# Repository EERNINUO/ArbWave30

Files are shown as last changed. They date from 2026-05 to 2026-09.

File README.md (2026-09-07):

<div align="center">

<!-- Assisted-by: DeepSeek - 文档框架 -->

# ArbWave30
30MHz 任意波形发生器 | FPGA + 高速DAC | SCPI 可控 

<p align="center">
  <a href="https://github.com/EERNINUO/ArbWave30" style="margin: 2px;">
    
  </a>
  <a href="https://github.com/EERNINUO/ArbWave30" style="margin: 2px;">
    
  </a>
  <a href="https://github.com/EERNINUO/ArbWave30" style="margin: 2px;">
    
  </a>
  <br/>
  <a href="https://raw.githubusercontent.com/EERNINUO/ArbWave30/main/LICENSE" style="margin: 2px;">
    
  </a>
  <a href="https://raw.githubusercontent.com/EERNINUO/ArbWave30/main/LICENSE" style="margin: 2px;">
    
  </a>
    <a href="https://raw.githubusercontent.com/EERNINUO/ArbWave30/main/LICENSE" style="margin: 2px;">
    
  </a>
  <!-- <a href="https://github.com/EERNINUO/ArbWave30/releases" style="margin: 2px;">
    <img src="https://img.shields.io/github/v/release/EERNINUO/ArbWave30?color=blueviolet&include_prereleases" alt="发布版本">
  </a> -->
</p>
</div>

---

> **⚠️ 注意**：你当前查看的是 **develop** 开发分支，内容可能不稳定。
> 推荐使用稳定发布版本：[查看 Releases](https://github.com/EERNINUO/ArbWave30/tree/releases)

## ✨ 特性

### 硬件指标（V1.0）
- 波形：正弦、方波、三角波、噪声波、直流
- 正弦波最高 **30MHz**，方波最高 **5MHz**
- 电压范围（高阻）：20Vpp（DC\~10MHz），14Vpp（10\~20MHz），10Vpp（20\~30MHz）
- 幅值分辨率：2mV（典型），偏移范围 ±10V
- 总谐波失真（THD）：< -50dBc @10MHz 满幅（目标值）
- 相位噪声：-100dBc/Hz @10kHz offset（30MHz 载波）（目标值，受限于测试条件，目前无法标定）
- 输出阻抗：50Ω
- 参考时钟：内部 TCXO（±1ppm）或外部 10MHz 输入

### 控制与接口
- USB 2.0（USB CDC 类），支持 SCPI-1999 命令集
- SMA 输出，SMA 触发 I/O，SMA 外部时钟输入
- 电源输入：24V DC，功耗 <24W

### 软件与扩展路线
- V1.0：单通道 + 基础波形 + 核心 SCPI
- V2.0：双通道 + 调制 + 扫频
- V3.0：Linux GUI + 任意波（16kpts）

---

## 🚦 项目状态

> **当前阶段：MVP 硬件、MCU/FPGA 核心程序验证完成，已能通过 SCPI 控制输出，正在进行模拟前端进一步调优**

### ✅ 已完成
- [x] PCB 设计与打样（4层板，信号完整性设计）
- [x] 模拟前端调试通过 
- [x] DAC 上电参数配置正常（SPI 接口通信稳定）
- [x] 正弦 DDS 核（IP 核实现，48位相位累加器）
- [x] 方波/直流/三角波/噪声波生成
- [x] 幅度控制模块
- [x] 相位控制模块
- [x] SPI Slave 通信接口与寄存器组
- [x] 模拟板驱动库（MCU 端）
- [x] SCPI 协议栈移植
- [x] 7阶椭圆滤波器焊接调试
- [x] 输出性能粗略标定（THD、SFDR）

### 🏗️ 开发中
- [ ] 软件幅度校准
- [ ] 谐波性能优化

### 📋 待办（MVP 之后）
- [ ] 滤波器性能优化（重构滤波器，调整群延时，减少快速边沿的过冲/振铃）
- [ ] 模拟板完整版设计（加入 硬件幅度控制、直流偏置、外部触发、外部时钟输入）
- [ ] 输出性能精确标定（需要专业频谱仪，目前无法进行）
- [ ] 上位机控制软件

### 📸 当前进展

**正弦波输出（SDS824X HD 示波器实测）：**

**正弦波满幅输出波形：**
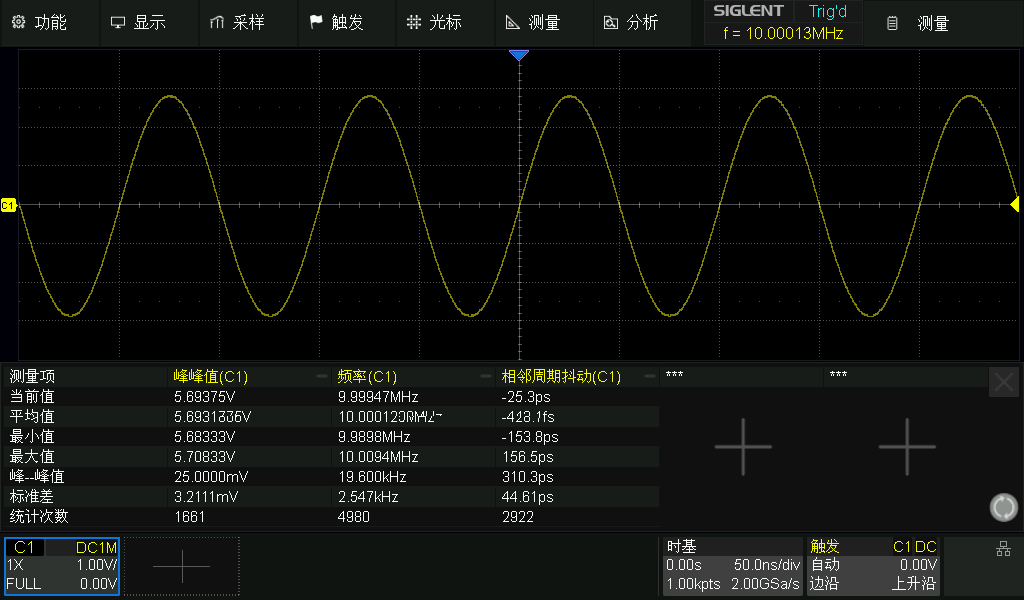
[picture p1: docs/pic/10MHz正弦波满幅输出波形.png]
10MHz正弦波满幅输出波形

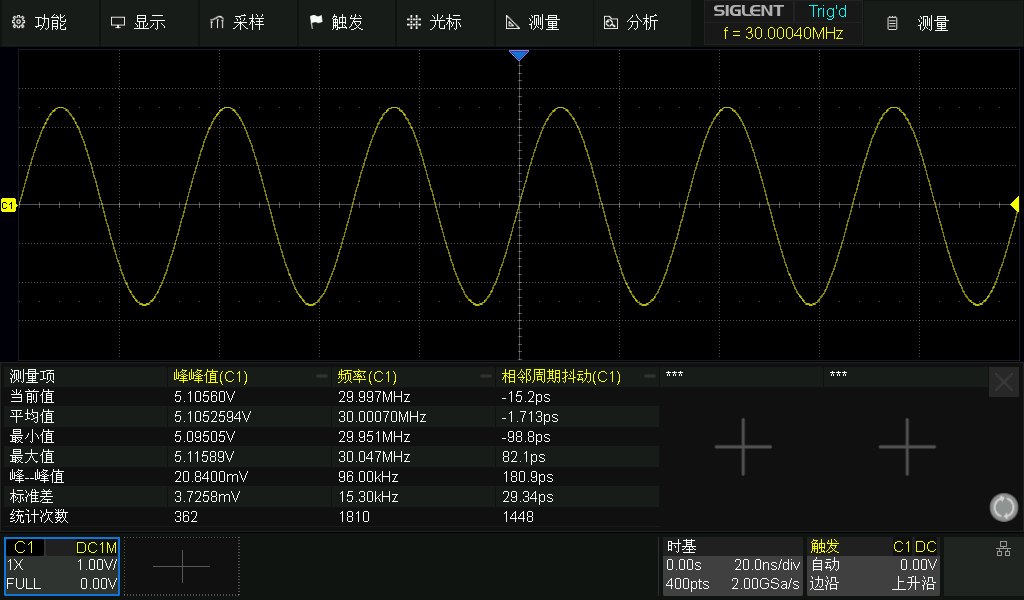
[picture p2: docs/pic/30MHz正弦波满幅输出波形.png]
30MHz正弦波满幅输出波形


**方波满幅输出波形：**
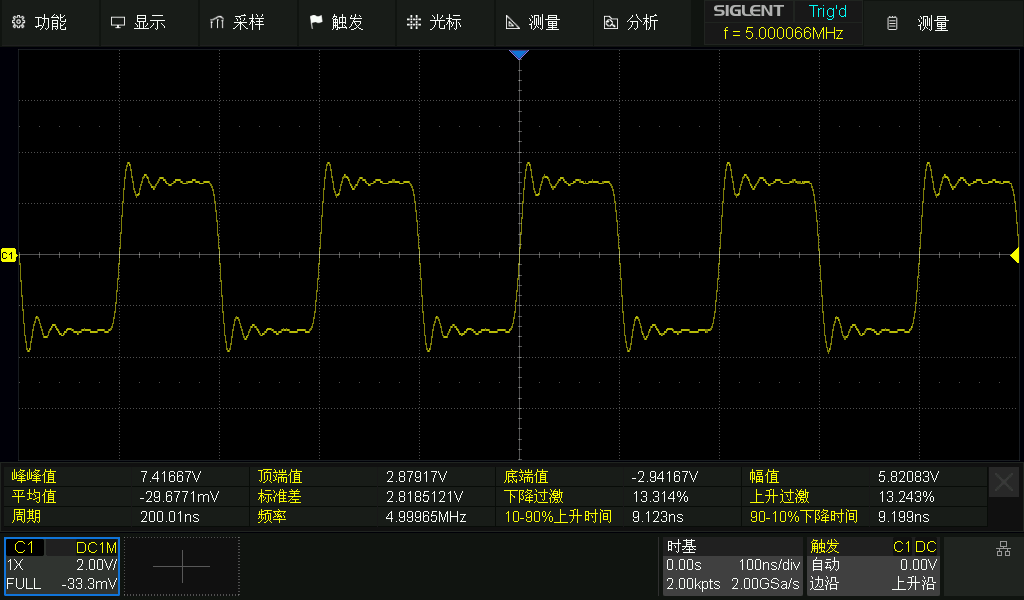
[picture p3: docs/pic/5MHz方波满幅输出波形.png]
5MHz方波满幅输出波形

> 当前版本方波有约 13.5% 的过冲，为滤波器群延时特性所致，后续将通过优化通道设计解决，详见[重构滤波器调试笔记](docs/设计笔记/重构滤波器调试笔记.md)。

**10MHz正弦波FFT结果：**

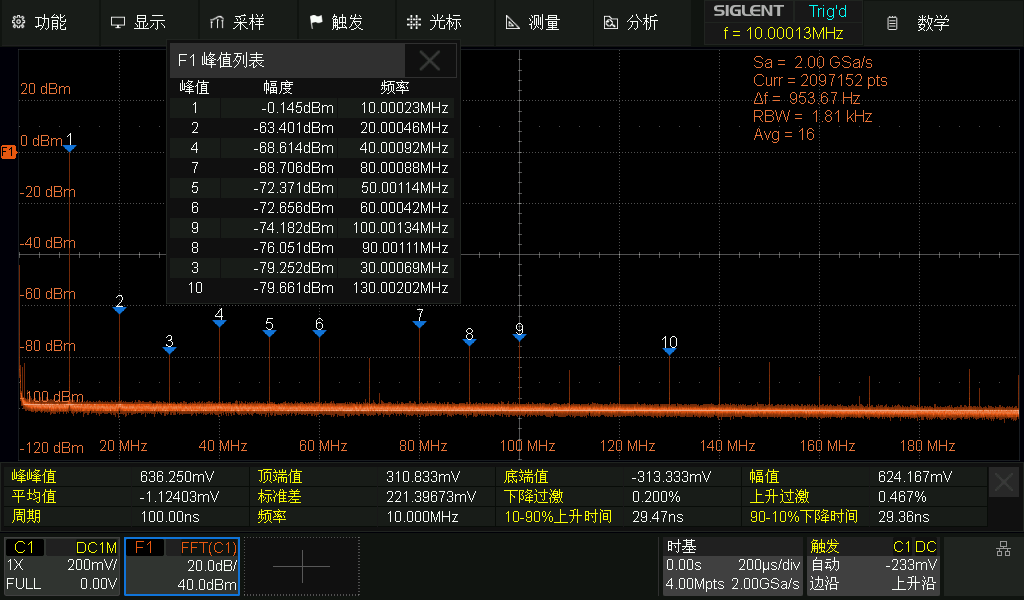
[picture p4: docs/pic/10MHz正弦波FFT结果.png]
10MHz正弦波FFT结果


经上图数据可计算出[^1]：
  THD ≈ -60.2 dBc @10MHz，
  SFDR[^2] ≈ 63.26 dBc @10MHz

[^1]: 由于示波器自身产生的谐波不可忽略，该值仅供参考，实际值需频谱分析仪复测。

[^2]:SFDR 分为两种定义：1、含谐波；2、不含谐波。由于表中没有非谐波分量，故采用第一种定义。

---

## 🧱 仓库结构
```text
ArbWave30/  
├── docs/ # 设计文档  
│    ├── pic/ # 文档图片  
│    ├── adr/ # 决策记录  
│    ├── 硬件设计文档/ # 硬件设计文档  
│    ├── 设计笔记/ # 设计笔记
│    ├── 用户手册/ # 用户手册  
│    └──  LICENSE # CC BY-SA 4.0  
├── hardware/ # 原理图、PCB源文件 （🚧 开发中）   
│    ├── analog_board/ # 模拟板 PCB设计  
│    ├── control_board/ # 控制板 PCB设计  
│    └── LICENSE # CERN-OHL-S-2.0   
├── firmware/ （🚧 开发中）   
│    ├── fpga/ # FPGA 设计源代码（Verilog）  
│    │    ├── Application/ # 项目代码   
│    │    └── FPGA_Test_Hardware/ # FPGA 硬件测试代码   
│    │         ├── FPGA_Clock_Test/ # 时钟测试代码   
│    │         └── FPGA_Hardware_Test/ # FPGA 硬件测试代码   
│    ├── mcu/ # MCU 固件源代码（C/C++）   
│    │    ├── Application/ # 项目代码   
│    │    ├── MCU_Test_Hardware/ # MCU 硬件测试代码   
│    │    │    └── min_system_test/ # MCU 最小系统测试代码   
│    │    └── SCPI_Test/ # SCPI-parser 移植测试工程   
│    └── Clock_Generator_Config/ # 时钟发生器配置     
├── simulink/ # LTspice 仿真文件  
├── datasheets/ # 组件数据手册，参考设计  
├── scripts/ # 自动化测试脚本（PyVISA）（🚧 开发中）  
│    ├── test_filter/ # 滤波器测试脚本  
│    └── test_diff_to_single # 差分转单端输出测试脚本   
├── LICENSE # GPL-3.0  
└── README.md  
```
---

## 🚀 快速开始

> 项目处于 **最小可行产品（MVP）验证阶段**，正在进行软硬件联调，待 MVP 验证完成后，将提供：
> - 打样 PCB 的 Gerber 文件及 BOM
> - FPGA 比特流烧录方法（通过 JTAG 加载）
> - 固件编译与升级步骤

当前你可以浏览 `docs/` 中的设计文档，了解详细的技术规格和设计思路；
或查看 `hardware/` 中的原理图和 PCB 设计文件与 `firmware/` 中的代码框架，了解硬件与软件的构成，并提出您的宝贵意见。

---

## 📡 SCPI 命令示例 

```python
import pyvisa

# 1. 指定纯 Python 后端（无需安装 NI-VISA 驱动）
rm = pyvisa.ResourceManager('@py')

# 2. 列出所有资源，找到你的 COM 口（通常是 'ASRL3::INSTR' 类似格式）
# print(rm.list_resources())

# 3. 打开串口资源，并配置终止符
inst = rm.open_resource('ASRL3::INSTR')  # 请替换为实际的 ASRL 端口号
inst.baud_rate = 115200        # 串口波特率，对于 USB CDC 类设备并不重要
inst.read_termination = '\n'   # 非常重要：库默认是 '\n'，但最好显式声明
inst.write_termination = '\n'  # 发送时自动追加换行符

# 4. 现在你可以像用 USBTMC 仪器一样使用 query
print(inst.query('*IDN?'))
inst.write('SOUR:FREQ 1000')
inst.write('SOUR:STAT ON')

# 5. 查询
freq = inst.query('SOUR:FREQ?')
print(f"Freq: {freq}")

inst.close()
```

完整命令集参见 [docs/SCPI_reference.md](</docs/用户手册/SCPI 参考手册.md>)。

## 🧪 自动化测试
测试脚本位于 `scripts/`（持续更新中），使用 PyVISA 与设备通信。你可以运行对应的脚本进行自动化测试，或者根据你的需求，参考这些脚本自行编写测试用例。

## 📄 文档
设计文档、测试报告和用户手册位于 `docs/`，持续更新中。

## 📅 版本路线图 
| 阶段 | 功能 | 描述 |
|---|---|---|
| V1.0 | 单通道，基础波形（正弦、方波、三角、噪声、DC）| 支持频率、幅值、偏置、相位连续可调；支持SCPI命令（少量核心指令）|
| V2.0 | 双通道 | 增加第二路输出，支持频率/相位同步，相位差可调 |
| | AM调制 |内/外部调制源，调制深度0\~100% |
| V3.0 | 嵌入式GUI | 基于Linux + LVGL，通过LCD触摸屏直接控制
| | 任意波 | 支持用户自定义波形表，存储深度≥16kpts |

## 📜 许可证
Copyright © 2026 EERNINUO

本项目采用**多许可证策略**，不同部分适用不同许可证：

| 组成部分 | 许可证 |
|---|---|
| 固件 （MCU/FPGA 代码） | [GNU General Public License v3.0](LICENSE) |
| 硬件设计文件 （原理图、PCB、BOM） | [CERN Open Hardware Licence Version 2 - Strongly Reciprocal](hardware/LICENSE) |
| 文档、图片、README | [Creative Commons Attribution-ShareAlike 4.0 International](docs/LICENSE) |

这意味着：
- 你可以自由使用、修改、分享固件代码，但任何衍生代码也必须以 GPL-3.0 开源。
- 你可以基于硬件设计文件制作、分发物理设备，但必须同时开源你对设计文件的修改，并保留署名。
- 你可以复制和修改文档，但必须同样以 CC BY-SA 4.0 分享，并注明原作者。

**商标声明**：`ArbWave30` 名称及标志未经授权不得用于商业产品。

## 🤖 AI 辅助声明

本项目文档框架由 GitHub Copilot / DeepSeek 辅助生成。
作者已逐一审查并测试，但如有任何问题欢迎提交 Issue。

## ⚠️ 免责声明
注意：本项目为个人学习与开源作品，不保证商业级可靠性。使用前请仔细阅读免责声明。

## 📫 联系方式
项目主页: https://github.com/EERNINUO/ArbWave30

## ⭐ Star History
如果您觉得这个项目有帮助，请给一个 Star ⭐，谢谢！

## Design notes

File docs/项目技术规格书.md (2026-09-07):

<!------------------------------------------------------------------------
SPDX-License-Identifier: CC-BY-SA-4.0
Copyright (C) 2026 [EERNINUO]

This work is licensed under the Creative Commons Attribution-ShareAlike 4.0 International License. 
To view a copy of this license, visit http://creativecommons.org/licenses/by-sa/4.0/.
------------------------------------------------------------------------->

<!-- Assisted-by: DeepSeek - 文档框架 -->

# ArbWave30 - 技术规格书

| 文档编号 | ArbWave30-SRS-001 | 版本 | V1.2 |
|---|---|---|---|
| 项目名称 | ArbWave30 | 日期 | 2026-04-06 |
| 起草人 | EERNINUO | 状态 | 草案 |

## 1. 概述
本设备是一款基于高云FPGA和高速DAC的数字合成信号源，为解决作者在学习实践中缺少高速信号源的问题而启动，旨在提供高精度、宽带宽的可编程波形输出。支持USB远程控制，并可扩展外部参考时钟输入，适用于实验室测试、教学演示及嵌入式系统调试等场景。

## 2. 引用文档与标准

|文档/标准 | 编号 |	说明 |
|---|---|-----|
| SCPI标准	| SCPI-1999 |	可编程仪器标准命令集 |
| USB设备类 | USB TMC 1.0 | USB-TMC协议 |
| IEEE 488.2 | IEEE Std 488.2-1992	| 仪器响应格式 |

## 3. 电气参数（电气规格表）

### 3.1  输出特性（主通道）

| 参数 | 符号 | 最小值 | 典型值 | 最大值 | 单位 | 条件/备注 |
|---|---|---|---|---|---|---|
| **波形类型** | – | 正弦、方波、三角波、噪声波、直流 | – | – | – | 后续固件升级支持任意波 |
| **正弦波最大频率** | f_sine_max | – | – | 30 | MHz | – |
| **方波最大频率** | f_sqr_max | – | – | 5 | MHz | 上升/下降时间 < 50ns |
| **其他波形最大频率** | f_other_max | – | – | 5 | MHz | 三角波、噪声波 |
| **频率分辨率[^1]** | Δf | – | 1 | – | μHz |  |
| **频率精度** | – | – | ±1 | – | ppm | 24小时内，基准为温补晶振（TCXO） |
| **相位噪声** | L(f) | – | -100 | – | dBc/Hz | @10kHz偏移，30MHz载波，目标值 |
| **总谐波失真** | THD | – | -55 | -50 | dBc | f_sine ≤ 10MHz，满幅输出 |
| **无杂散动态范围** | SFDR | – | 65 | – | dBc | f_sine ≤ 30MHz，> 1MHz时 < 60dBc |
| **输出噪声RMS** | V_noise | – | < 3 | – | mV RMS | 0V输出，DC~30MHz 50Ω负载 |

[^1]: 频率分辨率指DDS模式下的最小频率步进，实际频率精度受时钟稳定性影响。

### 3.2 幅值与分辨率（高阻输出模式）

| 频率范围 | 幅值范围[^2]（Vpp） | 最大偏移量[^3] | 分辨率 | 绝对精度 |
|---|---|---|---|---|
| DC ~ 10 MHz | 0 ~20 | ±10 V | 2 mV（典型，最差 5 mV） | ±（1% + 2mV） @1kHz |
| 10 MHz ~ 20 MHz | 0 ~ 14 | ±7 V | 2 mV（典型，最差 5 mV） | ±（2% + 2mV） |
| 20 MHz ~ 30 MHz | 0 ~ 10 | ±5 V | 2 mV（典型，最差 5 mV） | ±（2% + 2mV） |

[^2]: 50Ω下幅值范围为高阻状态下的1/2
[^3]: 注意，偏置电压加上幅值需小于对应频率下0偏置时的最大幅值

### 3.3 方波特性（高阻，5MHz）

| 参数 | 目标值 | 单位 |
|---|---|---|
| 上升/下降时间 （10% ~ 90%） | < 50 | ns |
| 过冲（目标） | < 5 | % |
| 抖动 （RMS）（目标） | < 500 | ps |

### 3.4 扫描与调制（后续实现）

| 功能 | 参数 | 目标 |
|---|---|---|
| 线性/对数扫频 | 起始/终止频率 | 1μHz ~ 30MHz |
| AM调制 | 调制频率 | 1Hz ~ 100kHz，调制度0~100% |

### 3.5 时钟特性

| 参数 | 典型值 | 幅度 | 备注 |
|---|---|---|---|
| 内部参考频率 | 10 MHz | \ | TCXO，初始精度 ±1ppm，老化 ±1ppm/年 |
| 外部参考输入 | 10 MHz | 3.3V | ±10ppm，0~10dBm，SMA接口 |
| 参考输出 | 10 MHz | 3.3V | LVCMOS33，SMA |

### 3.6 触发输入/输出

| 参数 | 幅度 | 备注 |
|---|---|---|
| 多功能输入 | 3.3V/5V兼容 | SMA |
| 多功能输出 | 3.3V | SMA |

### 3.7 电源与环境

| 参数 | 规格 |
|---|---|
| 直流输入电压 | 24 V DC |
| 功耗 | < 20 W（预估） |
| 工作温度 | 0 ~ 40 ℃ |
| 存储温度 | -20 ~ 70 ℃ |
| ESD防护 | 接触放电 ±4 kV（输出BNC加TVS） |

## 4. 功能要求

### 4.1 基础功能
- 产生正弦、方波、三角波、噪声波、直流
- 可设置频率、幅值、偏移、相位
- 支持输出开关（ON/OFF），断电后恢复最后设置（存储于EEPROM）

### 4.2 调制与扫频（V2版本实现）
- AM：内/外调制，调制频率/深度可设
- 线性/对数频率扫描

### 4.3 任意波功能（V2版本实现）
- 用户自定义波形点数：最大 16kpts（14bit分辨率）
- 通过上位机软件或SCPI命令下载波形数据

### 4.4 外部接口
- USB 2.0（USBTMC或CDC类）用于远程控制和波形数据传输
- 波形输出：SMA接口，50Ω/高阻切换
- 外部参考时钟输入（10 MHz，SMA接口）
- 触发输入/输出（SMA）
- 电源输入（DC2.1mm 24~36 V）
- 可选：LAN接口（后续实现）

### 4.5 远程控制（#远程控制）
- 接口：USB 2.0 （USB-CDC类）
- 命令集：符合SCPI-1999标准，至少包含以下子系统：
  - `*IDN?`, `*RST`, `*CLS`
  - `SOURce`：FREQuency, VOLTage, VOLTage:OFFSet, FUNCtion, PHASe
  - `OUTPut`：STATe, IMPedance, LOAD
  - `TRIGger`：SOURce, SLOPe
  - `SYSTem`：ERRor?
  - `SOURce`:TRACe:DATA?
- 响应格式：`<header><value><terminator>`，支持查询与设置

### 4.6 用户界面（长期扩展）
- 可选：通过USB连接PC运行简易GUI（Python+PyQt）
- 可选：后续移植至Linux板卡（运行本地GUI）

## 5. 硬件架构要求

### 5.1 主要IC选型（初步）
| 模块 | 型号 | 关键参数 | 功能说明 |
|---|---|---|---|
| FPGA | 高云GW2AR-LV18 | 逻辑资源 > 20k LUTs，支持PLL | DDS核心，时钟管理，数据处理 |
| MCU | STM32F411 | 32位ARM Cortex-M4处理器, 96MHz主频 | 系统控制，USB通信，用户接口 |
|时钟发生器| CDCI6214 | 4输出，支持外部参考 | 提供DAC时钟和系统时钟 |
| DAC | AD9747 | 16bit, 最大250MSPS, 双通道 | 波形生成核心，支持高精度输出 |
| 重构滤波器 | 7阶椭圆LPF | 截止频率60MHz，通带纹波<0.5dB | 滤除DAC采样频率成分，改善波形质量 |
| 差分放大器 | LMH6609 | 电流反馈运算放大器、带宽>410MHz | 差分转单端 |
| 衰减网络 | 精密电阻、信号继电器 | 电阻精度<0.1% | 根据频率自动调整增益，实现幅度分段控制 |
| 输出功率级 | THS3095 |  | 驱动±10V@1MΩ负载 |

### 5.2 PCB要求
- 层数：≥4层（信号-地-电源-信号）
- 模拟板（FPGA+DAC）与控制板（STM32）分离，通过SPI接口连接
- DAC时钟线差分对（或单端包地），严格控制阻抗（50Ω）
- 模拟电源由LDO单独供电

## 6. 开发计划

| 阶段 | 功能 | 描述 |
|---|---|---|
| V1.0 | 单通道，基础波形（正弦、方波、三角波、噪声波、DC）| 支持频率、幅值、偏置、相位连续可调；支持SCPI命令（少量核心指令）|
| V2.0 | 双通道 | 增加第二路输出，支持频率/相位同步，相位差可调 |
| | AM调制 |内/外部调制源，调制深度0~100% |
| V3.0 | 嵌入式GUI | 基于Linux + LVGL，通过LCD触摸屏直接控制
| | 任意波 | 支持用户自定义波形表，存储深度≥1Mpts |

## 7. 验收测试方法

| 参数 | 测试仪器 | 测试方法简述[^4] | 允差 |
|---|---|---|---|
| 最大频率 | Siglent SDS824X | 正弦波30MHz，测量周期 | ±0.1% |
| 幅值精度 | Siglent SDS824X | 1kHz正弦，比较设定值与实测值 | 见3.2节 |
| THD | SDS824X （FFT模式） | 10MHz正弦，计算谐波功率 | ≤ -50dBc |
| 上升时间 | Siglent SDS824X | 方波5MHz，测量10%-90% | < 50ns |
| 频率精度 | Siglent SDS824X | 10MHz输出，24小时内漂移 | ±1ppm |
| 输出平坦度 | Siglent SDS824X | 10MHz正弦，测量0.1MHz~10MHz范围内的幅值变化 | < ±0.5dB|
| 抖动 （RMS） | SDS824X + 长时采集（>1000边沿） | 5MHz方波，测量边沿时间偏差标准差 | < 200 ps RMS |
| SCPI兼容 | PC + PyVISA | 发送`*IDN?`，校验返回格式 | 必须通过 |
| 相位噪声 | 需要低相噪频谱仪 | - | 受限于测试条件，目前无法标定 |

[^4]: 测试时使用SMA->BNC短电缆，通过50Ω阻抗匹配器连接示波器，示波器开启全带宽。

## 8. 参考文献

1. SDG1000X 数据手册（鼎阳科技）
2. AD9747 数据手册（ADI）
3. THS3091 数据手册（TI）
4. 高云半导体 GW2A 系列数据手册
5. 《信号完整性与电源完整性》（Joe Hogue）
6. 《数字信号处理》（John G. Proakis）
7. 《Op Amps for Everyone》（TI）

## 9. 版本记录

| 版本 | 日期 | 修改内容 | 修改人 |
|---|---|---|---|
| V1.0 | 2026-03-01 | 初始版本 | EERNINUO |
| V1.1 | 2026-04-05 | 更新技术规格参数，调整测试方法 | EERNINUO |
| v1.2 | 2026-04-06 | 更改电源规格 | EERNINUO |
| v1.3 | 2026-04-23 | 添加多功能I/O特性 | EERNINUO |
| v1.4 | 2026-04-30 | 更换 DAC | EERNINUO |

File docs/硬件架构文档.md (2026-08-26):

<!------------------------------------------------------------------------
SPDX-License-Identifier: CC-BY-SA-4.0
Copyright (C) 2026 [EERNINUO]

This work is licensed under the Creative Commons Attribution-ShareAlike 4.0 International License. 
To view a copy of this license, visit http://creativecommons.org/licenses/by-sa/4.0/.
------------------------------------------------------------------------->

<!-- Assisted-by: DeepSeek - 文档框架 -->

# ArbWave30 硬件架构文档

| 文档编号 | ArbWave30-HAD-001 | 版本 | V1.6 |
|---|---|---|---|
| 项目名称 | ArbWave30 | 日期 | 2026-05-26 |
| 起草人 | EERNINUO | 状态 | 草案 |

## 1. 概述
ArbWave30采用**FPGA + MCU异构架构**：FPGA负责高速DDS波形生成与实时数据处理，MCU负责USB通信、SCPI解析、人机交互与系统状态管理。模拟前端分为差分转单端、重构滤波、可变增益放大、功率输出四级。数字与模拟部分采用分板设计（通过板对板连接器连接），以优化信号完整性与电源噪声。

## 2. 系统框图
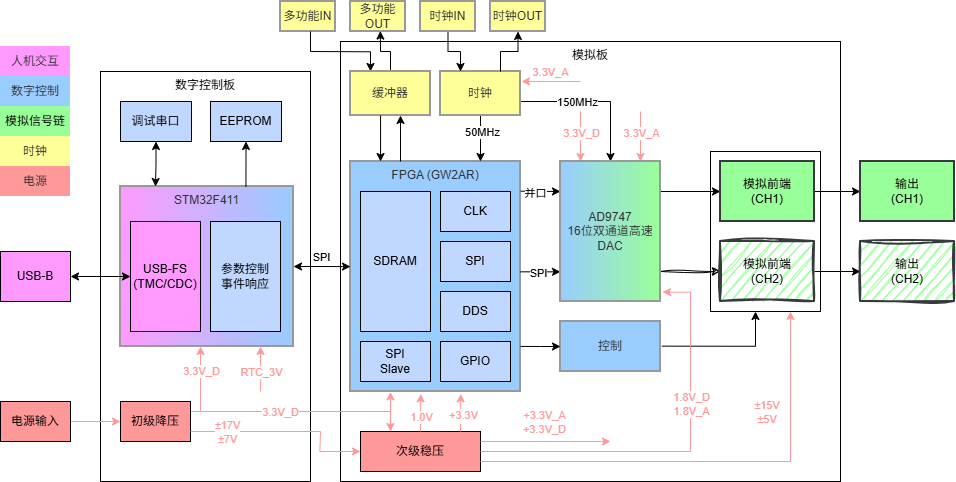
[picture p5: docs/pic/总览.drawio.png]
总览


## 3. 模块划分与功能定义

### 3.1 控制模块（MCU）（数字板）
- **型号**：STM32F411（暂定）
- **职责**：
  - USB TMC/CDC 协议栈
  - SCPI 命令解析与响应
  - 非实时参数存储（EEPROM模拟）
  - 控制FPGA（频率、波形、幅度系数、相位等）
  - 读取用户按键/编码器（未来GUI）
- **接口**：

| 接口名 | 方向 | 协议 | 连接到 | 备注 |
|---|---|---|---|---|
| USB_DP/DM | 双向 | USB 2.0 FS | PC | CDC或TMC |
| SPI1_CS/SCK/MOSI | 输出 | SPI | FPGA | 配置DDS参数 |
| INT | 输入 | GPIO | FPGA | FPGA状态/中断输出 |
| GPIO | 输出 | GPIO | 蜂鸣器、LED | 调试用 |
| UART_TX/RX | 输出 | 115200 | 调试串口 | - |
| IIC_SDA/SCL | 双向 | I2C | EEPROM | 存储配置数据 |

### 3.2 波形合成模块（FPGA + DAC）（模拟板）{#3.2_波形合成模块}
- **FPGA**：高云 GW2AR-LV18 （LQFP-144）
- **职责**：
  - DDS 相位累加器（48bit，满足1μHz分辨率）
  - 波形存储器（ROM/RAM）：预置正弦、方波、三角波、噪声波、DC
  - 数字幅度控制（控制衰减网络与DAC输出的幅度）
  - 与DAC的并行接口时序产生
  - 频率/相位/幅度字实时更新（无毛刺）
- **DAC**：AD9747（16bit, 最大250MSPS（考虑到FPGA性能，降低到150MSPS使用）, 双通道，当前仅用通道A）
- **接口**：
  - DAC数据线：16×2条（双通道），从FPGA输出，等长布线
  - DCO时钟：从DAC输入，FPGA接收，越短越好
  - DAC时钟：由时钟发生器提供150MHz LVDS 通过AC耦合转换电路转换后输入DAC
  - DAC控制接口：SPI接口，由FPGA控制，控制DAC运行，控制辅助DAC
  - FPGA配置：SPI接口由MCU控制，支持在线更新DDS参数
  - FPGA程序配置：SPI Flash（外部），通过JTAG烧录

### 3.3 偏置发生模块（模拟板）
- **职责**：
  - 产生±2V 偏置电压用于粗调
  
- **关键要求**：
  - 偏置电压精度：±10mV
  - 偏置电压范围：±2V （经过末级放大后可至±10V）
  - **DAC**：AD9747 辅助DAC（10bit，双通道）
  - **运放**：OPA2197（轨到轨输出，低噪声，低功耗）

### 3.4 模拟前端（AFE）
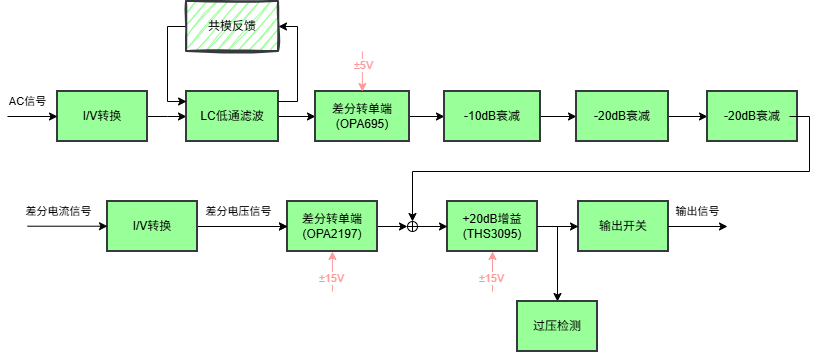
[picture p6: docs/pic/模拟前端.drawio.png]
模拟前端

| 级 | 功能 | 关键要求 | 信号最大摆幅 | 增益（V/V） | 初步选型 |
|----|---|---|---|--|---|
| 0 | DAC输出 | / | （差分电流输出） | / | AD9747 |
| 1 | 重构滤波器（低通） | 7阶椭圆LPF，截止60MHz，带内波动<0.5dB，115MHz抑制>60dB |  |  | 无源LC（设计值） | 
| 2 | 差分转单端 | 带宽 > 150MHz，低噪声 | 2Vpp |  | LMH6609 |
| 3 | 衰减网络 | 带宽 > 35MHz | 1Vpp |  | 0.1%精密电阻衰减网络（信号继电器控制） |
| 4 | 输出放大级 | SR > 2000V/us, 输出电流 > 200mA, 输出电压 > ±10V | 20Vpp | 10 | THS3095（电流反馈） |
| 5 | 共电位反馈 | 高精度、低噪声 | / | / | NE5532 |
| 6 | 偏置产生 | ±2V输出 | / | / | OPA2197 |

### 3.5 时钟电路
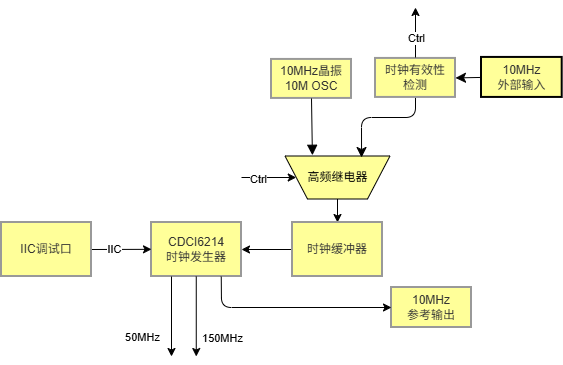
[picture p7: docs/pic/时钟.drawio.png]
时钟

- 本地振荡器：10 MHz TCXO，频率稳定度 ±1 ppm
- 时钟发生器：CDCI6214，RMS抖动 < 500 fs，支持外部参考输入
  - 输出 1：150 MHz LVDS 给 DAC 作为采样时钟
  - 输出 2：150 MHz LVDS 给 FPGA 内部时钟
  - 输出 3：10 MHz LVCMOS 参考输出
- 外部参考输入：SMA 端子，通过继电器切换内部 TCXO 或外部 10 MHz

### 3.6 电源系统 （初步设计）
- 输入：24V DC（TVS保护、防反接）[^1]。
- 电源架构：
```mermaid
graph TD
  subgraph 数字板
  Vin[DC_IN 24V] --> TVS[TVS/防反接]

  TVS -->|TPS54360| +17V_M[+17V_M]
  TVS -->|TPS54360_反向buck| -17V_M[-17V_M]
  TVS -->|TPS54360| +7V_M[+7V_M]  
  TVS -->|TPS54360_反向buck| -7V_M[-7V_M]  
  +17V_M -->|TPS62933| +3.3V_D[+3.3V_D]
  +3.3V_D[+3.3V_D]

  +3.0V_RTC[CR2032] --> STM32_RTC
  end

  subgraph 模拟板
    +17V_M -->|L7815| +15V_A[+15V_A]  
    -17V_M -->|L7915| -15V_A[-15V_A]  
    +7V_M -->|L7805| +5V_A[+5V_A]  
    -7V_M -->|L7905| -5V_A[-5V_A]  
    +5V_A -->|TPS7A4701| +3.3V_A[+3.3V超洁净电源，用于DAC、时钟、基准]
    +3.3V_A -->|TPS7A9101| +1.8V_A[+1.8V_A]

    +3.3V_D --> +3.3V_D_on_A_board[+3.3V_D]
    +3.3V_D_on_A_board -->|AMS1117| +1.8V_D[+1.8V_D]
    +17V_M -->|TPS62933| +1.0V_D[+1.0V_D]
  end
```

- 电源滤波与去耦：每个电压轨配备 LC 滤波器和多级旁路电容，单板内模拟与数字电源不分割[^2]，DAC和运放供电采用低噪声LDO。

[^1]: THS3095在±15V供电时输出电压摆幅为±12.1V，考虑到电压降和余量，建议输入电压不低于20V。后续可根据实际测试调整输入电压范围。

[^2]: 比起纠结是否分割不同的地平面，保证信号的回流路径才是关键。本设计中波形合成模块（模拟板）上数字信号频率较高，因此信号回流基本沿着信号线下方，通过地平面回流到电源输入端，模拟电源和数字电源共用一个地平面，能确保回流路径短且连续，如果分割地平面破坏了回流路径，使得信号回流绕行，反而可能增加噪声和干扰。

### 3.7 接口与连接器
- USB：Micro-B，连接 STM32
- 波形输出：SMA，并联 50Ω/高阻继电器
- 外部 10M 输入：SMA，3.3V 电平
- 10M 参考输出：SMA，3.3V LVCMOS
- 多功能输出：SMA，3.3V 电平，通过74HCT125缓冲与电平转换
- 多功能输入：SMA，3.3V/5V 兼容，通过74HCT125缓冲
- 电源输入：2.5mm 插孔，反接保护

### 3.8 分板设计与板间接口
为实现最优信号完整性和电源噪声隔离，ArbWave30 采用双板分离架构：模拟板承载高速混合信号链路（FPGA、DAC、模拟前端），控制板负责低速数字逻辑与外部通信（MCU、USB、电源输入、触发 I/O）以及电源的初步调理，两板电源轨相互独立，连接到同一个电源输入。两板之间通过连接器相连。

#### 3.8.1 分板理由
| 考量因素 | 分板优势 |
|---|---|
| 电源噪声 | 模拟板上的 DAC 和运放对电源纹波极其敏感（要求 < 50µV），控制板上的 DC-DC 和数字逻辑会产生高频开关噪声，物理分离可显著降低耦合。|
| 信号完整性 | FPGA 与 DAC 之间的 16 位并行数据（150MHz）对 PCB 布局等长要求高，独占一板可保证最短、最可控的走线。|
| 调试与测试	| 两块板可独立上电调试，先验证数字通信与 DDS，再联调模拟前端，降低故障定位难度。|
| 复用性 | 未来升级任意波或双通道时，只需修改模拟板（如增加第二路 DAC），控制板可保持不变。|

#### 3.8.2 功能划分
| 板卡 | 包含模块 | 职责 |
|---|---|---|
| 控制板 | STM32F411、USB 接口、电源输入（20~36V）及初级 DC-DC、触发 I/O、EEPROM、前面板按键预留 | SCPI 解析、USB 通信、系统状态管理、模拟板配置、电源转换 |
| 模拟板	| FPGA（GW2AR）、DAC（AD9747）、时钟发生器（CDCI6214）、模拟前端、衰减网络、固定增益放大、输出继电器 | DDS 波形合成、DAC 时序、模拟信号调理、波形输出 |

#### 3.8.3 连接器与机械布局
- 连接器类型：2×8 针牛角座，镀金防氧化。

#### 3.8.4 接地策略

- 控制板与模拟板共地。
- 所有板内信号线不跨接地平面缝隙，确保回流路径连续。

## 4. 关键接口信号定义

| 接口 | 信号 | 方向 | 电平 | 说明 |
|---|---|---|---|---|
| SPI （MCU <-> FPGA） | CLK, CS, MOSI, MISO | 双向 | 3.3V | 配置波形参数、DDS频率字 |
| INT （FPGA -> MCU） | FPGA_INT | FPGA输出 | 3.3V | FPGA状态/中断输出 |
| 主 DAC 接口 （FPGA -> DAC） | D[15:0], DCO | FPGA输出 | 3.3V | 并行数据 |
| DAC 控制接口 （FPGA -> DAC） | SCLK, MOSI, CS | FPGA输出 | 3.3V |  |
| 控制信号 （FPGA -> 继电器） |  | FPGA输出 | 3.3V | 通过三极管驱动 |

## 5. 电源预算与噪声要求（初步）

#### 模拟板
| 电压轨 | 预估最大电流 | 允许纹波 （峰峰值） | 主要负载 |
|---|---|---|---|
| +15V | 500mA | 2mV | 输出功率级正电源 |
| -15V | 500mA | 2mV | 输出功率级负电源 |
| +5V_A | 360mA | 500uV | 运放正电源、后级+3.3V_A |
| -5V_A | 160mA | 500uV | 运放负电源 |
| +3.3V_A | 200mA | 100uV | TCXO、时钟发生器、精密基准源、DAC模拟电源、1.8V_A |
| +3.3V_D | 450mA | 50mV | DAC数字电源、FPGA IO、模拟前端继电器、1.8V_D |
| +1.8V_A | 30mA | 100uV | DAC时钟电源 |
| +1.8V_D | 40mA | 30mV | DAC数字电源 |
| +1.0V | 1A | 30mV | FPGA 内核 |

#### 控制板
| 电压轨 | 预估最大电流 | 允许纹波 （峰峰值） | 主要负载 |
|---|---|---|---|
| +17V | 800mA | 70mV | 模拟板正电源 |
| -17V | 600mA | 70mV | 模拟板负电源 |
| +7V | 800mA | 70mV | 模拟板正电源 |
| -7V | 500mA | 70mV | 模拟板负电源 |
| +3.3V_D | 500mA | 50mV | STM32 |
| +3.0V_RTC | 2uA | 50uV | STM32 RTC | 

## 6. 物理与机械约束
- PCB 尺寸：最大 100mm × 100mm
- 连接器布局：SMA 间距 20mm，USB 位于板边
- 散热：
  1. THS3095 底部加过孔阵列并连接至底层铜皮
  2. FPGA 加散热片
  3. LDO（CJ78/ CJ79）酌情加散热片
  4. DCDC部分酌情加散热片
  5. v1.0 采用开放式机箱，暂时不用考虑散热问题

## 7. 下一步工作
- 编写硬件设计文档（原理图设计说明、PCB 布局指南）
- 开始 LTSpice 仿真

## 8. 版本记录

| 版本 | 日期 | 修改内容 | 修改人 |
|---|---|---|---|
| V1.0 | 2026-04-06 | 初始架构 | EERNINUO |
| V1.1 | 2026-04-20 | 添加电源系统初步设计，添加系统框图，完善模拟前端 | EERNINUO |
| V1.2 | 2026-04-21 | 添加时钟模块设计 | EERNINUO |
| V1.3 | 2026-04-23 | 添加多功能I/O特性，完善板间接口定义 | EERNINUO |
| V1.4 | 2026-04-30 | 更换 DAC | EERNINUO |
| V1.5 | 2026-05-05 | 完善电源设计 | EERNINUO |
| v1.6 | 2026-05-26 | 修改电源引脚分配，将 ±7V 生成移至控制板| EERNINUO |
| v1.7 | 2026-08-07 | 补充对板间接口的修改 | EERNINUO |

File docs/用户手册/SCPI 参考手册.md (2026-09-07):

<!------------------------------------------------------------------------
SPDX-License-Identifier: CC-BY-SA-4.0
Copyright (C) 2026 [EERNINUO]

This work is licensed under the Creative Commons Attribution-ShareAlike 4.0 International License. 
To view a copy of this license, visit http://creativecommons.org/licenses/by-sa/4.0/.
------------------------------------------------------------------------->

<!-- Assisted-by: DeepSeek - 文档框架 -->

# ArbWave30 可编程仪器标准命令（SCPI）参考手册

| 文档编号 | ArbWave30-UM-002 | 版本 | V1.0 |
| --- | --- | --- | --- |
| 项目名称 | ArbWave30 | 日期 | 2026-08-17 |
| 编写人 | EERNINUO | 状态 | 初稿 |

## 1. 概述
本文档提供了 ArbWave30 任意波形发生器的远程控制命令集。该仪器遵循 **SCPI（Standard Commands for Programmable Instruments）1999.0 标准** 和 **IEEE 488.2-1992** 规范。

**通信接口**：
- **物理层**：USB 2.0（CDC 类虚拟串口）
- **波特率**：115200 bps （该参数对虚拟串口无实质影响）
- **数据位**：8，**停止位**：1，**校验位**：无
- **结束符**：`\n` （换行，十六进制 0x0A）

---

## 2. 语法约定

在阅读本手册时，请注意以下符号约定：

| 符号 | 含义 | 示例 |
| :--- | :--- | :--- |
| `[ ]` | 可选关键字或参数，可省略。 | `OUTPut[:STATe]` 表示 `OUTPut:STATe` 可缩写为 `OUTPut` |
| `{ }` | 必选参数组，从其中选择一个。 | `VOLTage {<amplitude>|MIN|MAX}` |
| `|` | 逻辑“或”分隔符。 | `ON|OFF` |
| `#` | 通道占位符。 | `SOURce#` 代表 `SOURce1` 或 `SOURce2` |
| `< >` | 用户必须替换的实际数值。 | `<frequency>` |
| `() )` | 命令的短格式（助记符），SCPI 引擎同时接受长格式和短格式。 | `FREQuency` (短格式: `FREQ`) |

**查询命令**：在命令末尾添加问号 `?` 可查询当前设定值，如 `FREQuency?`。

---

## 3. IEEE 488.2 通用命令

### 3.1 `*IDN?` —— 查询设备标识
**功能**：返回设备制造商、型号、固件版本和序列号。
**格式**：`*IDN?`
**响应**：`<厂商>,<型号>,<固件版本>,<序列号>`
**示例**：
> `*IDN?` -> `EERNINUO,ArbWave30,V1.0.0,SN123456`
> \# 注意：实际返回值可能因设备和固件版本而异。

### 3.2 `*RST` —— 设备复位
**功能**：将设备参数重置为出厂默认值。
**格式**：`*RST`
**默认参数**：
- 频率：0 Hz
- 波形：正弦波
- 幅值：0 Vpp
- 偏置：0 V
- 输出状态：关闭 （OFF）

### 3.3 `*CLS` —— 清除错误队列
**功能**：清空系统错误/事件队列。
**格式**：`*CLS`

## 4. `SOURce` 子系统（波形生成参数）

该子系统用于配置信号发生器核心的 DDS 参数。

### 4.1 频率设置 `[SOURce#:]FREQuency`

**描述**：设置或查询指定通道的输出频率。

**命令格式**：
`[SOURce#:]FREQuency {<frequency>|MIN|MAX}`
`[SOURce#:]FREQuency? [MIN|MAX]`

**参数说明**：
- `<frequency>`：浮点数，单位 Hz。
- `MIN`：最小值，0 Hz （0 Hz）。
- `MAX`：最大值，30,000,000 Hz （30 MHz）。
- 默认值：0 Hz。

**示例**：
- `SOURce1:FREQuency 1000000` -> 设置通道 1 频率为 1 MHz。
- `SOUR:FREQ MAX` -> 设置当前选中通道频率为 30 MHz（短格式）。
- `FREQuency?` -> 返回 `1000000.000000`。

### 4.2 波形类型与专属参数 `[SOURce#:]FUNCtion`

本组命令用于选择输出波形，并配置该波形的特有参数（如方波占空比）。

#### 4.2.1 `[SOURce#:]FUNCtion` —— 波形形状选择

**描述**：设置或查询当前通道的波形形状。

**命令格式**：
`[SOURce#:]FUNCtion {SINusoid|SQUare|TRIangle|NOIse|DC}`
`[SOURce#:]FUNCtion?`

**参数说明**：

| 参数 | 短格式 | 说明 |
| --- | --- | --- |
| `SINusoid` | `SIN` | 正弦波（默认） |
| `SQUare` | `SQU` | 方波（占空比可调，见 4.2.2） |
| `TRIangle` | `TRI` | 三角波 |
| `NOIse` | `NOI` | 噪声波 |
| `DC` | `DC` | 直流电平 |

**示例**：
- `SOUR:FUNC SIN` -> 选择正弦波。
- `SOUR:FUNC?` -> 返回当前波形类型（如 `"SIN"`）。

#### 4.2.2 `[SOURce#:]FUNCtion:SQUare:DCYCle` —— 方波占空比

**描述**：设置或查询方波的高电平时间占整个周期的百分比。**仅在波形为 `SQUare` 时有效**。

**命令格式**： 
`[SOURce#:]FUNCtion:SQUare:DCYCle {<percent>|MINimum|MAXimum}`
`[SOURce#:]FUNCtion:SQUare:DCYCle? [MINimum|MAXimum]`

**参数**：
- `<percent>`：浮点数，单位 %。
- 范围：0.01 % ~ 99.99 %（受限于硬件上升时间，极值可能无法达到理想的100%）。
- 默认值：50.00 %。

**示例**：
- `SOUR:FUNC:SQU:DCYC 30` -> 设置占空比为 30%。
- `SOUR:FUNC:SQU:DCYC?` -> 返回 `"30.00"`。

**错误处理**：
- 若当前波形不是方波（例如正弦波），执行此命令将返回错误 `-221,"Settings conflict"`。

#### 4.2.3 `[SOURce#:]FUNCtion:TRIangle:SYMMetry` —— 三角波对称度

**描述**：设置或查询三角波的对称度。**仅在波形为 `TRIangle` 时有效**。

**命令格式**：
`[SOURce#:]FUNCtion:TRIangle:SYMMetry {<percent>|MINimum|MAXimum}`
`[SOURce#:]FUNCtion:TRIangle:SYMMetry?`

**参数**：
- `<percent>`：浮点数，单位 %。
- 范围：0.01 % ~ 99.99 %（受限于硬件上升时间，极值可能无法达到理想的100%）。
- 默认值：50.00 %。

**示例**：
- `SOUR:FUNC:TRI:SYMM 75` -> 设置对称度为 75%。
- `SOUR:FUNC:TRI:SYMM?` -> 返回 `"75.00"`。

**错误处理**：
- 若当前波形不是三角波，执行此命令将返回错误 `-221,"Settings conflict"`。

### 4.2.4 `[SOURce[#]]:FUNCtion:NOISe:MEAN` —— 设置/查询噪声平均值

**描述**：设置或查询噪声信号的平均值（直流分量）。**仅在波形为 `NOISe` 时有效**。

**命令格式**： 
`[SOURce#:]FUNCtion:NOISe:MEAN {<mean>|MINimum|MAXimum}`
`[SOURce#:]FUNCtion:NOISe:MEAN? [MINimum|MAXimum]`

**参数**：
- `<mean>`：浮点数，表示噪声信号的平均值（直流分量），单位 V。
- 范围：
  - `MIN`：最小值，-10 V。
  - `MAX`：最大值，+10 V。
- 默认值：0 V。

**示例**：
- `SOUR:FUNC:NOIS:MEAN 0.5` -> 设置噪声平均值为 +0.5V。
- `SOUR:FUNC:NOIS:MEAN?` -> 返回 `"0.50"`。

**错误处理**：
- 若当前波形不是噪声波，执行此命令将返回错误 `-221,"Settings conflict"`。

### 4.2.5 `[SOURce[#]]:FUNCtion:NOISe:SDEViation` —— 设置/查询噪声标准差

**描述**：设置或查询噪声信号的标准差（衡量噪声的幅度）。**仅在波形为 `NOISe` 时有效**。

**命令格式**：
`[SOURce[#]]:FUNCtion:NOISe:SDEViation {<sdev>|MINimum|MAXimum}`
`[SOURce[#]]:FUNCtion:NOISe:SDEViation?`

**参数**：
- `<sdev>`：浮点数，表示噪声信号的标准差（衡量噪声的幅度），单位 V。
- 范围：
  - `MIN`：最小值，0 V 。
  - `MAX`：最大值，5.770 V 。
- 默认值：0 V。

**示例**：
- `SOUR:FUNC:NOIS:SDEV 2.5` -> 设置噪声标准差为 2.5V。
- `SOUR:FUNC:NOIS:SDEV?` -> 返回 `"2.50"`。

**错误处理**：
- 若当前波形不是噪声波，执行此命令将返回错误 `-221,"Settings conflict"`。

### 4.3 幅度设置 `[SOURce#:]VOLTage`

**描述**：设置或查询输出幅度（峰峰值 Vpp）。

**命令格式**：
`[SOURce#:]VOLTage[:AMPLitude] {<amplitude>|MIN|MAX}`
`[SOURce#:]VOLTage[:AMPLitude]? [MIN|MAX]`

**参数说明**：
- `<amplitude>`：浮点数，单位 V（高阻负载下）。
- `MIN`：~-10 V。
- `MAX`：~10 V。

**示例**：
- `SOURce1:VOLTage 2.5` -> 设置通道 1 输出 2.5 V。

### 4.4 偏置设置 `[SOURce#:]VOLTage:OFFSet`

**描述**：设置或查询输出偏置。

**命令格式**：
`[SOURce#:]VOLTage:OFFSet {<offset>|MIN|MAX}`
`[SOURce#:]VOLTage:OFFSet? [MIN|MAX]`

**参数说明**：
- `<offset>`：浮点数，单位 V（高阻负载下）。
- `MIN`：~-10 V。
- `MAX`：~10 V。

**示例**：
- `SOURce1:VOLTage:OFFSet 2.5` -> 设置通道 1 输出偏置 2.5 V。

## 5. `OUTPut` 子系统（物理输出控制）

该子系统控制信号发生器前端的物理继电器和阻抗匹配电路。**双通道独立控制**，使用 `OUTPut#` 区分。

### 5.1 输出开关 `OUTPut#:STATe`

**描述**：打开或关闭指定通道的信号输出继电器。

**命令格式**：
`OUTPut#:STATe {ON|OFF|1|0}`
`OUTPut#:STATe?`

**参数说明**：
- `ON` 或 `1`：闭合继电器，输出信号。
- `OFF` 或 `0`：断开继电器，输出端对地短路（静音）。

**示例**：
- `OUTPut1:STATe ON` -> 打开通道 1。
- `OUTPut2:STATe OFF` -> 关闭通道 2。
- `OUTPut:STATe?` -> 注意：不带通道号时，查询返回当前选中通道（上一次操作的通道，上电默认为通道一）状态，建议始终指定通道号。

### 5.2 输出阻抗 `OUTPut#:IMPedance`

**描述**：设置屏幕显示的负载阻抗值与幅度/偏置值，不影响物理输出阻抗，仅影响计算系数。

**命令格式**：
`OUTPut#:IMPedance {50|HIGH}`

**参数说明**：
- `50`：匹配 50Ω 系统，显示的幅度为实际负载上的电压（即设定值的一半）。
- `HIGH`：高阻模式，显示的幅度为开路电压（设定值等于实际输出）。

---

## 6. 系统与状态 `SYSTem`

### 6.1 错误队列查询 `SYSTem:ERRor?`

**描述**：读取并清除错误队列中最旧的一条错误信息。

**命令格式**：
`SYSTem:ERRor?`

**返回格式**：
`<错误码>,"<错误描述>"`

- 无错误时返回：`0,"No error"`

---

## 7. 错误代码列表（常见）

| 错误码 | 说明 | 解决方案 |
| :--- | :--- | :--- |
| 0 | 无错误 | - |
| -102 | 语法错误 | 检查命令拼写，如 `FREQ` 误写为 `FRQ` |
| -113 | 未定义的命令头 | 该命令不支持，检查手册 |
| -222 | 参数数据超出范围 | 频率值超过 30MHz 或小于 1mHz |
| -224 | 非法参数值 | 波形类型或布尔值错误，如 `SQURE` |
| -240 | 硬件错误 | 模拟板 ACK 错误 |

---
## 8. 编程示例（Python + PyVISA）
由于设备使用 USB CDC 接口，因此可以通过 PyVISA 和 PySerial 两种方式进行通信。以下示例展示了如何使用 PyVISA 控制 ArbWave30。

### 方式一：PySerial （最简单、最可靠）

```python
import serial
import time

# 1. 配置串口参数（波特率在 CDC 下通常被忽略，但为了兼容性保留）
# Windows 示例: 'COM3'，Linux 示例: '/dev/ttyUSB0' 或 '/dev/ttyACM0'
ser = serial.Serial(
    port='COM3',       # 替换为你的实际端口
    baudrate=115200,   # CDC 下这个值不影响通信速度，只要两端一致即可
    timeout=2,         # 读超时（秒），防止 readline 卡死
    write_timeout=2
)

# 2. 发送 SCPI 命令（注意：务必添加换行符 `\n`）
ser.write(b'*IDN?\n')

# 3. 读取响应（SCPI 标准以换行符 `\n` 结束）
response = ser.readline().decode('utf-8').strip()
print(f"Device Info: {response}")

# 4. 执行一连串操作示例
ser.write(b'*RST\n')             # 复位
time.sleep(0.1)                  # 给 MCU 一点处理时间（可选）
ser.write(b'SOUR1:FREQ 1000\n')  # 设置 1kHz
ser.write(b'SOUR1:FUNC SIN\n')   # 正弦波
ser.write(b'OUTP1:STAT ON\n')    # 打开输出

# 5. 查询频率
ser.write(b'OUTP1:FREQ?\n')
freq = ser.readline().decode('utf-8').strip()
print(f"Current Frequency: {freq} Hz")

# 关闭串口
ser.close()
```

### 方式二：PyVISA （功能更强大）

```python
import pyvisa

# 1. 指定纯 Python 后端（无需安装 NI-VISA 驱动）
rm = pyvisa.ResourceManager('@py')

# 2. 列出所有资源，找到你的 COM 口（通常是 'ASRL3::INSTR' 类似格式）
# print(rm.list_resources())

# 3. 打开串口资源，并配置终止符
inst = rm.open_resource('ASRL3::INSTR')  # 请替换为实际的 ASRL 端口号
inst.baud_rate = 115200
inst.read_termination = '\n'   # 非常重要：库默认是 '\n'，但最好显式声明
inst.write_termination = '\n'  # 发送时自动追加换行符

# 4. 现在你可以像用 USBTMC 仪器一样使用 query
print(inst.query('*IDN?'))
inst.write('SOUR:FREQ 1000')
inst.write('SOUR:STAT ON')

# 5. 查询
freq = inst.query('SOUR:FREQ?')
print(f"Freq: {freq}")

inst.close()
```

## 9. 版本记录

| 版本 | 日期 | 修改内容 | 修改人 |
|---|---|---|---|
| V1.0 | 2026-08-17 | 初始架构 | EERNINUO |
| V1.1 | 2026-08-18 | 添加命令 | EERNINUO |

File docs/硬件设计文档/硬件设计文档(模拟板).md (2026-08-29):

<!------------------------------------------------------------------------
SPDX-License-Identifier: CC-BY-SA-4.0
Copyright (C) 2026 [EERNINUO]

This work is licensed under the Creative Commons Attribution-ShareAlike 4.0 International License. 
To view a copy of this license, visit http://creativecommons.org/licenses/by-sa/4.0/.
------------------------------------------------------------------------->

<!-- Assisted-by: DeepSeek - 文档框架 -->

# ArbWave30 – 模拟板硬件设计文档

| 文档编号 | ArbWave30-HDD-001 | 版本 | V1.2  |
| ---| --- | ---- | ----- |
| 项目名称 | ArbWave30 | 日期 | 2026-05-26 |
| 起草人 | EERNINUO | 状态 | 草案 |

## 1. 板卡概述
- 功能定位：FPGA读取控制板发送的命令，控制DAC和模拟前端实现波形输出
- 关键性能指标：功耗、尺寸、环境要求
  - 功耗: < 10W
  - 尺寸：< 100mm x 100mm
  - 环境要求：0 \ 40 ℃
- 主要接口：对外连接器（电源、信号、控制）
  - 对外连接器：
    - 波形输出（CH1、CH2）：SMA 输出
    - 时钟输入/输出：SMA 接口
    - 多功能输入/输出：SMA 接口
  - 板间接口：见[板间接口文档](./板间接口设计文档.md)

## 2. 模块详细设计
### 2.1 FPGA 与 DAC接口
- **原理图截图**：
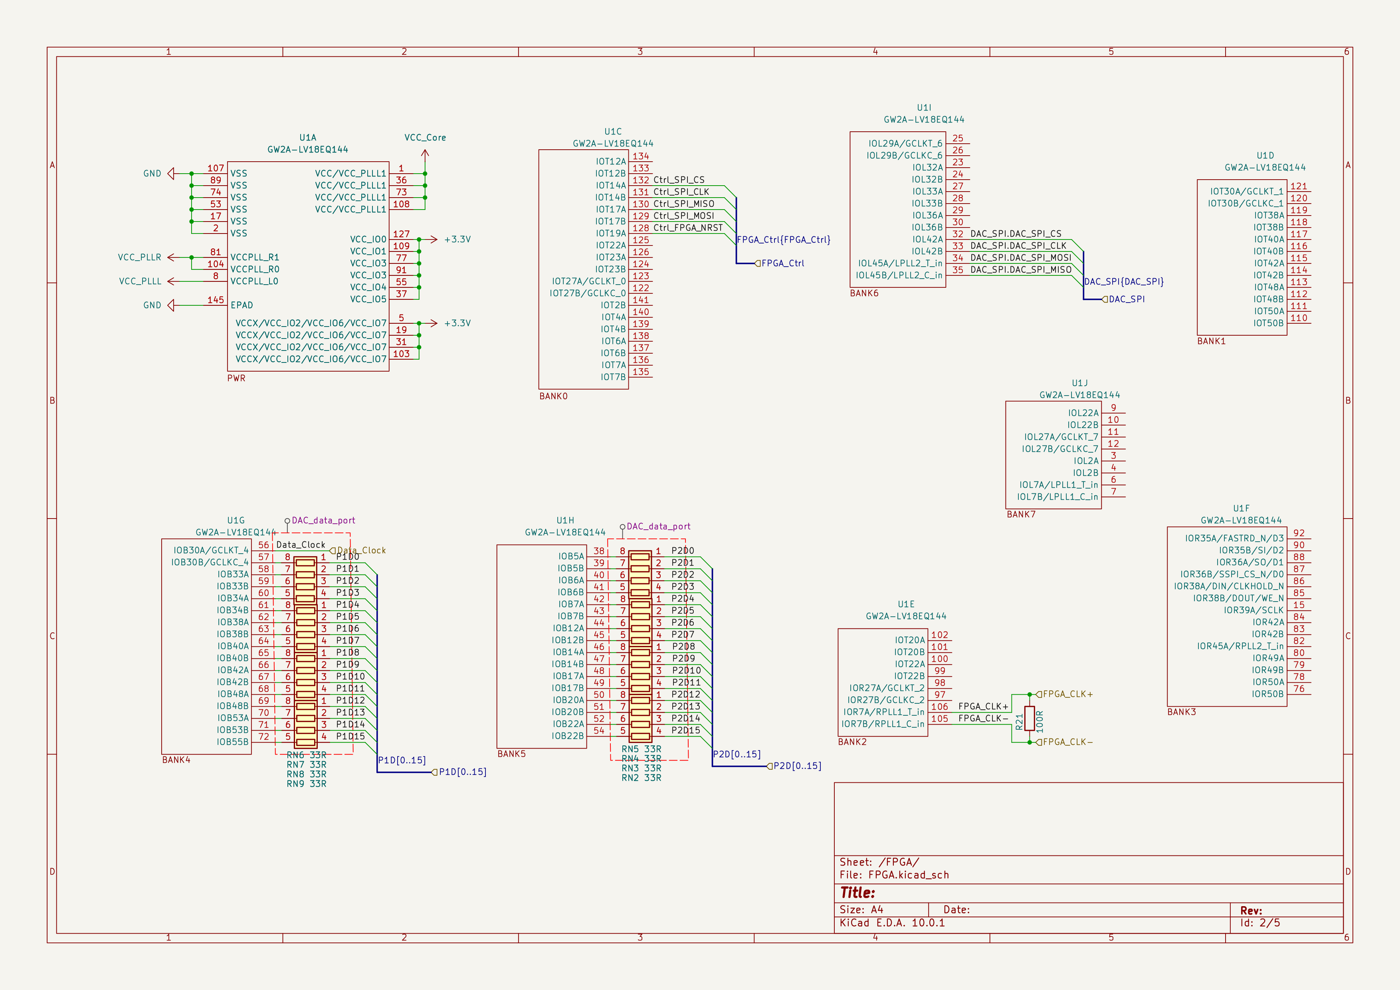
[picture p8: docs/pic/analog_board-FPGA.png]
FPGA与DAC接口
  

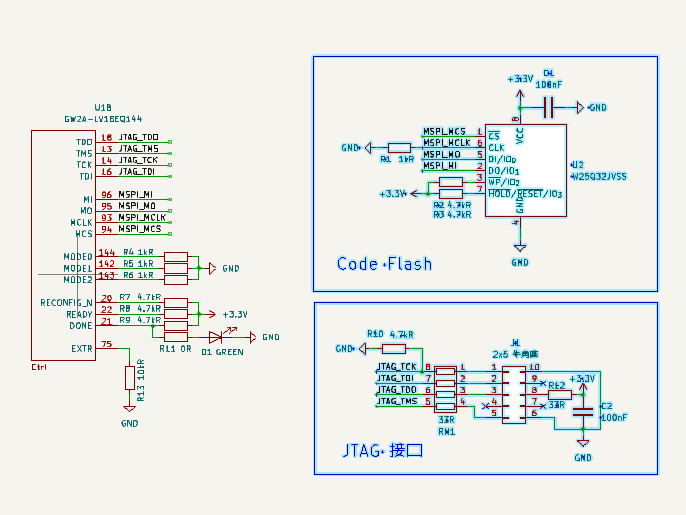
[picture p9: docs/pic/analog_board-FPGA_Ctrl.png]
FPGA控制
  
- **功能描述**：
  - 读取 MCU 发送的命令
  - 运行 DDS 算法
  - 控制 DAC 输出
  - 控制模拟前端
  
- **关键器件**：
  | 器件 | 型号 | 特性 | 选型理由 |
  |------|-----|------|----------|
  | FPGA | GW2AR-LV18EQ144C8/I7 | 20k LUTs，集成64M SDRAM | 见[FPGA选型ADR](./adr/001-fpga-select.md) |
  | Code Flash | GD25Q32ESIG | 64M | 国产Flash，价格相对较低，供应链稳定(注意后缀，S 和 T 封装大小不一样) |
  | 下载接口 | 2×5 2.54mm 牛角座 | \ | 标准接口 |
  | 下载接口保护 | USBLC6-4SC6Y | \ | 保护 FPGA JTAG 接口 |

- **设计计算**：
- 公式推导（如增益、截止频率、输出摆幅、功耗）
- 代入数值计算，并与规格书对照
1. 数据线阻抗：
  当走线长度 $L \geq \lambda / 1$时需匹配，其中 $\lambda$为信号中的最高有效频率对应的波长。对于数字信号，最高有效频率近似为 $f_{max} = 0.35 / t_r$，查GW2AR数据手册可知，**上升沿时间** $t_r $**约为0.8ns**，信号在FR4材质的PCB中**传播速度**$v$**约为15cm/ns**，则理论最长安全走线长度为：
  $\frac{\lambda}{10} = \frac{v}{10 f_{max}} = \frac{v \cdot t_r}{10 \times  0.35} = \frac{v \cdot t_r}{3.5} \approx 3.43 cm$

1. 时序要求：</br>
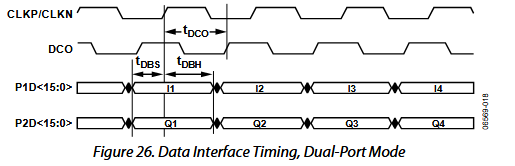
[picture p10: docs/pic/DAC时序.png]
DAC时序
    </br>
  [硬件架构文档 3.2](#3.2_波形合成模块)中给出：DAC工作在 150MSPS 下，则 CLKP/CLKN 周期约为 6.7 ns。由数据手册可知，$$t_{DCO} \approx 2.2ns$$（典型值），则 DCO 上升沿约 4.2ns 后数据采样，$$t_{DBS} > 400 ps$$，则数据至少需在3.8ns内稳定，实际最好预留一定时间。

- **接口信号**：列出输入/输出信号名称、电平、阻抗、时序要求
  | 信号名称 | 电平 | 协议 | 阻抗 | 连接到 | 备注 |
  |----------|------|------|----------|----------|----------|
  | 50MHz 时钟输入 | LVDS25 | 差分 100Ω | \ | CDCI6214 | 系统时钟 |
  | MSPI 接口 | 3.3V | SPI | \ | code flash | 程序加载 |
  | 指令输入 | 3.3V | SPI | \ | MCU | 命令输入，MISO线靠近FPGA处串电阻，绘制原理图时标注为 Ctrl_SPI_* 以和 DAC 控制 SPI 区分 |
  | 模拟前端控制 | 3.3V | GPIO | \ | 信号继电器 | 通过三极管扩流 |
  | 时钟控制 | 3.3V | GPIO | \ | 信号继电器 | 通过三极管扩流 |
  | 多功能输入/输出 | 3.3V | GPIO | \ | 多功能输入/输出 | 通过74AHC125缓冲 |
  | DAC 数据接口 | 3.3V | 并口 | 50Ω(建议) | DAC | 数据线长度差 < 5mil，绘制原理图时标注为 DAC_SPI_* 以和指令输入 SPI 区分 |
  | DCO | 3.3V | \ | \ | DAC | 数据时钟，尽可能短 |
  | DAC 控制 | 3.3V | SPI | \ | DAC |  |
  | JTAG 下载接口 | 3.3V | JTAG | \ | JTAG | 添加 ESD 保护 |

- **具体设计**：
  - LVDS时钟输入：
    1. LVDS 输入连接到 FPGA 的 PLL_IN 引脚
    2. 长度差 < 5mil，总长 < 4000mil
    3. 差分走线，控100Ω阻抗；
    4. 终端 100Ω 电阻精度 > 1%
  - DAC 数据接口：
    1. 数据线长度差 < 5mil
    2. 数据线控 50Ω 阻抗
    3. 数据线始端预留串联电阻焊盘（先焊接0欧姆）
  - DCO数据时钟：
    1. 控 50Ω 阻抗
    2. 尽可能短
    3. 连接到 FPGA 的 GCLK 引脚

- **测试点**：
  - 多功能输入/输出

### 2.2 DAC电路
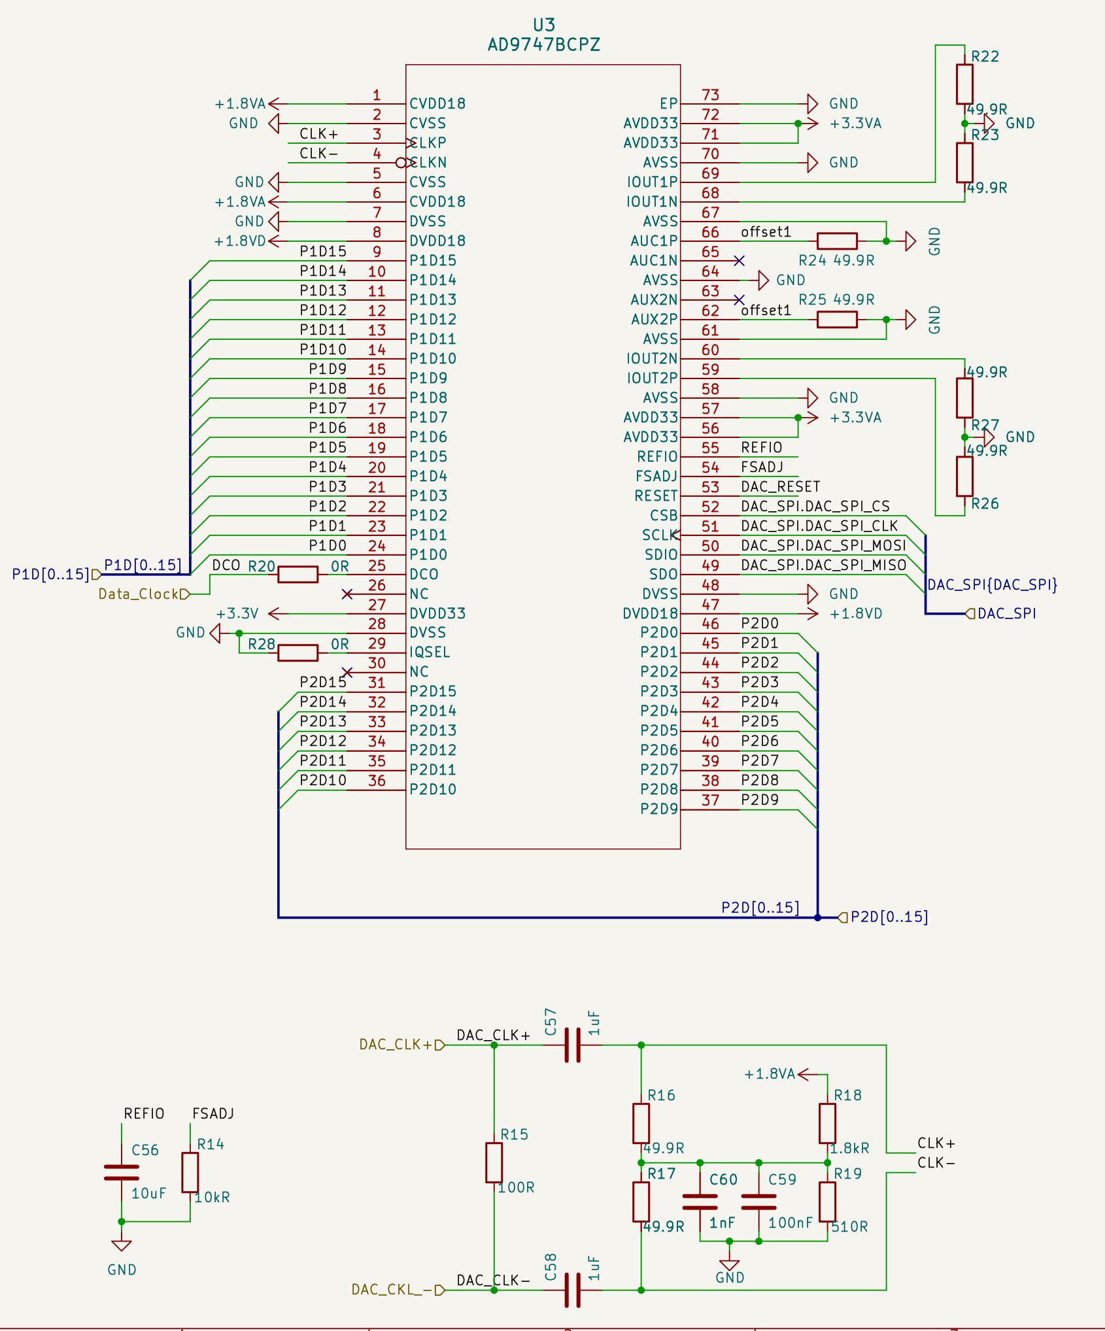
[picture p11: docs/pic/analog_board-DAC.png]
DAC电路
- **原理图截图**：
- **功能描述**：数模转换
- **关键器件**：
  | 器件 | 型号 | 特性 | 选型理由 |
  |------|-----|------|----------|
  | DAC | AD9747 | 16bit, 最大250MSPS（考虑到FPGA性能，降低到150MSPS使用）, 双通道，当前仅用通道1 | 见[DAC选型ADR](./adr/002-dac-select.md) |

- **接口信号**：列出输入/输出信号名称、电平、阻抗、时序要求
  | 信号名称 | 电平 | 协议 | 阻抗 | 连接到 | 备注 |
  |----------|------|------|----------|----------|----------|
  | DAC 数据接口 | 3.3V | 并口 | 50Ω(建议) | FPGA | 数据线长度差 < 5mil |
  | DCO | 3.3V | \ | \ | FPGA | 数据时钟，尽可能短 |
  | DAC 控制 | 3.3V | SPI | \ | FPGA |  |
  | 时钟输入 | LVDS25 | 差分 100Ω | \ | CDCI6214 | 150MHz 时钟输入 |
  | 主 DAC 输出 | \ | \ | 50Ω | 重构滤波器 | 通过两个 49.9Ω 0.1% 电阻进行I/V转换 |
  | 辅助 DAC 输出 | \ | \ | 50Ω | 偏置发生模块 | 通过两个 49.9Ω 0.1% 电阻进行I/V转换 |

- **设计计算**：
由 AD9747 数据手册可知：
- 主 DAC 最大输出电流为 20mA，输出电压不得大于 1.0V
- 辅助 DAC 最大输出电流为 2mA，输出电压不得大于 1.25V

  则，I/V转换可设计如下：
  1. 主 DAC 输出端两个差分电流输出引脚各通过一个 49.9Ω 电阻接到地，则最大输出电压为：
    $I_{max} \times R = 20mA \times 49.9\Omega = 998mV $
    满足规格要求。

- **具体设计**：
1. 主 DAC 输出端两个差分电流输出引脚各通过一个 49.9Ω 电阻接到地，辅助 DAC 输出端两个差分电流输出引脚各通过一个 499Ω 电阻接到地，满足规格要求。

2. DAC 时钟不支持 LVDS 直接输入，需通过AC耦合转换电路转换为共模电压约 400mV 的差分输入，电路参考数据手册中的示例电路设计：</br>
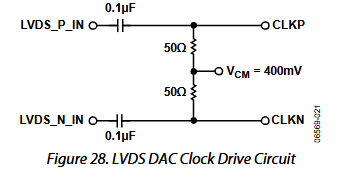
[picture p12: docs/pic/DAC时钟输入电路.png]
DAC时钟输入电路


- **测试点**：
  - 偏置电压输出
  
### 2.3 模拟前端
#### 2.3.1 重构滤波器 
- **原理图截图**：</br>
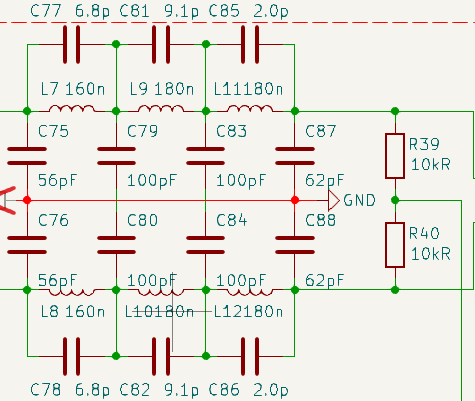
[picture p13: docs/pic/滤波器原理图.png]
滤波器原理图
  
- **功能描述**：
  去除 DAC 输出的镜像频率和高频杂散成分，满足技术规格书中对带内波动和带外抑制的要求。
  > 本设计优先考虑正弦波指标，因此滤波器的设计重点在于带内波动和带外抑制性能，因此滤波器的群延时波动较大。对于非正弦波形（尤其是方波），可能需要在软件上进行预失真处理以补偿滤波器引入的幅度和相位失真
- **关键器件**：

  | 器件 | 型号 | 特性 | 选型理由 |
  |------|-----|------|----------|
  | 电感 | AHW2012C | 陶瓷绕线电感 | 高频性能好，适合滤波 |
  | 电容 | CC0603 | C0G/NP0 陶瓷电容，精度 > 2% | 低损耗，稳定性好 |

- **设计计算**：
通过Filter Solutions设计滤波器如下：
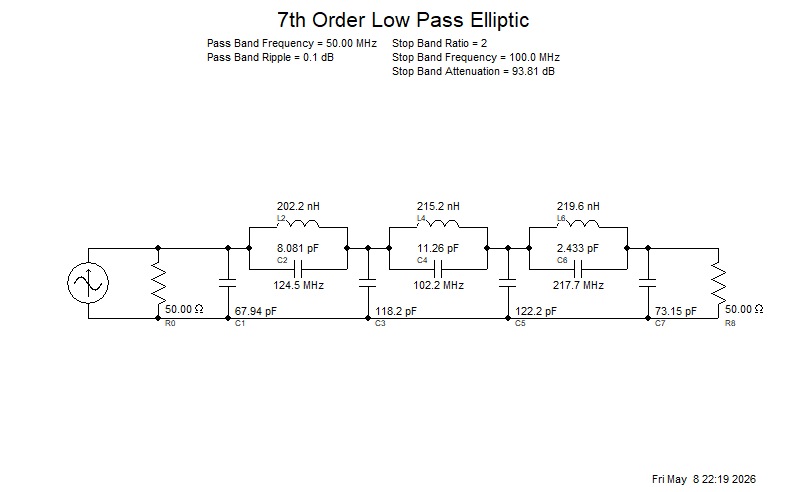
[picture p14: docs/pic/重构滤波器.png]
电路图

具体设计过程见：[重构滤波器调试笔记](/docs/设计笔记/重构滤波器调试笔记.md)

- **仿真结果**：
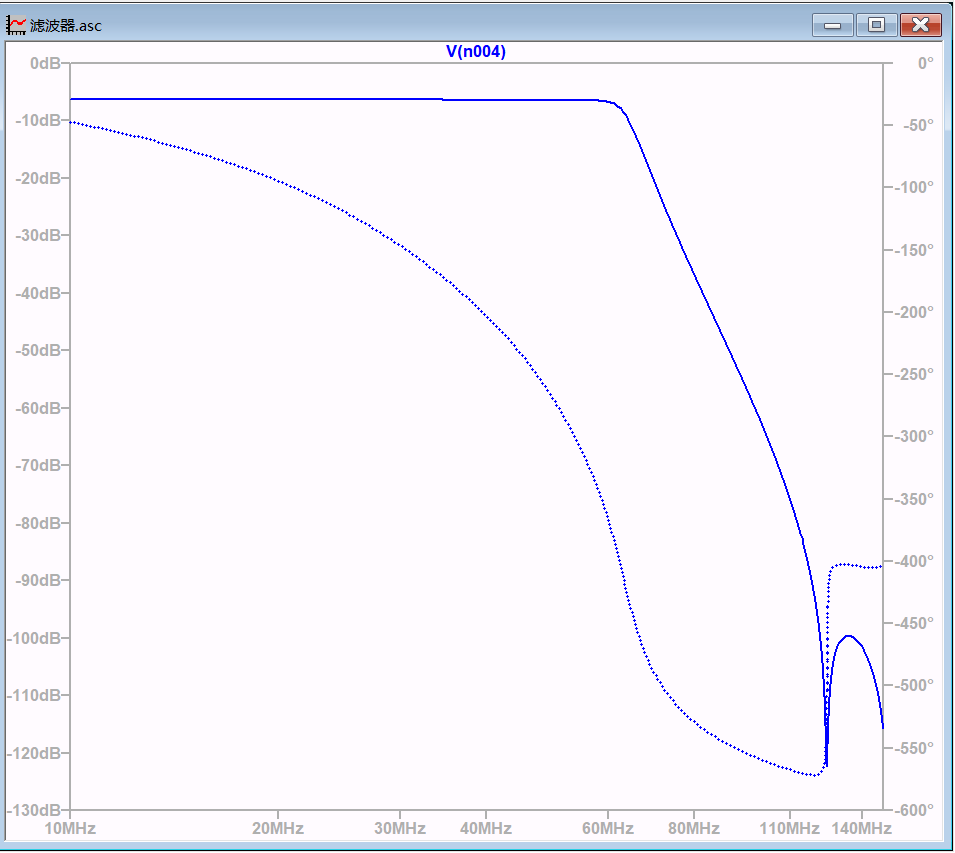
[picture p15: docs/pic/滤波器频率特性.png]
滤波器频率特性

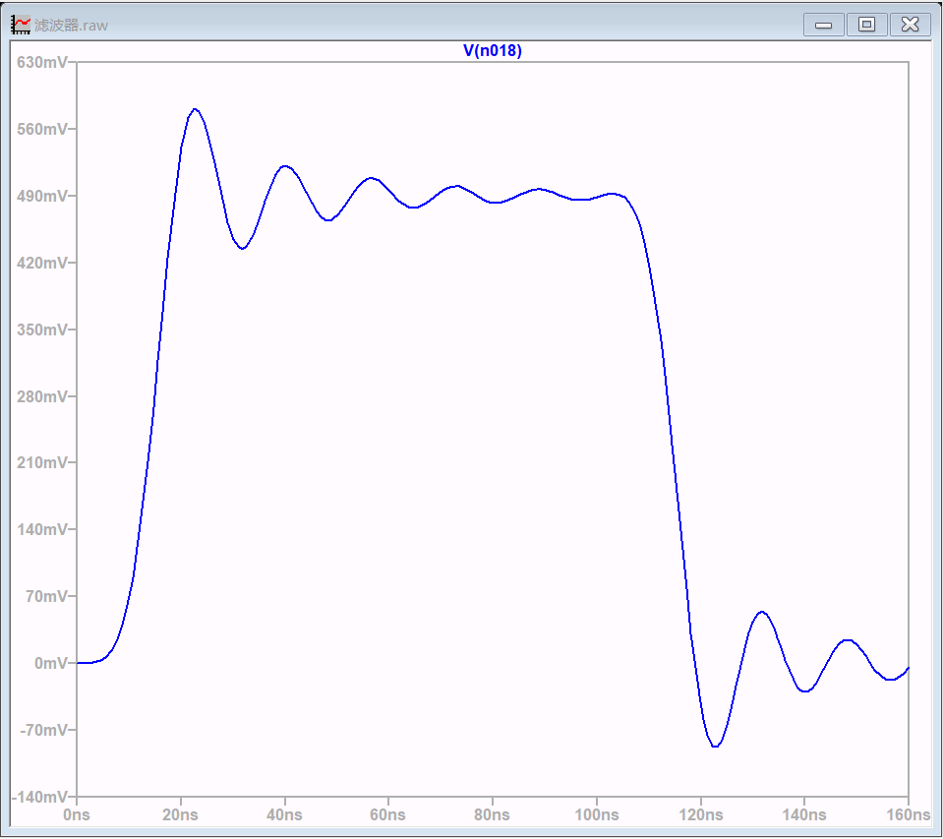
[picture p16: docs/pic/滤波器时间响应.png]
滤波器时间响应


- **接口信号**：
  
| 信号名称 | 阻抗 | 连接到 | 备注 |
|---|---|---|---|
| 差分电压输入 | 50Ω | DAC 输出 | 通过两个 49.9Ω 电阻进行I/V转换 |
| 差分电压输出 | 50Ω | 差分转单端模块 | 通过 LMH6609 转换为单端输出 |

- **具体设计**：
  1. 7 阶椭圆滤波器，截止频率 60MHz，带内波动 < 0.5dB，115MHz 抑制 > 60dB。
  2. 输入阻抗 50Ω，输出阻抗 50Ω。
  3. 采用无源 LC 结构，电感选用 AWH2012C （或者其他的高 Q 值电感），电容选用 CL10C（或者其他的 C0G/NP0 陶瓷电容，精度 > 5%）。

- **测试点**：
  - 输出端预留测试点，便于测量频率响应和时间响应
  
#### 2.3.2 共模反馈电路
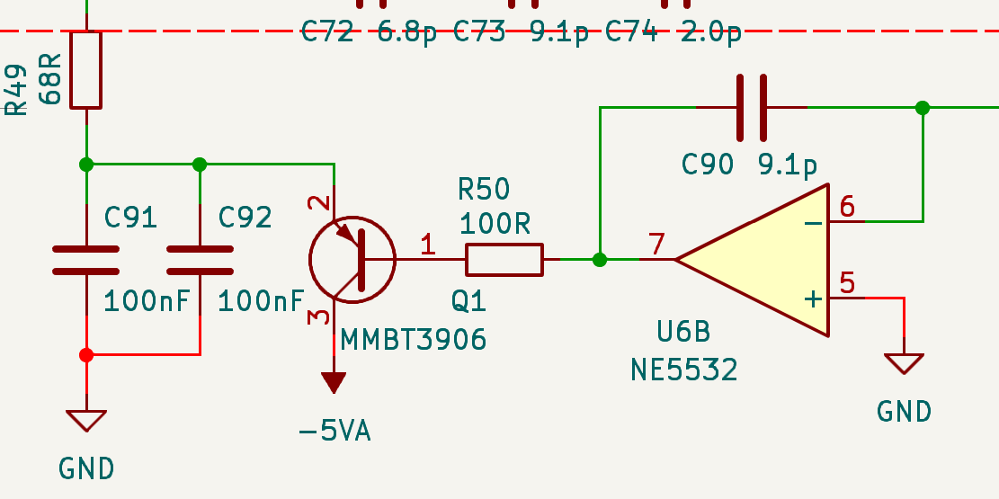
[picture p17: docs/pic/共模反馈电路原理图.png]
共模反馈电路原理图
- **原理图截图**：
- **功能描述**：
  稳定差分放大器输入的共模电压，防止输出摆幅受限，确保滤波器性能稳定。
- **关键器件**：
  
  | 器件 | 型号 | 特性 | 选型理由 |
  |-----|-----|------|----------|
  | 运放 | NE5532 | 双运放，低噪声，适合共模反馈 | 成本低，性能满足共模反馈需求 |

#### 2.3.2 差分转单端
- **原理图截图**：<font color="red">待补充</font>
- **功能描述**：
  将滤波器输出的差分信号转换为单端信号，满足后续衰减网络和输出放大级的输入要求。
- **关键器件**：
<font color="red">运放型号待补充</font>
- **设计计算**：
  通过仿真可知，滤波器插入损耗约为 6.30dB（约 0.485V/V），后级合路器增益约 0.44V/V （约 -7.13dB），但后续环节可能有额外损耗，故本模块放大倍数设计为 6V/V （约 15.56dB），以预留软件调节的空间。
1. 阻抗匹配计算：
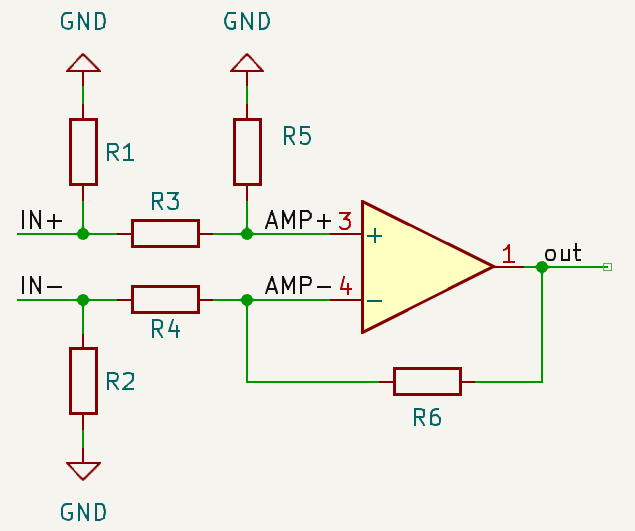
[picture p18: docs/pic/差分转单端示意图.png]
差分转单端示意图

  滤波器负载阻抗设计为 50Ω，则差分转单端电路输入阻抗应为 50Ω，增益 $G = 6 V/V$，则：
  $$\frac{R3}{R5} = \frac{R4}{R6} = \frac{1}{G} = \frac{1}{6}$$
  即：
  $$ R5 = R6 = 6 \times R3 = 6 \times R4 $$
  
    1. 反相输入端： 
    因为 $R5 = 6 \times R3$，则：
    $$V_{AMP+} = V_{IN+} \times \frac{R5}{R3 + R5} = \frac{6}{7}V_{IN+}$$
    又：在纯差模下，$$V_{IN+} = -V_{IN-}$$，则 R4 两端的电压为：
    $$V_{R4} = V_{IN-} - V_{AMP+} = -\frac{13}{7}V_{IN+}$$
    则：通过R4的电流为：
    $$I_{R4} = \frac{V_{R4}}{R4} = -\frac{13V_{IN+}}{7R4}$$
    即可算出反相输入端的输入阻抗为：
    $$Z_{IN-} = \frac{V_{IN-}}{I_{R4}} = \frac{7}{13} \times R4$$
    令 $Z_{IN-} = 50\Omega$，则：
    $$R4 = R3 = \frac{13}{7} \times 50\Omega = 92.857 \Omega \approx 93.1 \Omega$$
    则：
    $$R5 = R6 = 6 \times R4 = 556.428 \Omega \approx 560 \Omega$$

    > 由于反相输入端刚好匹配 50Ω 阻抗，所以 R2 可省去，当然也可以不用 50Ω 计算以换取更加常见的电阻值，能获得更好的匹配效果，但要考虑多一个电阻带来的噪声和成本是否划算。

    2. 同相输入端：
    由 
    $$\frac{1}{50} = \frac{1}{R_1} + \frac{1}{R_3 + R_5}$$
    可知：
    $$R_1 = \frac{1}{\frac{1}{50} - \frac{1}{653.1}} \approx 53.6 \Omega$$

- **具体设计**：
  - 增益设计为 6V/V，反馈电阻选用 560Ω，输入电阻选用 93.1Ω，其他电阻根据阻抗匹配计算结果选用。
  - 使用双电源供电，电源输入端添加磁珠和去耦电容，确保电源稳定。
  - 为了方便走线，通道 1 中运算放大器的输入引脚和 DAC 的的输出引脚<b><font color="red">反向连接</font></b>，即 LMH6609 的同相输入端连接到 DAC 的负输出引脚，反相输入端连接到 DAC 的正输出引脚，输出端连接到衰减网络输入，因此<b><font color="red">在软件中需要对通道 1 的数据进行反相处理</font></b>。
- **仿真结果**：
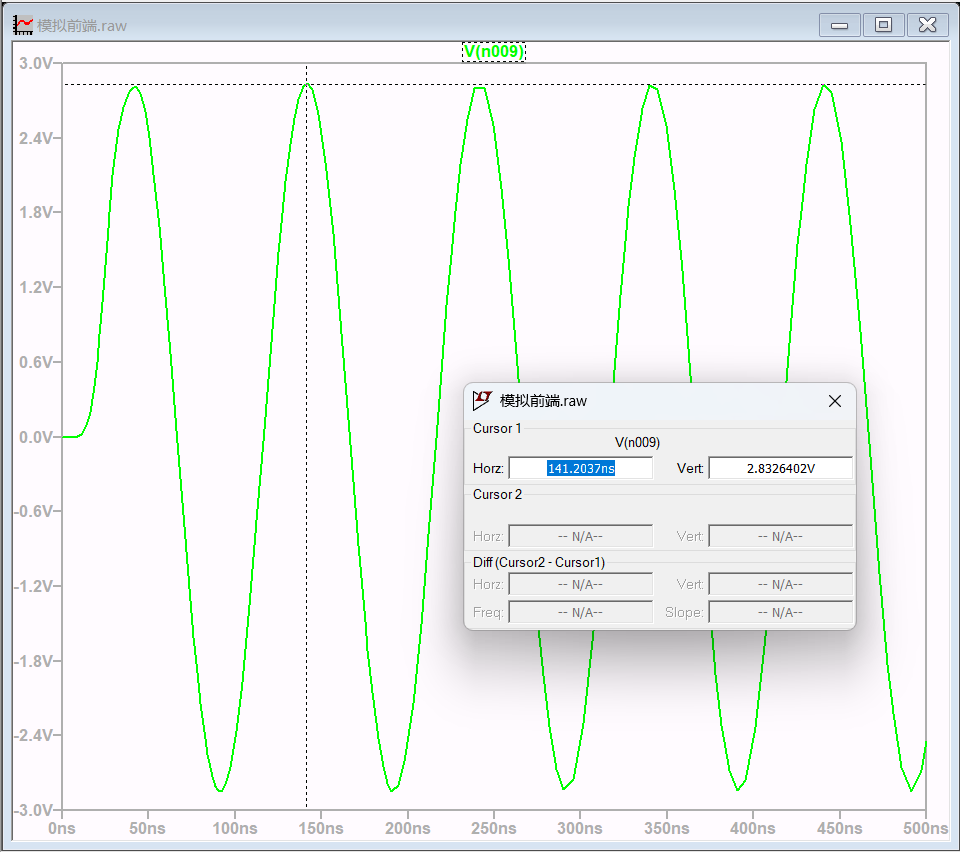
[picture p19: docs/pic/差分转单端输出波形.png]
差分转单端输出波形
  
- **保护设计**：
  - 波形输出端可添加一个 3.0V 的 TVS 二极管，防止外部电压串入
- **测试点**：
  - 输出端：测量增益和频率响应

#### 2.3.3 衰减网络 
- **原理图截图**：<font color="red">待补充</font>
- **功能描述**：该模块实现什么
- **关键器件**：型号、选型理由（性能、成本、供货）
- **设计计算**：
  - 公式推导（如增益、截止频率、输出摆幅、功耗）
  - 代入数值计算，并与规格书对照
- **仿真结果**（可选）：插入 LTspice/ADS 波形图
- **接口信号**：列出输入/输出信号名称、电平、阻抗、时序要求
- **保护设计**：ESD、过流、过压、防反接等
- **测试点**：建议预留哪些测试点（TP_xxx）及用途

#### 2.3.4 偏置产生与求和
- **原理图截图**：<font color="red">待补充</font>
- **功能描述**：该模块实现什么
- **关键器件**：型号、选型理由（性能、成本、供货）
- **设计计算**：
  - 公式推导（如增益、截止频率、输出摆幅、功耗）
  - 代入数值计算，并与规格书对照
- **仿真结果**（可选）：插入 LTspice/ADS 波形图
- **接口信号**：列出输入/输出信号名称、电平、阻抗、时序要求
- **保护设计**：ESD、过流、过压、防反接等
- **测试点**：建议预留哪些测试点（TP_xxx）及用途

#### 2.3.5 输出增益级
- **原理图截图**：<font color="red">待补充</font>
- **功能描述**：该模块实现什么
- **关键器件**：型号、选型理由（性能、成本、供货）
- **设计计算**：
  - 公式推导（如增益、截止频率、输出摆幅、功耗）
  - 代入数值计算，并与规格书对照
- **仿真结果**（可选）：插入 LTspice/ADS 波形图
- **接口信号**：列出输入/输出信号名称、电平、阻抗、时序要求
- **保护设计**：ESD、过流、过压、防反接等
- **测试点**：建议预留哪些测试点（TP_xxx）及用途
  <!-- 输出开关旁加指示灯指示通道状态 -->
-
#### 2.4 时钟生成
- **原理图截图**：<font color="red">待补充</font>
- **功能描述**：该模块实现什么
  生成 FPGA 和 DAC 所需的 LVDS 时钟信号，生成 10MHz 同步时钟输出。
- **关键器件**：型号、选型理由（性能、成本、供货）
  | 器件 | 型号 | 特性 | 选型理由 |
  |------|-----|------|----------|
  | 时钟发生器 | CDCI6214 | 4 输出，支持 LVDS 输出 | 满足时钟输出需求，支持 LVDS 输出 |
  | 晶振 | OW2EL89CEIUE2UYLC-10M | 10MHz、±2ppm、±1ppm/℃ | 满足时钟频率和输出要求 |

- **设计计算**：
  通过官方软件 TICS Pro 进行时钟发生器的配置，生成所需的时钟频率和电平，确保满足 FPGA 和 DAC 的时钟要求。
- **接口信号**：列出输入/输出信号名称、电平、阻抗、时序要求

  | 信号名称 | 电平 | 协议 | 阻抗 | 连接到 | 备注 |
  |----------|------|------|----------|----------|----------|
  | 外部 10MHz 参考时钟 | LVDS25 | \ | 差分 100Ω | CDCI6214 | 通过信号继电器切换内部 TCXO 和外部输入，添加 TVS 保护（TVS 寄生电容应小于 5pF） |
  | 150MHz LVDS 时钟输出 | LVDS25 | \ | 差分 100Ω | DAC |  |
  | 50MHz LVDS 时钟输出 | LVDS25 | \ | 差分 100Ω | FPGA | 时钟发生器输出 |
  | 10MHz 同步时钟输出 | LVCOMS33 | \ | 50Ω | 时钟输出接口 | \ |
  | 时钟控制 | 3.3V | GPIO | \ | FPGA | 通过三极管扩流控制信号继电器切换时钟输入 |
  | 时钟发生器复位 | 3.3V | GPIO | \ | FPGA，配置排针 |  |
  | IIC 控制 | 3.3V | I2C | \ | 配置排针 | 配置时钟发生器 |

- **保护设计**：
  - 外部时钟输入端口应添加 TVS 保护，防止静电放电损坏时钟发生器，TVS 寄生电容应小于 5pF 以避免影响时钟信号质量。
  
- **测试点**：
  - 10MHz 参考时钟输入：测量点，观察输入信号质量
  - 10MHz 同步时钟输出：测量点，观察时钟信号质量
  > 由于时钟信号频率较高，直接测量测试点无法得到准确的波形，需要使用 SMA 接头或者焊接导线，但专门为了测量时钟波形而焊接多个 SMA 接头不太值，且导线分叉反而会影响时钟质量，所以测试点的设置只是为了确认时钟的频率，不涉及时钟完整性的测量

### 2.5 电源与去耦 (#模拟板电源设计)
- **原理图截图**：<font color="red">待补充</font>
- **功能描述**：
  - 将输入的 ±17V 转为 ±15V_A、±5V_A、+3.3V_A、+1.8V_A、+1.0V_D 电压轨
  - 将输入的 +3.3V_D 转为 +3.3V_A、+1.8V_D 电压轨
- **关键器件**：型号、选型理由（性能、成本、供货）
  | 器件 | 型号 | 特性 | 选型理由 |
  |------|-----|------|----------|  
  | ±15V_LDO | L7815 / L7915 | 1.2A 输出电流，17V 输入 | TO-220 封装，稳定可靠，成本低 |
  | ±5V_LDO | L7805 / L7905 | 1.5A 输出电流，7V 输入 | TO-220 封装，稳定可靠，成本低 |
  | 3.3V_A LDO | TPS7A4701 | 1.5A 输出电流，5V 输入，超低噪声 | 专为高性能模拟电路设计，满足 DAC 和时钟的噪声要求 |
  | 1.8V_A LDO | TPS7A9101 | 1A 输出电流，3.3V 输入，超低噪声 | 专为高性能模拟电路设计，满足 DAC 时钟电压的噪声要求 |
  | 1.8V_D LDO | AMS1117-ADJ | 1A 输出电流，3.3V 输入 | 成本低，数字电路对噪声要求较低 |
  | 1.0V_D DC-DC | TPS62933 | 3A 输出电流，17V 输入，同步整流，效率高 | 同步整流，可以省略异步整流的续流二极管，相同电流下发热小、体积小；开关管导通速度仅 70ns ，适合 17 -> 1V 的低占空比场景 |

- **设计与计算**：
1. **具体设计**
  - **+1.0V_D 电源设计**：
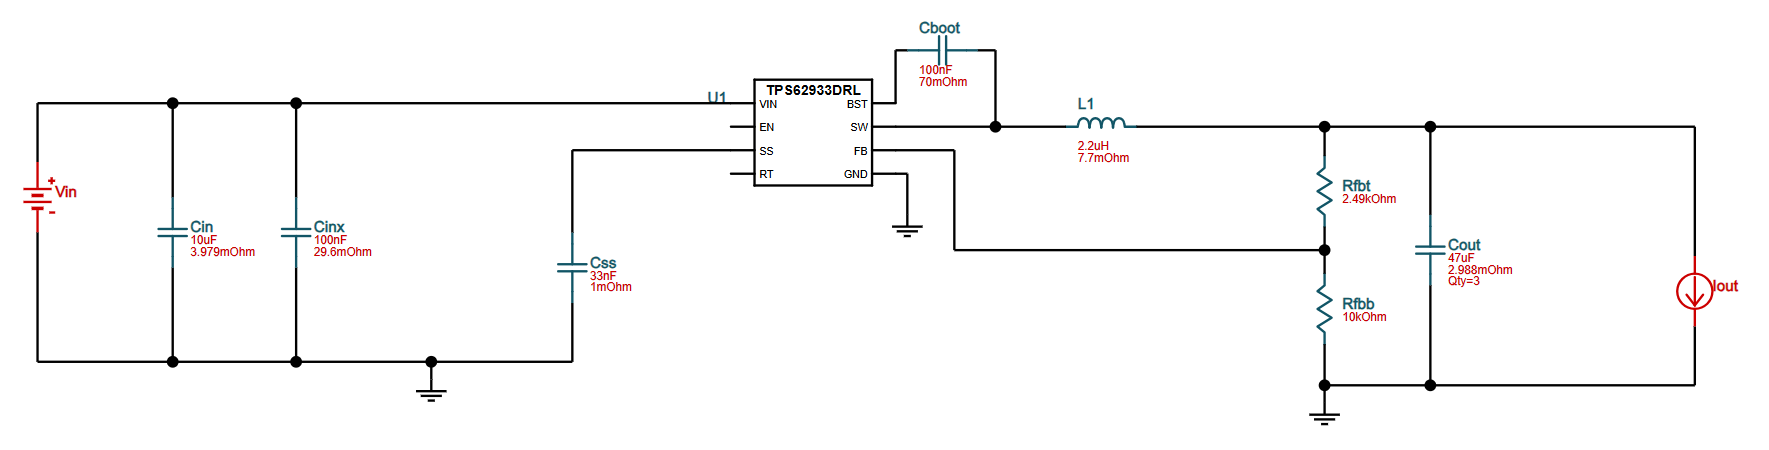
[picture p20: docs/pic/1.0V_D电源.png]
1.0V_D
  

2. **注意事项**
  - DCDC 电路的低电压端（正向 buck 的 GND，反向 buck 的 Vout-）都通过大量过孔连接到对应的铜皮以保证回流路径低阻抗
  - SW 节点面积尽量小，且远离敏感信号线
  - 热焊盘通过大量过孔接到底层铜箔（GND 或 Vout-）
  - 输出电容可适量加大，选择大容量的电解电容配合低 ESR 的 MLCC ，可以确保稳定性和降低纹波
  - 输入端加大电容，降低输入纹波对电路的影响，需要注意电容的耐压值
  </br>
  - LDO 电容可适当加大，但要注意振荡
  - 输出端可以加 LC 滤波器和多级旁路电容，进一步降低输出纹波
  - 预留散热器位置，必要时加装散热器
  - 各引脚要通过大量过孔连接到大面积铜皮以提高过流能力和散热能力  <!-- 虽然这里的 LDO 撑死也就 1W 的功耗吧，电流最大也不会超过 500mA ，但把铜皮画大一点又不用加钱-->

- **测试点**：
  - +15V_A、-15V_A 电压轨：测量点，纹波测试点
  - +5V_A、-5V_A 电压轨：测量点，纹波测试点
  - +3.3V_A 电压轨：测量点，纹波测试点
  - +1.8V_A 电压轨：测量点，纹波测试点
  - +3.3V_D 电压轨：测量点，纹波测试点
  - +1.8V_D 电压轨：测量点，纹波测试点
  - +1.0V_D 电压轨：测量点，纹波测试点
  > 测试点旁边记得留 GND 测试点，方便测量时进行参考 

### 2.6 多功能 I/O
- **原理图截图**：<font color="red">待补充</font>
- **功能描述**：该模块实现什么
- **关键器件**：型号、选型理由（性能、成本、供货）
- **设计计算**：
  - 公式推导（如增益、截止频率、输出摆幅、功耗）
  - 代入数值计算，并与规格书对照
- **接口信号**：列出输入/输出信号名称、电平、阻抗、时序要求
- **保护设计**：ESD、过流、过压、防反接等
- **测试点**：建议预留哪些测试点（TP_xxx）及用途

## 3. PCB 布局与布线指南
### 3.1 **层叠结构**：
- 层数：4 层
- 层序：
  - Top：信号 + 电源局部走线 + 元件
  - Inner1：完整地平面（GND）
  - Inner2：电源分割层（+3.3V_D, +18V_M, -18V_M 等）
  - Bottom：信号 + 少量地线 + 辅助电源走线
- 板材：普通 FR-4 即可。
- 铜厚：外层1oz，内层0.5oz。
### 3.2 整体布局
1. 功能分区（物理隔离）
- 高速数字区：FPGA、SPI Flash、DAC 数字接口
- 时钟区：TCXO、CDCI6214、时钟缓冲器
- 模拟区：DAC 模拟输出、I/V 转换、滤波器、衰减网络、输出级
- 电源区：LDO、DC-DC、滤波电路

2. 关键器件摆放
- DAC 尽量靠近 FPGA，数据线等长。
- CDCI6214 靠近 DAC 和 FPGA，输出时钟走线优先且短。
- 输出级 THS3095 靠近 SMA，并远离数字区。

### 3.3 关键模块布线约束
### 3.3.1 FPGA 与 DAC 接口
- 数据线 D1[15:0]：等长，误差 < 5mil。组内间距 3 倍线宽，避免串扰。
- DAC 时钟线：单独走线，尽量短。
- 控制信号（WRT, RESET 等）：不需要严格等长，但要避免毛刺，可串 22Ω 电阻。
- SPI 接口：驱动端加 22Ω 电阻，避免反射和毛刺。

### 3.3.2 时钟电路
- TCXO 输出：经过继电器，再到 CDCI6214 的输入，走线短，远离数字信号。
- 外部 10MHz 输入：SMA 进来先经过 ESD 保护，再到继电器，再进 CDCI6214。走线保持 50Ω 特征阻抗。
- CDCI6214 输出：
  - 150MHz 到 DAC：差分走线，控 100Ω 阻抗，长度 < 4000mil，组内长度差 < 5mil。连线末端加 100Ω 终端电阻。
  - 50MHz 到 FPGA：差分走线，控 100Ω 阻抗，长度 < 4000mil，组内长度差 < 5mil。连线末端加 100Ω 终端电阻。
  - 所有时钟线下方必须保证连续地平面，不得跨越电源层分割缝隙。

### 3.3.2 DAC 电路
- 电源输入串联磁珠，并联多个去耦电容，靠近 DAC 引脚，回路最短。
- DAC 输出端到 I/V 转换电阻的走线差分等长，控 50Ω 阻抗。
- DAC 时钟输入走线短，控 50Ω 阻抗，远离数字信号线。

### 3.3.3 模拟信号链（I/V → 滤波器 → 差分转单端 → 衰减 → 输出级）
1. I/V 转换
- DAC 输出端到 I/V 转换电阻的走线差分等长，控 50Ω 阻抗。
- 电阻放置靠近滤波器。

2. 重构滤波器（5 阶椭圆）
- 电感与电容 T型摆放，元件紧密排列。
- 输入输出保持 50Ω 环境，必要时加匹配电阻。

3. 差分转单端
- 反馈电阻 Rf 紧贴运放反相输入引脚，避免寄生电感。
- 输出端走线尽量短，直接进入下一级。
- 电源引脚加去耦电容，靠近引脚，并且每个电源轨加磁珠（如 120Ω @ 100MHz）隔离。
- 反馈信号走线周围/下方铜箔需挖空，以减少寄生电容。
- 为了方便走线，通道 1 中运算放大器的输入引脚和 DAC 的的输出引脚**反向连接**，即 LMH6609 的同相输入端连接到 DAC 的负输出引脚，反相输入端连接到 DAC 的正输出引脚。

4. 衰减网络（继电器 + 电阻）
- 继电器控制信号远离模拟信号线。
- 电阻选用 0603 封装，精度 0.1%，贴片。

5. 输出级（THS3095）
- 输入电阻 Rg 紧贴同相输入端。
- 输出串联 50Ω 电阻，再接到输出继电器。
- 电源引脚加去耦电容，靠近引脚，并且每个电源轨加磁珠（如 120Ω @ 100MHz）隔离。
- 反馈信号走线周围/下方铜箔需挖空，以减少寄生电容。
- 散热：底部大面积铜皮，开阻焊窗，加过孔阵列。

### 3.3.4 偏置产生
- 作为低频电路（< 100kHz），布局要求不高，但要远离热源和高速数字线。
- 输出到加法器的连线尽量短，可加 RC 低通（1kΩ+1μF）滤除 DAC 毛刺。

### 3.4 电源与地平面处理
- 地平面：
  - 顶层模拟/数字部分不铺地平面，电源部分铺地平面。
  - 第 2 层铺完整无分割地平面，模拟区和数字区不切地。所有信号回流路径都在同一参考面上，避免扩大环路。
  - 底层铺铜皮，可作为散热层使用。
  - 空旷处加缝合过孔。
- 电源层：分割成多个岛。每个岛与地平面之间的电容（在源头处加）。
- 禁止跨岛走线：任何信号线不能跨越不同的区域。布局时确保高速/精密信号线下方对应的参考层是完整的地，而不是电源层。
- 散热：电源模块和输出级等高功耗器件底部加大面积铜皮，并通过过孔连接到内层地平面，增强散热能力。L78/79xx 系列线性稳压器预留散热片安装位置。

### 3.5 散热
- 所有底部有散热焊盘的器件加过孔阵列连接至底层铜皮（可视情况进行阻焊开窗），FPGA 可加散热片。
  
### 3.6 PCB 制造优化
  - 走线宽度：电源线 > 10mil，**无阻抗要求的**信号线 > 5mil。
  - 过孔：过孔 > 12/24 mil
  - 大面积空旷区域加平衡铜皮（通过缝合过孔接地），避免 PCB 弯曲。
  
### 3.7 信号完整性检查清单
  - DAC 数据线等长误差 < 5mil。
  - 时钟线长度 < 4000mil，等长误差 < 5mil。
  - 所有模拟信号下方无数字信号穿越。
  - 电源线宽度 > 10mil。  
  - 每个电源引脚都有 0.1μF 电容，电源入口有 10~100μF 电容。
  - 没有信号线跨越电源分割缝隙。
  - SMA 输出下打过孔到地，并加 ESD 器件。

## 4. 调试与测试计划
### 4.1 上电前检查清单（短路测试、电源电压测量）
电源对地短路、极性、焊接。
### 4.2 单板独立测试步骤：
分步上电：先焊电源部分，验证各电压轨；再焊时钟，测 150MHz；然后焊 FPGA，烧录代码；最后焊 DAC 和模拟前端。
关键波形测试点：
  - 电源纹波
  - SPI 信号（时钟、数据）波形
  - DAC 差分输出（滤波器前）
  - 滤波器输出
  - 差分转单端输出
  - 衰减器输出
  - 偏置电压
  - 最终输出
模块测试：
  - 时钟输出：用示波器测量 150MHz 波形和抖动（使用余辉模式）。
  - DAC 静态测试：FPGA 输出固定码，用万用表测量 DAC 输出电流。
  - 滤波器响应：使用网络分析仪nanoVNA（或信号源+示波器）扫描 S21。
  - 全链路测试：FPGA 产生 1MHz 正弦，观察输出幅值和失真。
  - 性能验证：按技术规格书中的测试方法进行。

## 5. 元器件清单（BOM 摘要）
- 只列出关键/易错器件（阻容感值、精度、封装、耐压、温度系数）
- 完整 BOM 另存为 CSV 文件，此处放链接

## 6. 仿真文件与参考资料
LTspice 仿真电路、Filter Solutions 设计文件。

关键数据手册页码索引。

## 7. 版本记录
| 版本 | 日期 | 修改内容 | 修改人 |
|---|---|---|---|
| V1.0 | 2026-04-24 | 初始版本 | EERNINUO |
| v1.1 | 2026-05-22 | 模拟板MVP | EERNINUO |
| v1.2 | 2026-05-26 | 修改电源引脚分配，将 ±7V 生成移至控制板| EERNINUO |

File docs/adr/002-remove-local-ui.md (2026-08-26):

<!------------------------------------------------------------------------
SPDX-License-Identifier: CC-BY-SA-4.0
Copyright (C) 2026 [EERNINUO]

This work is licensed under the Creative Commons Attribution-ShareAlike 4.0 International License. 
To view a copy of this license, visit http://creativecommons.org/licenses/by-sa/4.0/.
------------------------------------------------------------------------->

<!-- Assisted-by: DeepSeek - 文档框架 -->

# ADR-002: V1.0/V2.0 仅采用远程控制，放弃本地人机交互

## 状态
已采纳 （2026-04-27）

## 背景
ArbWave30 项目定位为一款 30MHz 任意波形发生器，核心价值在于：
- 高信号质量（低 THD、低噪声、宽带宽）
- 完整的 SCPI 命令集支持，便于自动化测试

在初始设计中，曾计划为 V1.0 配备本地操作设备（按键、旋转编码器、小尺寸 TFT 屏），以便在不连接 PC 时也能进行基本设置。然而，随着设计深入，出现以下问题：

1. **MCU 引脚紧张**：STM32F411CEU6 （48 脚） 在满足 USB、SPI （至 FPGA）、I2C （至EEPROM）、调试接口及电源管理后，所剩 GPIO 难以支持矩阵键盘 + 编码器 + SPI 屏幕，且强行增加会严重制约 PCB 布局。
2. **本地显示价值有限**：1.8 寸小屏无法清晰显示波形、频率、幅值等参数；2.8 寸触摸屏虽可行，但会增加大量的 UI 代码调试工作，分散对模拟前端、FPGA DDS 和 SCPI 解释器等核心模块的精力。
3. **核心应用场景为远程控制**：项目的典型使用场景大部分都有连接 PC 的条件，可通过 Python/PyVISA 等工具发送 SCPI 命令进行自动化测试或手动调试。大部分情况下本地操作并非刚需。
4. **低成本迭代**：V1.0 应尽快完成硬件验证和基本功能，本地交互可作为 V3.0 的增强特性，届时可选用 Linux 核心板 + 大屏方案，体验更好且不拖累主进度。

## 决策

**V1.0 和 V2.0 版本完全取消所有本地人机交互硬件（按键、编码器、TFT/LCD 屏幕），仅保留若干个状态 LED 指示状态）。**

控制板的核心职责限定为：
- USB 通信（USBTMC 或 CDC 类），实现 SCPI 服务器
- 通过 SPI 总线配置 FPGA 中的 DDS 参数（频率、相位、波形、幅度系数）
- 通过 I2C 配置时钟发生器 CDCI6214
- 通过板间连接器向模拟板提供电源和控制信号

所有参数设置、波形切换、输出控制均通过 SCPI 命令完成。用户可以使用任何支持 VISA 的软件（如 Python PyVISA、LabVIEW、Keysight Command Expert）或项目提供的简易 PyQt 上位机进行控制。

## 后果

### 正面影响

1. **降低硬件复杂度**：控制板 PCB 面积减小，布线更简洁，引脚分配宽松，EMC 风险降低。
2. **缩短开发周期**：无需编写按键扫描、菜单逻辑、LCD 驱动、触摸校准等代码，固件可聚焦于 SCPI 解析和 SPI/I2C 通信。
3. **提高可靠性**：减少机械元件（按键、编码器）和排线连接，硬件故障点减少。

### 负面影响

1. **无法独立于 PC 使用**：用户必须有一台电脑并通过 USB 连接才能操作设备。但考虑到目标用户群体（实验室工程师、开发者）均有 PC，且 USB 线缆成本低，此限制可以接受。
2. **调试时需要额外电脑**：开发过程中，每次更改参数都需要发送 SCPI 命令。这可通过在 PC 上运行一个简单的 PyQt 上位机或使用串口助手缓解，且本身就是自动化测试的一部分。
3. **产品形态不完整**：从外观上看，设备（v1.0）只有一个 SMA 输出口、四个特殊功能SMA口、一个 USB 口和一个电源口，没有屏幕和按钮，可能会让初次接触的人感到困惑。但通过清晰的丝印标识和文档说明可以解决。

## 替代方案

| 方案 | 描述 | 为何放弃 |
|---|---|---|
| 保留编码器+按键，不装屏幕 | 通过按键和编码器盲操作，依靠蜂鸣器或 LED 反馈 | 无法显示当前参数，实用性差，且仍然占用 GPIO |
| 换用更大封装的 MCU（如 STM32F407VET6） | 使用 100 脚 MCU，引脚足够支持键盘和屏幕 | 增加 PCB 面积和成本，且 V1.0 核心目标并非本地交互，不值得为此更换平台 |
| V1.0 就采用 Linux 核心板（如 RK3506） | 直接运行 Linux，驱动大屏触摸，实现完整本地 GUI | 技术栈跨度大，开发周期不可控，与当前“先保证硬件指标”的优先级冲突 |

## 后续计划

- V1.0 / V2.0：维持纯远程控制设计，完成所有性能指标和 SCPI 命令集。
- V3.0（规划）：评估是否增加本地 HMI。届时将采用独立的 Linux 核心板（如 RK3506）替换控制板上的MCU。本地显示与远程控制可并存。

## 参考文献

- 本项目技术规格书 `docs/项目技术规格书.md` 第 4.5 节（远程控制）

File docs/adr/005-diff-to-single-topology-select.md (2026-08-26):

<!------------------------------------------------------------------------
SPDX-License-Identifier: CC-BY-SA-4.0
Copyright (C) 2026 [EERNINUO]

This work is licensed under the Creative Commons Attribution-ShareAlike 4.0 International License. 
To view a copy of this license, visit http://creativecommons.org/licenses/by-sa/4.0/.
------------------------------------------------------------------------->

<!-- Assisted-by: DeepSeek - 文档框架 -->

# ADR-005: 差分转单端电路拓扑选型

## 状态
已采纳 （2026-08-05）

## 背景
经过计算，差分转单端电路原方案下 OPA695 在增益 G = 6 V/V 时，反向输入端阻抗 $Z_{Non} \approx 39.4 \Omega$，无法通过并联电阻实现 50Ω 输入阻抗。因此，需要修改电路拓扑来满足滤波器的输出负载要求。

## 决策驱动因素
- PCB 修改方便性：模拟板 MVP 已经打样，尽量选择能够在现有 PCB 上进行修改的方案。
- 成本：总成本尽量低，50 以内为优。
- 电路性能：增益、稳定性、噪声、带宽、压摆率等要求。

## 考虑的方案
### 方案一：继续使用 OPA695，在反相输入端串联 10.6 Ω 电阻
- 提出逻辑：反向输入端串联电阻可以降低增加输入阻抗，从而实现 50Ω 输入阻抗。
- PCB 修改方便性：不需要额外修改 PCB，串联的新电阻可以和反相输入端的电阻合并成 83.8 Ω。
- 成本：仅需要额外采购电阻。
- 电路性能：
  - 噪声、带宽、压摆率：运放未更换，因此无影响。
  - 稳定性：差分放大器反相端串联电阻实际上改变了增益，则反馈电阻需要重新计算，否则很有可能影响稳定性。
  - 增益：反向端串联电阻降低了增益。
  - 共模抑制比（CMRR）：若只在反相输入端串联电阻，会导致电路不对称，反相端增益和同相端增益不一致，从而影响 CMRR。
  
### 方案二：更换为电压反馈运放
- 提出逻辑：电压反馈运放可以在较大的范围内选择反馈电阻，规避了电流反馈运放在对应增益下需要选择特定电阻，导致输入阻抗没办法满足 50Ω 的限制。
- PCB 修改方便性：需要更换运放，如果采用 SOIC-8 封装可以直接替换，如果采用其他封装则需要重新设计 PCB。
- 成本：需要额外采购运放。
- 运放对比：

| 参数 | OPA695 | OPA690 | OPA820 | LMH6609 | LMH6624 | LMH6629 |
| --- | --- | --- | --- | --- | :--- | --- |
| 拓扑结构 | 电流反馈 (CFB） | 电压反馈 (VFB） | 电压反馈 (VFB） | 电压反馈 (VFB） | 电压反馈 (VFB） | 电压反馈 (VFB） |
| -3dB 带宽 | 1900MHz (G=1） | 535MHz (G=1） | 240MHz (G=2） | 900MHz (G=1） | 1.5 GHz | 900 MHz |
| 压摆率 (SR） | 5000 V/µs | 1900 V/µs | 240 V/µs | 1400 V/µs | 350 V/µs | 1600 V/µs |
| 输出电流 (Iout） | ±140 mA | ±215 mA | ±110 mA | ±90 mA | - | ±250 mA |
| 电压噪声 (eₙ） | 2 nV/√Hz | 4.6 nV/√Hz | 2.5 nV/√Hz | 3.1 nV/√Hz | 0.92 nV/√Hz | 0.69 nV/√Hz |
| 电源电压 | 5V 至 12V | 5V 至 12V | 5V 至 12V | 6.6V 至 12V | 5V 至 12V| 2.7V 至 5.5V |
| 最小稳定增益 | 灵活 (CFB特性） | 单位增益稳定 | 单位增益稳定 | 单位增益稳定 | ≥ 10 | ≥ 4 或 10 |
| 封装 | SOIC-8 | SOIC-8 | SOIC-8 | SOIC-8 | SOIC-8 | SOT-23 |
| TI 官网价格 | $2.274 | $3.520 | $2.245 | $1.657 | $3.128 | $3.300 |
| 立创商城价格[^1] | ￥11.29 | ￥39.64 | ￥20.14 | ￥34.06 | ￥41.54 | ￥32.02 |

> 注：淘宝价格比上表中价格低，接近 TI 官网批量价格，但是不能排除是拆机片的可能性，需要谨慎。

[^1]: 立创商城价格数据为 2026-08-09。

- 电路性能：
  - 噪声、带宽、压摆率：参照上表
  - 稳定性：电压反馈运放稳定性较好，不需要额外计算反馈电阻
  - 增益：电压反馈运放可以在较大范围内选择反馈电阻，规避了电流反馈运放在对应增益下需要选择特定电阻，导致输入阻抗没办法满足 50Ω 的限制。
  
### 方案三：在差分转单端前加电压跟随器
- 提出逻辑：在差分转单端前加电压跟随器，50Ω 匹配由电压跟随器完成，差分放大器无需考虑输入阻抗。
- PCB 修改方便性：需要额外修改 PCB，增加电压跟随器电路。
- 成本：需要额外采购运放，需要重新设计打样 PCB。
- 电路性能：
  - 噪声：由于多加了一级运放，噪声会有一定程度的增加。
  - 带宽：OPA695为电流反馈性运放，带宽不随增益改变，所以带宽瓶颈在前置的电压跟随器中，由于电压跟随器增益 G = 1，相比于方案二的 G = 6 V/V，所需带宽会降低，对运放选型更友好。
  - 压摆率：没有更换输出级运放，压摆率不变。
  - 稳定性：反馈只在每一级之内进行，对稳定性影响较小。
  - 增益：电压跟随器增益为 1，差分放大器增益为 6，整体增益为 6 V/V。
  - CMRR：由于组成电压跟随器的运放的失调电压大概率不同，导致 CMRR 下降。

## 决策
由于模拟板 MVP 已经打板，**暂时采用方案二，选用 LMH6609 进行评估，若实际效果不佳，则在模拟板 v1.0 改用方案三**

## 后果
### 正面影响
- 可以不用修改 PCB，直接更换运放。
- 能够完成 50Ω 输入阻抗要求。
- 电路性能满足要求。
- 电压反馈运放对寄生参数的要求较低，稳定性较好。

### 负面影响
- 需要额外采购运放。
- 高带宽的电压反馈运放成本较高。

### 替代方案放弃理由
- 方案一：稳定性、CMRR、增益均受影响。
- 方案三：需要额外修改 PCB，增加成本，且电压跟随器会额外引入噪声。

## 相关文档
- [硬件架构文档](/docs/硬件架构文档.md)
- [硬件设计文档（模拟板）](/docs/硬件设计文档/硬件设计文档(模拟板).md)

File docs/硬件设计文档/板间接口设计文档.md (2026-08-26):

<!------------------------------------------------------------------------
SPDX-License-Identifier: CC-BY-SA-4.0
Copyright (C) 2026 [EERNINUO]

This work is licensed under the Creative Commons Attribution-ShareAlike 4.0 International License. 
To view a copy of this license, visit http://creativecommons.org/licenses/by-sa/4.0/.
------------------------------------------------------------------------->

<!-- Assisted-by: DeepSeek - 文档框架 -->

# ArbWave30 – 板间接口设计文档

| 文档编号 | ArbWave30-BIID-001 | 版本 | V1.2  |
| ---| --- | ---- | ----- |
| 项目名称 | ArbWave30 | 日期 | 2026-05-26 |
| 起草人 | EERNINUO | 状态 | 草案 |

## 1. 概述
本文档定义了 ArbWave30 项目中**控制板**与**模拟板**之间所有物理和电气接口。控制板负责电源输入、初级转换、USB通信及 SCPI 解析；模拟板承载 FPGA、DAC 及模拟前端。

两板之间通过**两种连接器**互联：
- **主电源连接器 J_PWR**：传输 ±18V 功率电源（后续由 LDO 转为 ±15V 等）。
- **信号/辅助电源连接器 J_SIG**：传输数字控制信号（SPI、I2C、复位等）以及低压辅助电源（+3.3V_D）。

双方设计、布局、布线以及固件开发均须以本文档为唯一依据。

## 2. 连接器选型与机械要求

### 2.1 主电源连接器 (J_PWR)

| 项目 | 规格 |
|---|---|
| **类型** | XH2.54 间距，线对板，直插或弯插（根据结构决定） |
| **针数** | 8 针（预留冗余） |
| **额定电流** | 3A/针（实际需求 < 2A/针，充足余量） |
| **接触电阻** | ≤10mΩ |
| **耐压** | ≥250V |
| **工作温度** | -40℃ \~ +105℃ |
| **选型理由** | XH 连接器应用广泛、成本低廉，自带卡扣防止脱落。 |

### 2.2 信号连接器 (J_SIG)

| 项目 | 规格 |
|---|---|
| **类型** | DC3 牛角座，2.54mm 间距 |
| **针数** | 2×8P (16P)  |
| **额定电流** | 单针 1A（实际 < 200mA/针，降额充足） |
| **接触电阻** | ≤20mΩ |
| **工作温度** | -40℃ \~ +105℃ |
| **选型理由** | 实验室环境振动小，脱落可能性小，镀金触点保证信号完整性；可同时传输低压电源。 |

### 2.3 机械装配要求

- **J_PWR 位置**：靠近板边，便于线束引出。
- **J_SIG 位置**：与 J_PWR 间隔至少 10mm，避免线束干涉。
- **排线长度**：J_SIG 使用的排线长度建议 ≤10cm，以保持 SPI 信号完整性。
- **防呆设计**：牛角座和 XH 连接器均有缺口定位，确保正确插入方向。

## 3. 引脚定义

### 3.1 主电源连接器 (J_PWR)

**引脚排列** 缺口朝上，左侧为1脚

| 引脚号 | 信号名 | 方向 | 额定电流 | 说明 |
|---|---|---|---|---|
| 1 | +17V_M | 控制板 → 模拟板 | 1A | 正电源轨，用于生成 +15V_A |
| 2 | GND_PWR | - | - | 功率地回路 |
| 3 | -17V_M | 控制板 → 模拟板 | 1A | 与引脚 3 并联，分摊电流 |
| 4 | +7V_M | 控制板 → 模拟板 | 0.6A | 负电源轨，用于生成 -15V_A |
| 5 | GND_PWR | - | - | 功率地回路 |
| 6 | -7V_M | 控制板 → 模拟板 | 0.6A | 与引脚 4 并联，分摊电流 |
| 7 | GND_PWR | - | - | - | 功率地回路 |
| 8 | 3.3V_D | 控制板 → 模拟板 | 1A | 数字电源，供 FPGA IO、 DAC 数字部分和模拟前端继电器使用 |

### 3.2 信号连接器 (J_SIG){#3.2-信号连接器-J_SIG}

**引脚排列**（2×8P，牛角座缺口朝左，1脚为左上，逆时针编号）

| 引脚 | 信号名 | 方向 | 电平 | 说明 |
|---|---|---|---|-----|
| 1 | CS | 控制板 → 模拟板 | 3.3V | SPI 片选（低有效） |
| 2 | CLK | 控制板 → 模拟板 | 3.3V | SPI 时钟 |
| 3 | MISO | 模拟板 → 控制板 | 3.3V | SPI 从出主入 |
| 4 | MOSI | 控制板 → 模拟板 | 3.3V | SPI 主出从入 |
| 5 | NC | - | - | 预留 |
| 6 | FPGA_NRST | 控制板 → 模拟板 | 3.3V | 复位 FPGA（低有效）|
| 7 | FPGA_INT | 模拟板 → 控制板 | 3.3V | FPGA状态/中断输出。高电平=中断请求或FPGA未就绪，低电平=正常运行。MCU端弱上拉(10kΩ)。 |
| 8 | GPIO2 | 双向 | 3.3V | 备用 GPIO |
| 9 | GND | - | - | 地 |
| 10 | GND | - | - | 地 |
| 11 | GND | - | - | 地 | 
| 12 | GND | - | - | 地 |
| 13 | GND | - | - | 地 |
| 14 | GND | - | - | 地 |
| 15 | GND | - | - | 地 |
| 16 | GND | - | - | 地 |

## 4. 电气特性规范

### 4.1 数字信号电平

| 参数 | 最小值 | 典型值 | 最大值 | 单位 |
|---|---|---|---|---|
| VOH | 2.4 | 3.3 | - | V |
| VOL | - | 0 | 0.4 | V |
| VIH | 2.0 | - | 3.6 | V |
| VIL | -0.3 | - | 0.8 | V |
| 上升/下降时间 | - | - | 10 | ns |

### 4.2 电源轨纹波要求

| 电源轨 | 最大纹波 (峰峰值) | 测试条件 |
|---|---|---|
| +3.3V_D | 50mV | 10Hz \~ 20MHz |
| +18V_M | 100mV | 10Hz \~ 20MHz |
| -18V_M | 100mV | 10Hz \~ 20MHz |

### 4.3 时序要求

- **SPI**：时钟频率 ≤10MHz，数据建立时间 ≥10ns，保持时间 ≥10ns。
- **FPGA_RST**：低电平脉冲宽度 ≥100ns。
- **上电顺序**：建议先有 +3.3V_D，后 +1.0V_D（FPGA 内核需要 IO 电源先上电）。

## 5. 电源去耦与滤波责任划分

| 位置 | 去耦要求 |
|---|---|
| **控制板（输出侧）** | J_PWR 每个电源引脚附近放置 22μF 电容 + 0.1μF。J_SIG 的 +3.3V_D  同样放置 22μF + 0.1μF。 |
| **模拟板（输入侧）** | 连接器入口处每个电源引脚再放 10μF + 0.1μF。负载处设计详见[模拟板电源设计](./硬件设计文档(模拟板).md#模拟板电源设计) |

## 6. 接地与信号完整性策略

- **地平面**：两板均使用**完整地平面**，不分割数字地/模拟地。
- **接地引脚分配**：J_SIG 中每 2\~3 个信号引脚至少配一个 GND 引脚（已满足）。
- **电源回路**：±18V 的返回电流通过 J_PWR 的 GND 引脚回到控制板，不得与信号地混用同一引脚。
- **时钟信号**：150MHz DAC 时钟在模拟板上产生，不经过连接器。J_SIG 上的 SPI_CLK 频率较低（≤10MHz），无需特殊阻抗控制，但走线应尽量短。

## 7. 测试验证方法

| 测试项 | 方法 | 通过判据 |
|---|---|---|
| 连通性 | 万用表蜂鸣档 | 每个引脚接触电阻 < 1Ω |
| 电源纹波 | 示波器（地弹簧）测量模拟板入口 | 满足 4.2 节要求 |
| 信号质量 | 示波器测 SPI_CLK 上升沿（模拟板侧） | 过冲 < 0.5V，振铃 < 20% |
| 通信测试 | 控制板发送 SPI 命令，FPGA 回读 | 无误码 |
| 温升测试 | 满载运行 30 分钟，测连接器外壳温度 | < 50℃（环境 25℃） |

## 8. 版本记录

| 版本 | 日期 | 修改内容 | 修改人 |
|---|---|---|---|
| V1.0 | 2026-04-25 | 初始版本 | EERNINUO |
| v1.1 | 2026-05-05 | 修改电源引脚分配，将 3.3V_D 移动到电源连接器，修改电源连接器选型 | EERNINUO |
| v1.2 | 2026-05-26 | 修改电源引脚分配，将 ±7V 生成移至控制板| EERNINUO |

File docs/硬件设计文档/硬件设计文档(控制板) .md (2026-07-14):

<!------------------------------------------------------------------------
SPDX-License-Identifier: CC-BY-SA-4.0
Copyright (C) 2026 [EERNINUO]

This work is licensed under the Creative Commons Attribution-ShareAlike 4.0 International License. 
To view a copy of this license, visit http://creativecommons.org/licenses/by-sa/4.0/.
------------------------------------------------------------------------->

<!-- Assisted-by: DeepSeek - 文档框架 -->

# ArbWave30 – 控制板硬件设计文档

| 文档编号 | ArbWave30-HDD-002 | 版本 | V1.1  |
| ---| --- | ---- | ----- |
| 项目名称 | ArbWave30 | 日期 | 2026-05-26 |
| 起草人 | EERNINUO | 状态 | 设计中 |

## 1. 板卡概述
- 功能定位：控制模拟板的波形生成、与PC进行USB通信、调理输入电源供给模拟板、人机交互。
- 关键性能指标：功耗、尺寸、环境要求
  - 功耗：< 5W（不包括供给模拟板的电源）
  - 尺寸：< 100mm x 100mm
  - 环境要求：0 \~ 40 ℃
- 主要接口：
  - 对外连接器：
    - 电源输入：DC2.1mm 
    - USB 接口：USB Type-B
  - 板间接口：见[板间接口文档](./板间接口设计文档.md)

## 2. 模块详细设计
### 2.1 MCU 最小系统
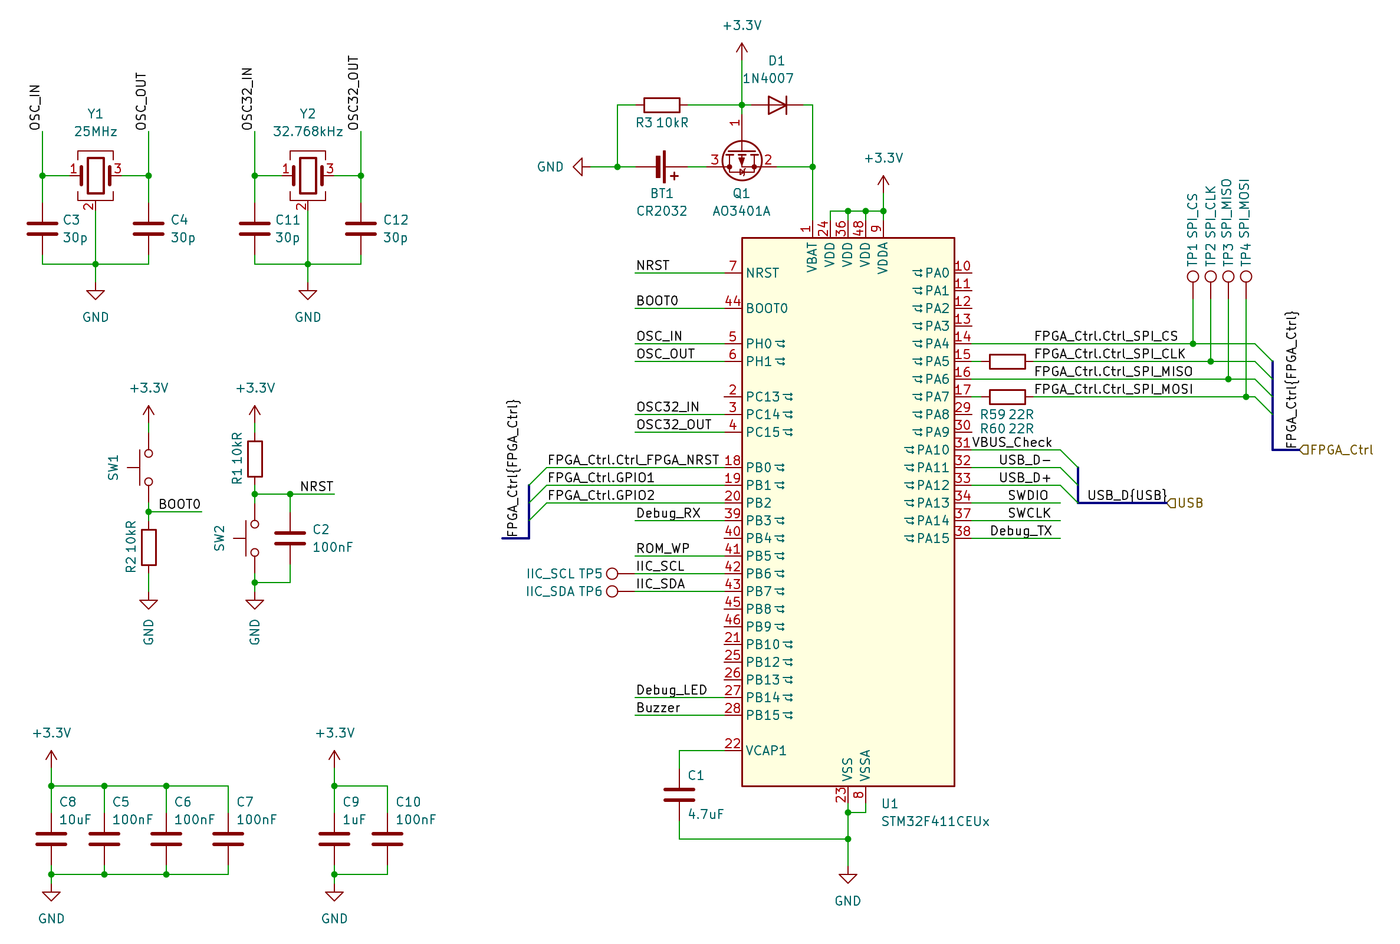
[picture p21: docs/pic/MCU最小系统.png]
MCU最小系统
- **原理图截图**：
  
- **功能描述**：
  作为整个控制板的核心，负责处理 USB 通信、解析 SCPI 命令、控制 FPGA 配置、管理用户接口（按键/编码器）以及存储用户设置。
- **关键器件**：
  
| 器件 | 型号 | 特性 | 选型理由 |
|---|-----|---|---|
| MCU | STM32F411CEU6 | ARM Cortex-M4F, 512KB Flash, 128KB RAM | 性能满足需求，成本合理 |

- **具体设计**：
  - 电源：
    - VDD: 3.3V，一个单独的10uF电容 + 每一个单独的 VDD 就近放置一个 100 nF 的陶瓷电容, 靠近芯片布局
    - VDDA: 3.3V，就近放置单独的1uF电容 + 100 nF陶瓷电容，靠近芯片布局 <!-- 锁相环是不是用这玩意供电的？ -->
    - VBAT: 3.0V，连接到CR2032电池座，提供实时时钟和备份寄存器电源，通过电源切换电路实现自动切换，当主电源断电时自动切换到电池供电，保证 RTC 和备份寄存器的数据不丢失。
    - VCAP: 连接到一个就近放置的 4.7uF 陶瓷电容，提供内部 LDO 稳压器的稳定电压。
    - VSSA/GND: 通过花焊盘连接到地平面，确保良好的接地
  - 时钟：
    - HSE：外部晶振 8MHz，尽量靠近MCU，内部 PLL 生成 96MHz 系统时钟，匹配电容根据数据手册选型。
    - LSE：外部晶振 32.768kHz，提供 RTC 时钟源，匹配电容根据数据手册选型。
  - 复位：复位引脚连接到调试接口的排针，由调试器控制，并通过一个 100nF 电容连接到地，一个 10kΩ 上拉电阻连接到 VDD（数据手册指出NRST内部已经有了约 40kΩ 的上拉电阻，但噪声环境下不一定可靠，故保留外部上拉电阻焊盘，根据具体情况调整）。
  - 调试接口：7针 2.54mm 排针，合并 SWD 和调试串口(USART1)，用于调试和烧录。
  - Boot 配置：Boot0 默认通过 10kΩ 下拉到地，需要从bootloader模式烧录时，使用按键短接 BOOT0 引脚到 3.3V。
  - SPI1: 连接到板间连接器，MOSI/CLK靠近MCU端串联 22Ω 串阻，MISO不加串联电阻，供 FPGA 控制使用。

- **接口信号**：列出输入/输出信号名称、电平、阻抗、时序要求
  | 信号名 | 方向 | 协议 | 连接到 | 备注 |
  |--------|------|------|--------|------|
  | SWDIO/SWCLK | 双向 | SWD | 调试器（ST-Link） | 用于调试和烧录 |
  | USB DP/DM | 双向 | USB 2.0 FS | USB 接口 | 差分信号，90Ω阻抗 | 
  | SPI1 | 双向 | SPI | FPGA 配置 | MOSI/CLK靠近MCU端串联 22Ω 串阻 |
  | GPIO | 输出 | GPIO | 蜂鸣器 | 三极管扩流 |  
  | IIC | 双向 | IIC | EEPROM | 100kHz |
  | UART | 双向 | UART | 调试串口 | 115200 baud rate |
  
- **保护设计**：
  - SPI1 接口：MOSI/CLK靠近MCU端串联 22Ω 串阻，MISO不加串联电阻，焊盘设计允许焊接 0Ω 电阻或直接短接。
  - USB 接口：见[USB 接口](#USB接口)部分。
  
- **测试点**： 
  - SPI1_SCK/MOSI/MISO/CS：用于示波器观察 SPI 信号质量和时序。
  - IIC_SDA/SCL：用于观察 I2C 通信波形

### 2.2 USB 接口{#USB接口}
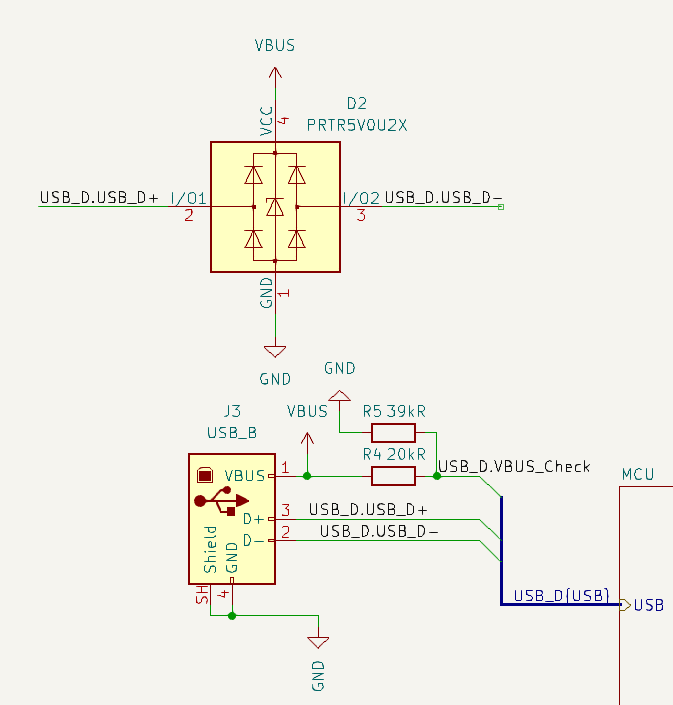
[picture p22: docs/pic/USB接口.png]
USB 接口
 - **原理图截图**: 
- **功能描述**：
  - 通过 USB-FS 接收 SCPI 命令
  - 通过 USB-FS 发送响应数据
  - 自动检测线缆插入
- **关键器件**：

| 器件 | 型号 | 特性 | 选型理由 |
|---|-----|---|---|
| USB 接口 | USB Type-B | 4线母头 USB2.0 | 连接稳定，可靠性高，行业标准 |
| ESD 芯片 | PRTR5V0U2X | 超低电容双轨对轨ESD芯片 | 保护USB接口 |

- **接口信号**：
  | 信号名 | 方向 | 协议 | 连接到 | 备注 |
  |--------|------|------|--------|------|
  | USB_DP/DM | 双向 | USB 2.0 FS | PC | CDC |
  | VBUS | 输入 | 电平 | MCU GPIO | USB 连接检测 |

- **具体设计**：
  - USB DP/DM 走差分线，阻抗控制在 90Ω，长度匹配，避免放置过孔, 靠近接口处放置 ESD 保护芯片。
  - USB 串联 22Ω 串阻可减少反射和 EMI，但ST官方不建议添加，保留焊盘，靠近 MCU 端，但焊接0Ω电阻或直接短接。
  - GND 与板卡地平面直接连接。
  - 连接器外壳通过花焊盘与地连接，提供额外的屏蔽和接地路径。
  - VBUS 线通过分压电阻分压到3.3V后连接到 MCU 的 GPIO，用于检测 USB 连接状态。
  - DP 上拉由 MCU 内部实现，无需外部 1.5k 电阻，软件配置即可。

- **保护设计**：ESD、过流、过压、防反接等
  - ESD 保护：USBLC6-4SC6Y 汽车级芯片，低电容，保护 USB DP/DM 线免受静电放电损伤。
  - 过流保护：USB 供电线（VBUS）只做检测，不直接供电，避免过流风险。
  - 防反接：USB 接口本身设计为防反插，内部电路不需要额外防反接措施。
  
- **测试点**：
  - TP_USB_DP/DM：用于示波器观察 USB 信号质量和时序。
  - TP_USB_VBUS：用于测量 USB 连接状态电压，验证连接检测功能。

### 2.3 EEPROM
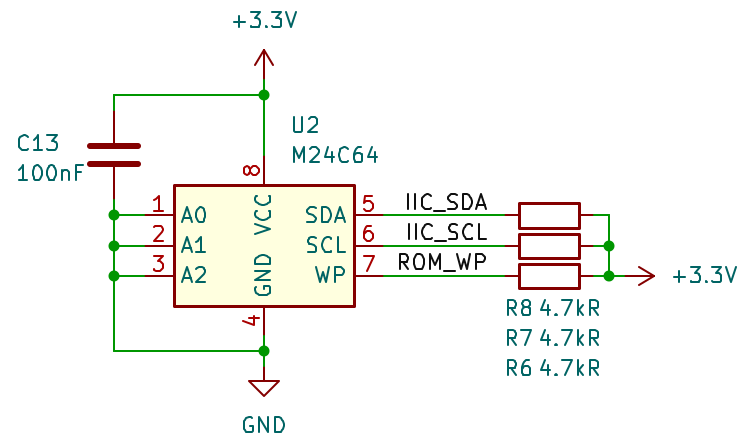
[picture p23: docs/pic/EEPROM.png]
EEPROM
- **原理图截图**: 
- **功能描述**：存储校准系数和用户设置
- **关键器件**：EEPROM: M24C64（64Kb，I2C接口），用于存储校准系数和用户设置。
- **接口信号**：
  - I2C_SDA/SCL：用于连接 EEPROM，标准模式 100kHz
  - WP：写保护引脚，连接到 MCU GPIO，通过软件控制写保护状态。

### 2.4 人机接口（v3.0实现）
> v1.0、v2.0 只支持SCPI 远程控制，v3.0支持本地操作
- **原理图截图**: <font color="red">待补充</font>
- **功能描述**：进行人机交互
- **关键器件**：

| 器件 | 型号 | 特性 | 选型理由 |
|---|-----|---|---|
| 显示屏 | 3.5寸 TFT | MIPI接口，1024x768 分辨率 | 驱动方便 |
| 编码器 | EC11-01 | 360度旋转，带按键 | 可以简化面板 |

- **具体设计**：
  - 屏幕接口通过 MIPI 输出，差分对走线，长度匹配，避免放置过孔。
  <!-- MIPI走线细节待补充 -->
  - 编码器旋转通过定时器编码器接口检测，按键通过 GPIO 中断检测，内部上拉。  
  - 按键排列成矩阵键盘，通过行列扫描法扫描键值。
  
- **接口信号**：
  
| 信号名 | 方向 | 协议 | 连接到 | 备注 |
|---|---|---|---|---|
| TFT_MIPI | 输出 | MIPI | TFT | \ |
| ENCODER_A/B/C | 输入 | 按键/编码器 | 编码器 | \ |
| 按键 | 输入 | 按键 | 按键输入 | 矩阵键盘 |
- **测试点**：
  - TP_TFT_MIPI：用于示波器观察 TFT 屏信号质量。
  - TP_ENCODER_A/B/C：用于示波器观察 编码器/按键信号质量。
  
### 2.5 调试接口
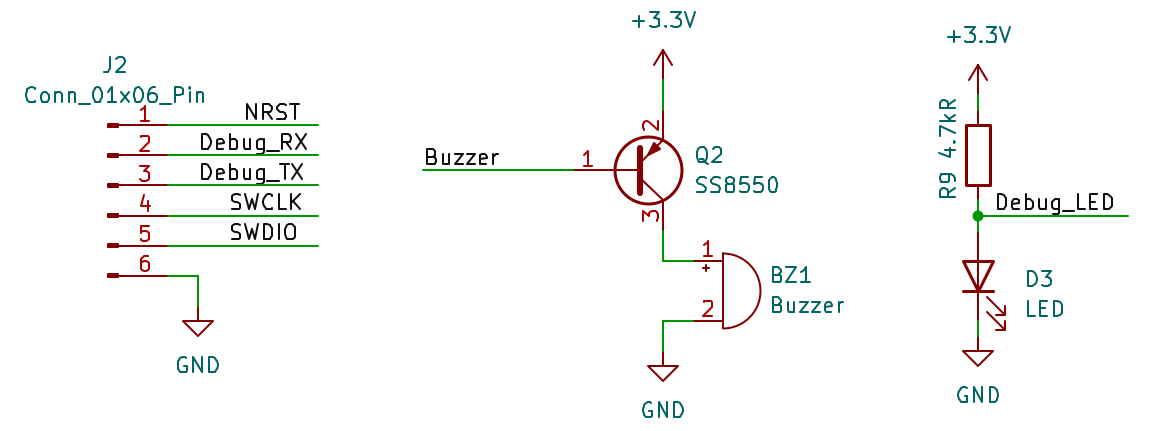
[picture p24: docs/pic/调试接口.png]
调试接口
- **原理图截图**: 
- **功能描述**：连接调试器与调试串口，下载固件
- **关键器件**：
  
  | 器件 | 型号 | 特性 | 选型理由 |
  |------|-----|------|----------|
  | 6Pin 排针 | 6Pin 排针 | 排针 | \ |
  | 蜂鸣器 | 无源蜂鸣器 | 无源蜂鸣器 | \ |

- **接口信号**：
  
  | 信号名 | 方向 | 协议 | 连接到 | 备注 |
  |-------|------|------|--------|------|
  | SWD | 双向 | SWD | 调试器（ST-Link） | 用于调试和烧录 |
  | UART | 双向 | UART | 调试输出 | 115200 baud rate |
  | GPIO | 输出 | GPIO | 蜂鸣器 | 三极管扩流 |
  |      |     |      | LED | \ |
  
- **具体设计**：
  - 调试接口引脚定义如下：
  
  | 1 | 2 | 3 | 4 | 5 | 6 |
  |---|---|---|---|---|---|
  | GND | NRST | RX | TX | SWCLK | SWDIO |
  > PCB 丝印标注引脚功能
  - GPIO引脚通过PNP三极管扩流后驱动蜂鸣器

### 2.6 电源输入与保护
- **原理图截图**（或链接）
- **功能描述**：  
  - 将输入的 24V 转为 ±17V_M、3.3V_D 电压轨，为控制板和模拟板提供稳定电源
  - 过流、过压、反接保护

- **关键器件**：

  | 器件 | 型号 | 特性 | 选型理由 |
  |------|-----|------|----------|
  | 电源输入接口 | DC2.1mm | 2.1mm DC 电源插座 | 行业标准，连接稳定，从根源上避免反接 |
  | TVS 二极管 | SMBJ24A | 24V 反向截止电压，38.9V 钳位电压，单向导通，SMB 封装 | 保护电源输入免受过压冲击 |
  | +17V_M DC-DC | TPS54360 | 3A 输出电流，24V 输入，效率高 | 用于主电源轨，效率更高，降低热量 |
  | -17V_M DC-DC | TPS54360_反向buck | 3A 输出电流，24V 输入，效率高 |  |
  | +7V_M DC-DC | TPS54360 | 3A 输出电流，17V 输入，效率高 | 用于主电源轨，效率更高，降低热量 |
  | -7V_M DC-DC | TPS54360_反向buck | 3A 输出电流，17V 输入，效率高 |  |
  | +3.3V_D DC-DC | TPS54360 | 3A 输出电流，24V 输入 | 用于数字电源轨，效率更高，降低热量 |

- **设计计算**：
1. **具体设计**
  - **+17V_M 电源设计**：
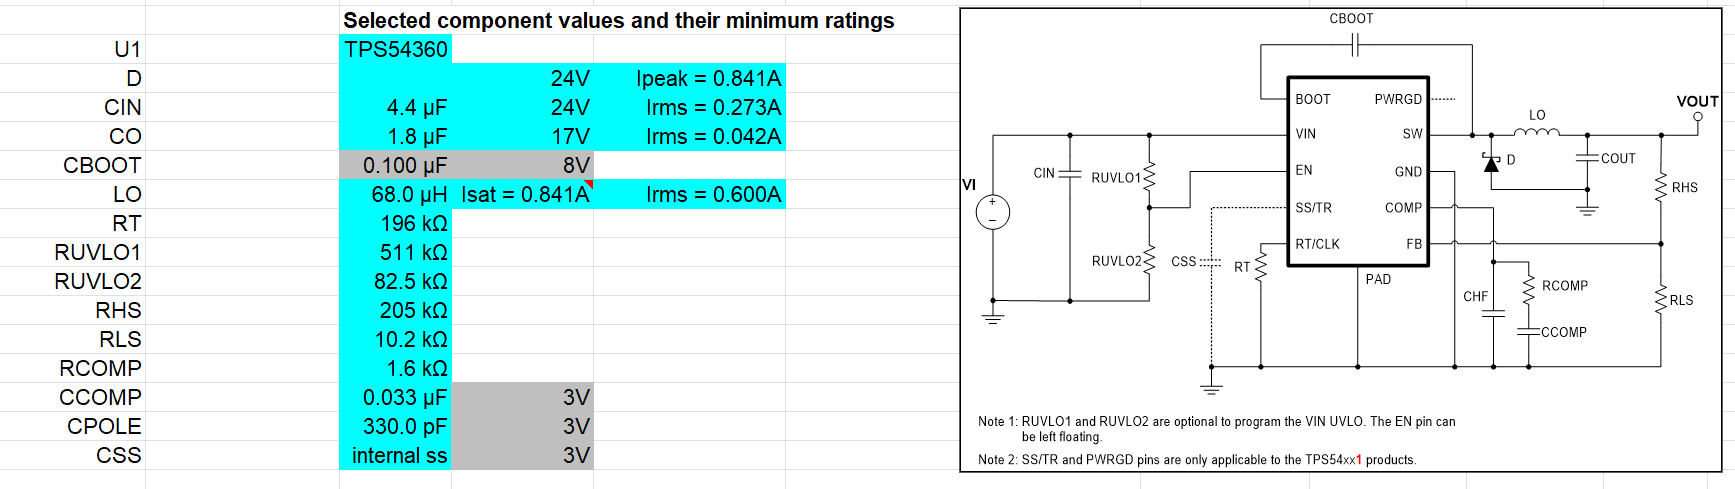
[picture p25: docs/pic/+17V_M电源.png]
+17V_M
  
  </br>

  - **-17V_M 电源设计**：
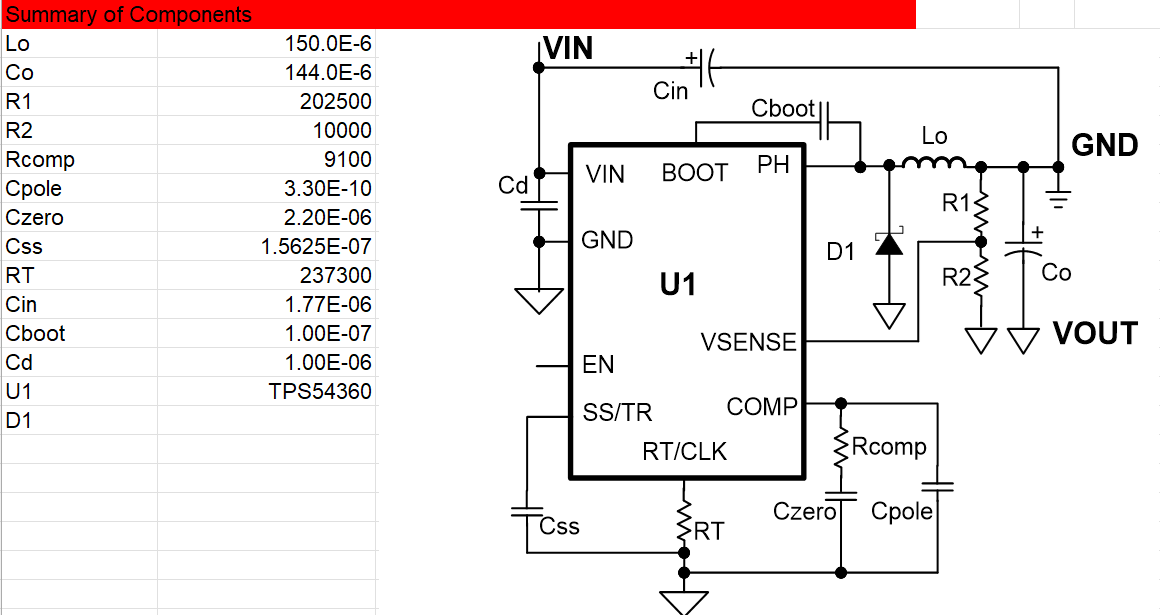
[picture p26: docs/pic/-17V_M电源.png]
-17V_M
  
  </br>

  - **+7V_M 电源设计**：
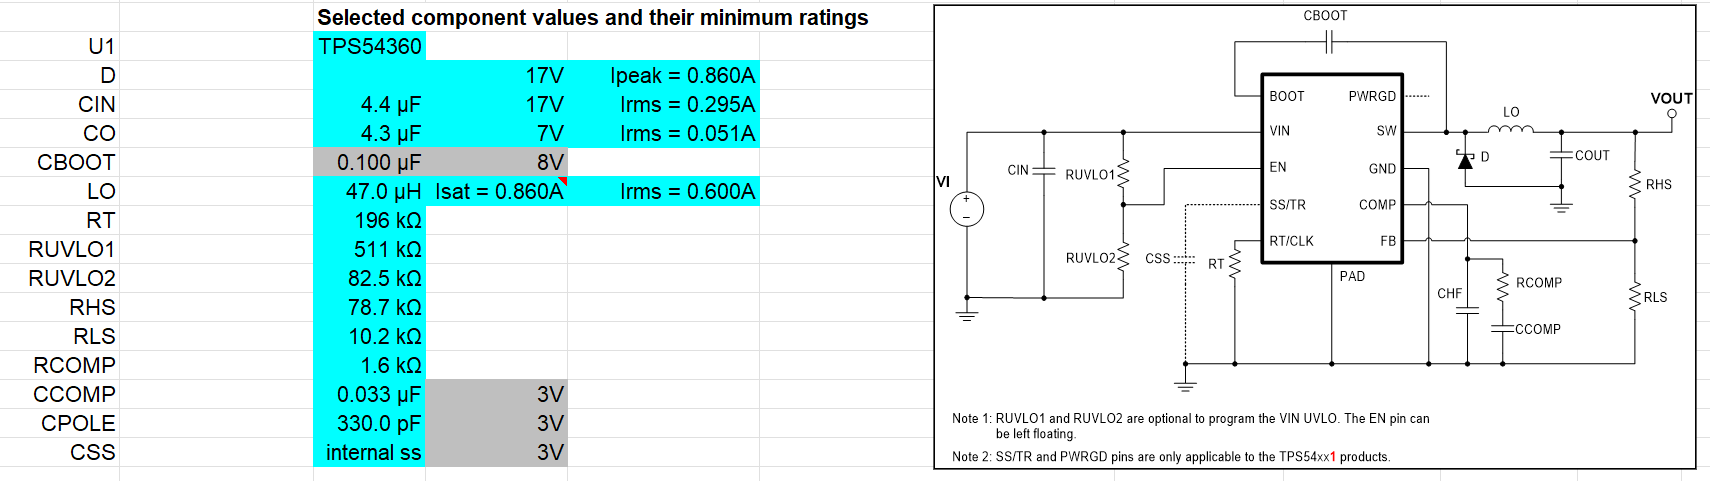
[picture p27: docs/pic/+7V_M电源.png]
+7V_M
  
  </br>

  - **-7V_M 电源设计**：
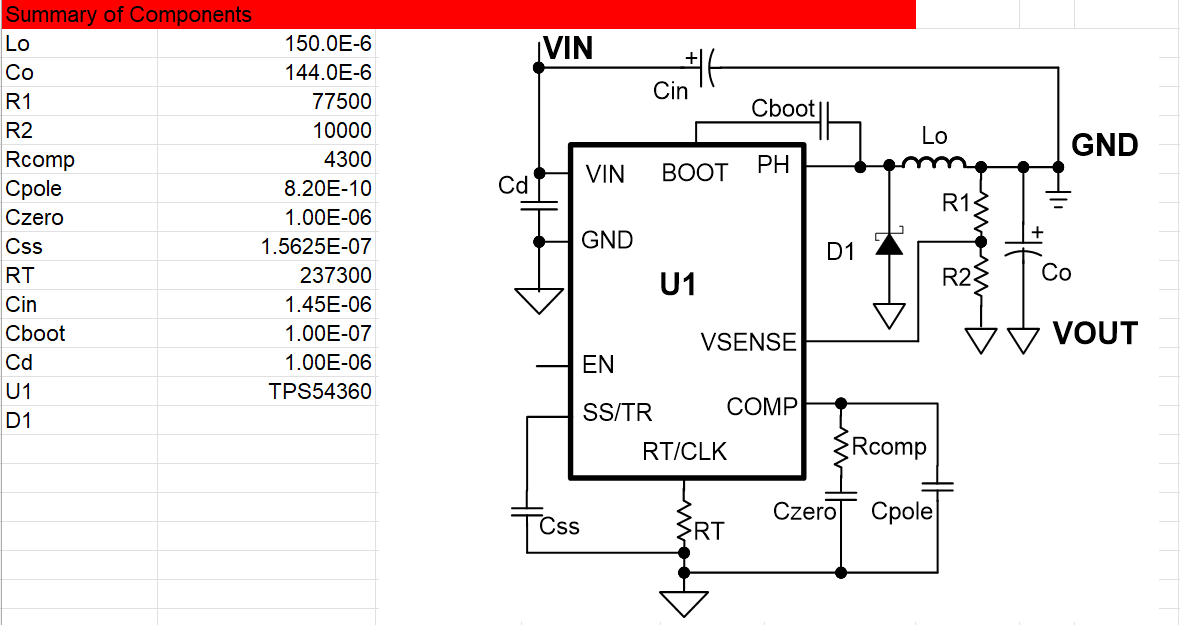
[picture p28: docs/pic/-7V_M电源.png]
-7V_M
  
  </br>

2. **注意事项**
  - DCDC 电路的低电压端（正向 buck 的 GND，反向 buck 的 Vout-）都通过大量过孔连接到对应的铜皮以保证回流路径低阻抗
  - SW 节点面积尽量小，且远离敏感信号线
  - 热焊盘通过大量过孔接到底层铜箔（GND 或 Vout-）
  - 输出电容可适量加大，选择大容量的电解电容配合低 ESR 的 MLCC ，可以确保稳定性和降低纹波
  - 输入端加大电容，降低输入纹波对电路的影响，需要注意电容的耐压值

- **保护设计**：ESD、过流、过压、防反接等
- **测试点**：
  - +17V，-17V 电压轨：测量点，纹波测试点
  - +7V，-7V 电压轨：测量点，纹波测试点 
  - 3.3V_D 电压轨：测量点

## 3. PCB 布局与布线指南
### 3.1 层叠结构
  - 层数：4 层
  - 层序：
    - Top：信号 + 电源局部走线 + 元件
    - Inner1：完整地平面（GND）
    - Inner2：电源分割层（+3.3V_D, +18V_M, -18V_M 等）
    - Bottom：信号 + 少量地线 + 辅助电源走线
  - 厚度：1.6mm 总厚，50Ω 单端走线宽度计算（例如 0.25mm 线宽，参考地平面）。
  - 铜厚：1oz（35μm）内外层。

### 3.2 整体布局原则
1. 按功能分区
  - 电源输入区（DC 插座、TVS、防反接、DC-DC）
  - MCU 区（STM32、晶振、SWD、USB）
  - 连接器区（到模拟板的排针、触发 SMA）
  - 预留扩展区（按键、TFT 排针）

2. 电源路径
  - DC 输入 → 保险丝/TVS → 防反接 → 大电容（100μF） → DC-DC 输入。
  - DC-DC 输出电容紧贴电感输出端。
  - 电源走线先经过电容再到负载。

3. 热管理
  - DC-DC 芯片底部打过孔散热，顶层铺铜加阻焊开窗。
  - 电感下方禁止走敏感信号线。

4. 接口位置
  - USB 连接器放板边，方便插拔。
  - 连接器（到模拟板）集中放置，保证排针间距匹配。
  - SMA 触发口放板边，远离 DC-DC。

### 3.3 关键模块布线约束

| 模块 | 约束 | 说明 |
|---|---|---|
| USB (DP/DM) | 差分阻抗 90Ω，线宽/间距根据叠层计算；等长误差 < 1mm；远离 DC-DC 和时钟 |  |
| SWD 调试口 | 靠近 MCU，CLK 串 22Ω 电阻，避免长线 | 便于烧录 |
| 晶振 (8MHz) | 距离 MCU OSC_IN/OUT < 5mm，包地，底部不走信号线，外壳接地 | 减少辐射 |
| DC-DC 开关节点 | 走线尽量短而宽，SW 节点不铺铜过大，反馈电阻紧贴 FB 引脚 | 降低 EMI |
| 板间连接器信号 | SPI、I2C、复位信号并行走线时，彼此间距 > 3 倍线宽；下方参考地连续 | 避免串扰 |

### 3.4 地平面处理
- 整个数字板单点接地：所有地直接通过过孔连接到 Inner1 地平面，不分割。
- DC-DC 的功率地（PGND）与信号地（AGND）在芯片下方单点连接（通过 0Ω 电阻或铜皮直接相连）。
- 连接器处的 GND 引脚至少安排 30% 以上，分散排布。

### 3.5 电源完整性
  - 每个 IC 电源引脚：一个 0.1μF + 一个 1μF 电容，尽量放在同一面且紧贴引脚。
  - 板间连接器附近放置 10μF 和 0.1μF 电容，为模拟板提供干净的供电入口。
  - 使用 电源层分割：+3.3V_D 走内层大面积，+18V_M 与 -18V_M 走顶层或底层加宽走线（> 1.5mm）。

### 3.6 可测试性设计
  - 预留测试点：+18V_M, -18V_M, +3.3V_D, GND, SPI_CLK, SPI_MOSI, 连接器的关键信号。
  - 测试点形式：直径 1mm 的圆形露铜焊盘，加过孔增强固定。

### 3.7 布线检查清单（供自检）
  - 所有电源输入有足够电容。
  - 晶振负载电容走线尽量短，无多余分支。
  - USB 差分线附近无开关电源电感。
  - 连接器附近无长距离平行敏感信号。
  - DC-DC 输出纹波在预期内（用示波器实测）。

## 4. 测试与调试
### 4.1 测试点位置
所有电源轨、关键信号线（如 SPI 总线、USB DP/DM）预留测试点
### 4.2 上电前检查清单（短路测试、电源电压测量）
### 4.3 单板独立测试步骤：
分步上电：先焊电源部分，验证各电压轨；再焊STM32，烧录代码；接着焊外设验证USB，EEPROM等是否正常，最后焊连接器，测试与模拟板的通信。
关键波形测试点：
  - USB DP/DM 波形（示波器观察）
  - SPI 信号（时钟、数据）波形
模块测试：
  - 电源测试（空载、负载纹波）
  - 数字通信环回测试（SPI、I2C）
  - 模拟通道静态测试（DAC 输出固定码、测量电压）
  - 动态测试（用示波器观察波形）
- 常见故障排查指南

## 5. 元器件清单（BOM 摘要）
- 只列出关键/易错器件（阻容感值、精度、封装、耐压、温度系数）
- 完整 BOM 另存为 CSV 文件，此处放链接

## 6. 版本记录
| 版本 | 日期 | 修改内容 | 修改人 |
|---|---|---|---|
| V1.0 | 2026-04-25 | 初始版本 | EERNINUO |
| v1.1 | 2026-05-26 | 修改电源引脚分配，将 ±7V 生成移至控制板| EERNINUO |

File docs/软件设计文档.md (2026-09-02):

<!------------------------------------------------------------------------
SPDX-License-Identifier: CC-BY-SA-4.0
Copyright (C) 2026 [EERNINUO]

This work is licensed under the Creative Commons Attribution-ShareAlike 4.0 International License. 
To view a copy of this license, visit http://creativecommons.org/licenses/by-sa/4.0/.
------------------------------------------------------------------------->

<!-- Assisted-by: DeepSeek - 文档框架 -->

# ArbWave30 – 软件设计文档

| 文档编号 | ArbWave30-SDD-001 | 版本 | V1.0  |
| ---| --- | ---- | ----- |
| 项目名称 | ArbWave30 | 日期 | 2026-04-24 |
| 起草人 | EERNINUO | 状态 | 设计中 |

## 1. 概述
### 1.1 文档目的
本文档为ArbWave30项目的软件实现提供详细设计指导，旨在明确：
- 软件模块划分、接口定义及内部逻辑。
- 关键算法（如DDS、SCPI解析）的具体实现方案。
- 任务调度策略和实时性保障措施。
- 通信协议（SPI、USB）的帧格式与时序要求。

### 1.2 参考文档
| 文档名称 | 版本 | 说明 |
|---|---|---|
| 项目技术规格书 | V1.2 | 功能需求与性能指标来源 |
| 硬件架构文档 | V1.5 | 硬件模块划分与接口定义 |
| AD9747 数据手册 | Rev.0 | DAC时序与SPI控制细节 |
| GW2AR 数据手册 | V1.0 | FPGA IO约束与PLL配置 |

### 1.3 软件架构概述
- 软件组成：
    - MCU 固件（STM32F411）：SCPI 解析、USB 通信、FPGA 配置、UI 处理（按键/编码器）、非易失存储。
    - FPGA 逻辑（Verilog）：DDS 引擎、波形存储器、并口时序、SPI 从机接口。
    - 上位机测试脚本（Python + PyVISA，可选）。
- 开发环境：
  - MCU: Keil（MCU）
  - FPGA: GOWIN 云源
  - 测试脚本：Python 3.12

## 2. 软件架构
模拟板MVP软件架构

## 3. 板间通信协议（MCU ↔ FPGA）
### 3.1 物理层
| 参数 | 规格 | 备注 |
|---|---|---|
| 接口 | SPI | 4线制（CS、SCK、MOSI、MISO） |
| 工作模式 | Mode 0 | CPOL=0, CPHA=0（SCK空闲低电平，上升沿采样） |
| 最大时钟频率 | 10 MHz | 受板间连接器排线长度限制 |
| 数据位序 | MSB First | 每字节内高位先传输 |
| 字节序 | Little-Endian | 多字节数值低字节在前（与STM32原生一致）|
| 逻辑电平 | 3.3V LVCMOS | 与FPGA Bank电压匹配 |
> **硬件连接**：具体引脚定义参见[《板间接口设计文档》第3.2节 信号连接器 (J_SIG)](/docs/硬件设计文档/板间接口设计文档.md#3.2-信号连接器-J_SIG)。

### 3.2 协议帧格式
寻址（1 Byte） -> 数据内容（2 Bytes） -> CRC8 -> ACK（1 Byte）



#### 3.2.1 寻址字节

| 位 | 功能描述 | 备注 |
|-----|---|---|
| bit7 | R/W# | 0 = 写操作（MCU → FPGA），1 = 读操作（FPGA → MCU） |
| bit6\~0 | 寄存器地址 | 寄存器地址（0~127），详见第3.3节寄存器映射表 |

#### 3.2.2 数据内容
所有寄存器统一为 16 位宽度。多字节传输时采用小端序：
  - 最低有效字节（LSB）最先出现在MOSI线上
  - 最高有效字节（MSB）最后出现
示例：写入 0x1234 到地址0x00时，MOSI上的字节序列为：
```text
[0x00]   [0x34][0x12]   [CRC_H]
 地址   数据域（小端序）   CRC16
```

#### 3.2.3 CRC8校验
算法：CRC-8
多项式：0x07（$X^8 + X^2 + X^1 + 1$）
初始值：0x00
计算范围：从寻址字节开始，到数据内容的最后一个字节结束，不包含 CRC 和 ACK 字节。

#### 3.2.4 ACK字节
| 位 | 功能描述 | 备注 |
|-----|---|---|
| bit7~4 | - | 保留（默认为0） |
| bit3 | CRC_ERR | CRC 校验错误，读操作时固定为 0 |
| bit2 | BUSY | FPGA 忙 |
| bit1 | ADDR_ERR | 寄存器地址错误 |
| bit0 | ACK | 应答标志，当且仅当 bit7~bit1 全部为 0 时，该位为 1 |
```verilog
  bit0 = ~( | bit[7:1] )
``` 

### 3.3 寄存器映射表（Register Map）
寄存器映射采用绝对地址映射，将地址空间划分为三个功能区域，避免通道与全局控制耦合。
所有寄存器都是 16 位宽，保留位写入时应保持为0。

#### 3.3.1 寄存器类型
| 类型 | 描述 | 备注 |
|---|---|---|
| R | 只读 | 不可写入，只读 |
| RW | 读写 | 可读写 |
| RWC | 读清除 | 读操作后自动清零 |
| WS | 自清零 | 完成操作后自动清零 |
| W1C | 写1清除 | 写1清除对应位，不可读 |

#### 3.3.2 寄存器映射总表
区域 A：系统/全局寄存器 （地址 0x00 ~ 0x0F） 
| 地址 | 名称 | 类型 | 默认值 | 描述 |
|---|---|-----|---|---|
| 0x00 | SYS_ID_L | R | 0x4257 | 设备标识。固定返回 0x4257 （ASCII "BW"） |
| 0x01 | SYS_ID_H | R | 0x4152 | 设备标识。固定返回 0x4152 （ASCII "AR"） |
| 0x02 | SYS_CTRL | 混合 |  | 系统控制 （时钟源、软复位等） |
| 0x03 | SYS_STATUS | R |  | 系统状态 （PLL锁定、温度告警等） |
| 0x04 ~ 0x0F | Reserved | - | 0x00 | - |

区域 B：通道1寄存器 （地址 0x10 ~ 0x1F） 
| 地址 | 名称 | 类型 | 默认值 | 描述 |
|---|---|-----|---|---|
| 0x10 | CH1_CTRL | WR  |  | 通道1控制 （波形选择、输出使能等） |
| 0x11 | CH1_FREQ_L | RW | 0x00 | 通道1频率控制字低 16 位 |
| 0x12 | CH1_FREQ_M | RW | 0x00 | 通道1频率控制字中 16 位 |
| 0x13 | CH1_FREQ_H | RW | 0x00 | 通道1频率控制字高 16 位 |
| 0x14 | CH1_AMPL | RW | 0x00 | 通道1幅值控制字，int16 类型 |
| 0x15 | CH1_OFFSET | RW | 0x00 | 通道1偏置控制字，int16 类型 |
| 0x16 | CH1_PHASE  | RW | 0x00 | 通道1相位控制字，uint16 类型 |
| 0x17 | CH1_DUTY | RW | 0x7FFF | 通道1占空比（方波）/对称度（三角波）控制字，uint16 类型 |
| 0x18 | CH1_SLOPE_UP_L | R | 0x00 | 通道1上升边斜率低 16 位 |
| 0x19 | CH1_SLOPE_UP_H | R | 0x00 | 通道1上升边斜率高 16 位 |
| 0x1A | CH1_SLOPE_DOWN_L | R | 0x00 | 通道1下降边斜率低 16 位 |
| 0x1B | CH1_SLOPE_DOWN_H | R | 0x00 | 通道1下降边斜率高 16 位 |
| 0x1C ~ 0x1F | Reserved | - | 0x00 | - |

区域 C：通道2寄存器 （地址 0x20 ~ 0x2F） 
| 地址 | 名称 | 类型 | 默认值 | 描述 |
|---|---|-----|---|---|
| 0x20 | CH2_CTRL | WR |  通道2控制 （波形选择、输出使能等） |
| 0x21 | CH2_FREQ_L | RW | 0x00 | 通道2频率控制字低 16 位 |
| 0x22 | CH2_FREQ_M | RW | 0x00 | 通道2频率控制字中 16 位 |
| 0x23 | CH2_FREQ_H | RW | 0x00 | 通道2频率控制字高 16 位 |
| 0x24 | CH2_AMPL | RW | 0x00 | 通道2幅值控制字，int16 类型 |
| 0x25 | CH2_OFFSET | RW | 0x00 | 通道2偏置控制字，int16 类型 |
| 0x26 | CH2_PHASE  | RW | 0x00 | 通道2相位控制字，uint16 类型 |
| 0x27 | CH2_DUTY | RW | 07FFF | 通道2占空比（方波）/对称度（三角波）控制字，uint16 类型 |
| 0x18 | CH2_SLOPE_UP_L | R | 0x00 | 通道2上升边斜率低 16 位 |
| 0x19 | CH2_SLOPE_UP_H | R | 0x00 | 通道2上升边斜率高 16 位 |
| 0x1A | CH2_SLOPE_DOWN_L | R | 0x00 | 通道2下降边斜率低 16 位 |
| 0x1B | CH2_SLOPE_DOWN_H | R | 0x00 | 通道2下降边斜率高 16 位 |
| 0x28 ~ 0x2F | Reserved | - | 0x00 | - |

区域 D: DAC 寄存器映射 （地址 0x30 ~ 0x3B，对应 DAC 寄存器 0x00 ~ 0x12）
| 映射地址 | 原地址 | 初始值 | 名称 |
|---|---|---|---|
| 0x30\[15:8] | 0x00 | 0x00 | SPIControl |
| 0x30\[7:0]  | 0x02 | 0x00 | Data Control |
| 0x31\[15:8] | 0x03 | 0x00 | PowerDown |
| 0x31\[7:0]  | 0x0A | 0x00 | DAC Mode Select |
| 0x32\[15:8] | 0x0B | 0xF9 | DAC1 Gain LSB |
| 0x32\[7:0]  | 0x0C | 0x01 | DAC1 Gain MSB |
| 0x33\[15:8] | 0x0D | 0x00 | AUX DAC1 LSB |
| 0x33\[7:0]  | 0x0E | 0x00 | AUX DAC1 MSB |
| 0x34\[15:8] | 0x0F | 0xF9 | DAC2 Gain LSB |
| 0x34\[7:0]  | 0x10 | 0x01 | DAC2 Gain MSB |
| 0x35\[15:8] | 0x11 | 0x00 | AUX DAC2 LSB |
| 0x35\[7:0]  | 0x12 | 0x00 | AUX DAC2 MSB |
| 0x36 ~ 0x3B | - | 0x00 | - |

> **频率/相位/幅值/偏置寄存器（0x10~0x16, 0x20~0x26）均为“影子寄存器”**。
MCU 写入这些寄存器后，FPGA 内部主 DDS 参数**不会立即更新**。
只有当 MCU 向 SYS_CTRL -> UPDATE 位写 1 时，FPGA 才会将所有影子寄存器的值一次性原子性地加载到 DDS 内核。

> MCU 写 0x30~0x3B 时，只修改 FPGA 内部的 DAC 影子缓存，**不触发 SPI 传输**。
> 只有当 MCU 向 SYS_CTRL -> DAC_CMD_WRITE 写 1 时，FPGA 才将这些缓存值**一次性通过 SPI 口刷到 AD9747 中。**

#### 3.3.3 系统控制寄存器 SYS_CTRL （地址 0x02）
| 位 | 名称 | 类型 | 默认值 | 描述 |
|---|---|-----|---|---|
| \[15:4] | - | - | 0x00 | 保留 |
| \[3] | UPDATE | WS | 0x0 | 更新主寄存器值，更新完成后由硬件清除 |
| \[2] | DAC_CMD_WRITE | WS | 0x0 | 主 DAC 寄存器写入，写入完成后由硬件清除 |
| \[1] | CLOCK_SRC | WR | 0x0 | 时钟源选择，0 = 内部时钟，1 = 外部时钟 |
| \[0] | SOFT_RST | WS | 0x0 | 软件复位，和 FPGA_NRST 拉低效果相同 （写1复位，自动清0） |

#### 3.3.4 系统状态寄存器 SYS_STATUS （地址 0x03）
| 位 | 名称 | 类型 | 默认值 | 描述 |
|---|---|-----|---|---|
| bit\[15:1] | - | - | 0x00 | 保留 |
| bit\[0] | PLL_LOCK | R | 0x0 | PLL 锁定状态 |

#### 3.3.5 通道控制寄存器 CHx_CTRL （地址 0x10/0x20）
| 位 | 名称 | 类型 | 默认值 | 描述 |
|---|---|-----|---|---|
| bit\[15] | CHx_ENABLE | RW | 0 | 通道使能，0 = 禁用，1 = 使能 |
| bit\[14:6] | - | - | 0x00 | 保留 |
| bit\[5:0] | WAVEFORM | RW | 0x00 | 波形选择，波形值见下表 |

| WAVEFORM | 波形类型 | 备注 |
|---|---|---|
| 0x00 | 正弦波 | - |
| 0x01 | 方波 | - |
| 0x02 | 三角波 | - |
| 0x03 | 噪声 | - |
| 0x04 | 直流 | - |
| 0x05 ~ 0x3F | - | 保留 |

### 3.4 通信时序与流程
写时序：
SPI 写时序
<!-- 
{
    signal: [
      {name: 'CS', wave: '10...|...|...|...|...|.1'},
      {name: 'clk', wave: '0.P..|...|...|...|...|.l'},
      {name: 'mosi',wave: '0..22|222|222|222|20.|...', data: [ 'A6', ,'A0','D7', ,'D0', 'D15', ,'D8','crc7', ,'crc0'] , phase: '0.5'},
      {name: 'miso', wave:'0....|...|...|...|.22|20.', data: ['ack7',,'ack0'], phase:'0.5'}
    ],
}
 -->

读时序：
SPI 读时序
<!-- 
{
    signal: [
      {name: 'CS', wave: '10...|...|...|...|...|.1'},
      {name: 'clk', wave: '0.P..|...|...|...|...|.l'},
      {name: 'mosi',wave: '0..22|20.|...|...|...|...', data: [ 'A6', , 'A0'] , phase: '0.5'},
      {name: 'miso', wave:'0....|.22|222|222|222|20.', data: ['D7', , 'D0','D15', , 'D8', 'crc7', , 'crc0','ack7',,'ack0'], phase:'0.5'}
    ],
}
 -->
 > **CS 拉低时接收到的数据视为一帧。**
 若 CS 拉低时间段内未能收满一帧数据或未成功发送 ACK 字节，则认为该帧无效，FPGA 不做任何处理。
 若 CS 拉低后接收的数据量超出一帧数据，则超出部分无效。
 若 CS 拉低后 1ms 内传输未完成，则认为该帧无效。

### 3.5 错误处理与重试策略

本协议采用 **“帧内即时反馈 + 帧间超时重传”** 的双重错误处理机制。

#### 3.5.1 错误分类与 FPGA 响应

| 错误类型 | 触发条件 | FPGA 行为 | ACK 反馈 |
|---|---|---|---|
| **帧长度错误** | CS 拉低期间，字节数 ≠ 4 （地址+数据+CRC） 或 CS 低电平持续时间 > 1ms | 静默丢弃当前帧，寄存器保持不变 | 不发送 ACK（MISO 保持高阻或拉低） |
| **CRC 校验失败** | 接收到的 CRC 与本地计算值不匹配 | 静默丢弃当前帧，寄存器保持不变 | `bit3=1` （CRC_ERR），`bit0=0` |
| **地址越界** | 地址字节 bit6~0 > 0x3F（超出映射表范围） | 静默丢弃 | `bit1=1` （ADDR_ERR），`bit0=0` |
| **FPGA 忙** | 上一帧正在处理中 | 忽略新帧，保持不变 | `bit2=1` （BUSY），`bit0=0` |

#### 3.5.2 MCU 端处理流程

MCU 在发送完完整帧（地址+数据+CRC）后，必须在**下一个字节（即 ACK 字节）**的 SCK 上升沿采样 MISO 线。

1. **正常情况**：读取 ACK = `0x01`，操作成功，结束流程。
2. **BUSY 情况**：若读取 `bit2=1`，MCU 应等待 100μs 后重新发送**完全相同**的帧（不增加重试计数，因为这是FPGA暂时的处理延迟）。
3. **CRC_ERR**：若读取 `bit3=1`，MCU 应立即重新发送**完全相同**的帧。
4. **ADDR_ERR**：表明帧格式非法。MCU 应立即停止重传，向上层 SCPI 层报告硬件错误（错误码 `-241`，“硬件故障”），防止恶性循环。
5. **超时情况**：若 CS 拉低后 1ms 内未收到任何 ACK（或 MISO 一直为低），MCU 应视为通信超时。

#### 3.5.3 重试策略

- **最大重试次数**：3 次（针对超时，CRC_ERR 和 BUSY 状态）。
- **重试间隔**：500μs。
- **最终失败**：若 3 次重试均失败，MCU 必须：
  1. 尝试关闭当前通道输出（设置 CHx_CTRL.ENABLE = 0）以保护负载。
  2. 向上位机返回 SCPI 错误 `-241`（“FPGA 通信超时/错误”）。
  3. 置位内部错误标志位，直到收到 `*CLS` 命令前不再尝试下发参数（但允许继续尝试读取状态寄存器以排查问题）。

#### 3.5.4 特殊场景：影子寄存器更新失败

当 MCU 写入 `SYS_CTRL.UPDATE = 1` 后，FPGA 开始加载影子寄存器。
- 由于这是一个内部操作（耗时 < 1μs），MCU **不需要**等待 ACK 确认加载完成。
- MCU 可通过回读 `SYS_CTRL.UPDATE` 寄存器确认硬件是否已自动清零；若长时间（如 10ms）未清零，应视为 FPGA 内部逻辑异常，执行硬件复位（拉低 FPGA_NRST）。

### 3.6 FPGA 状态监测与中断处理

#### 3.6.1 引脚定义
| MCU引脚 | 信号名 | 方向 | 功能 |
|---|---|---|---|
| PA0 （EXTI0） | FPGA_INT | 输入 | FPGA状态指示与中断请求 |

#### 3.6.2 启动就绪检测
系统上电后，MCU按以下流程确认FPGA已正常工作：

1. MCU完成自身初始化（时钟、GPIO、SPI、I2C）。
2. 释放 FPGA_NRST（拉高），允许FPGA从SPI Flash加载配置。
3. **等待 FPGA_INT 引脚变为低电平**：
   - 设置超时时间：**200ms**（GW2AR典型加载时间<50ms，预留充足余量）。
   - 若超时仍未检测到低电平，视为FPGA加载失败，MCU应：
     - 闪烁错误指示灯（如板载LED以1Hz频率闪烁）。
     - 拒绝响应SCPI命令（返回`-241`，“硬件故障”）。
     - 允许用户通过硬件复位按键或`*RST`命令重试。
4. 检测到低电平后，**额外延时 100μs**，等待FPGA内部PLL和SPI从机状态机稳定。
5. 执行SPI握手：读取 `SYS_ID`（0x00~0x01），校验返回值是否为 `0x4152 0x4257`（"AR""BW"）。
   - 若校验通过，FPGA就绪，MCU进入正常工作模式。
   - 若校验失败，回到步骤3重试（最多3次）。

#### 3.6.3 中断触发与处理
FPGA在运行过程中，若检测到以下情况，会将 `FPGA_INT` 引脚置高，向MCU请求服务：

| 中断源 | 触发条件 | MCU响应动作 |
|---|---|---|
| PLL失锁 | CDCI6214输出时钟失锁 | 读取 `SYS_STATUS.PLL_LOCK` 确认；若失锁，重新配置时钟发生器并复位DDS |
| 温度告警 | 板载温度超过预设阈值（V2.0） | 读取温度传感器值，若超温则降低输出幅值或关闭通道 |
| DAC通信错误 | FPGA与AD9747的SPI通信失败 | 重新初始化DAC寄存器（通过`DAC_CMD_WRITE`机制） |

**中断处理流程**：

1. MCU检测到 `FPGA_INT` 下降沿，进入EXTI中断服务程序（ISR）。
2. 在ISR中：
   - **禁用中断嵌套**（避免重入）。
   - 读取 `SYS_STATUS`（地址0x03），获取中断原因。
   - 根据状态位执行相应的恢复操作。
   - 向FPGA写入 `SYS_CTRL` 清除中断标志（若FPGA内部实现了中断清除机制）。
3. FPGA检测到MCU已读取状态后，释放 `FPGA_INT`（驱动为高电平）。
4. MCU退出ISR，继续正常运行。

> **注意**：中断ISR应保持简短（< 100μs），仅执行状态读取和标志清除。复杂的恢复操作（如重新配置时钟）应推迟到后台任务中执行，通过信号量通知优先级较低的任务处理。

#### 3.6.4 异常恢复
若FPGA_INT在正常运行期间长时间保持低电平（超过100ms）：
- MCU应视为FPGA死锁或严重故障。
- 执行硬件复位（拉低FPGA_NRST 10ms后释放）。
- 重新执行3.6.2节的启动就绪检测流程。
- 若连续3次复位均失败，MCU永久报错并停止响应SCPI命令（需断电重启）。

## 4. MCU 固件详细设计
### 4.1 任务/状态机划分
列出主要任务：
- USB 数据处理任务（SCPI 命令接收、响应发送）
- SCPI 命令解析与执行任务
- 参数更新任务（将变化后的频率/幅值等通过 SPI 发送给 FPGA）
- 按键扫描及去抖任务（未来）=- 显示更新任务（未来）
- EEPROM 参数保存/恢复任务

### 4.2 SCPI 解释器设计
状态机：采用 SCPI-1999 推荐的状态机（命令树遍历）。

支持的子系统（ V1.0 必须实现的）：

```text
*IDN?, *RST, *CLS
SOURce[1]:FUNCtion {SIN|SQU|TRI|SAW|STEp|DC}
SOURce[1]:FREQuency {<value>}
SOURce[1]:VOLTage {<value>} (Vpp)
SOURce[1]:VOLTage:OFFSet {<value>}
OUTPut[1]:STATe {ON|OFF}
SYSTem:ERRor?
```

命令解析流程：接收字符 → 词法分析 → 查找命令树节点 → 执行回调 → 生成响应。

### 4.3 USB 协议栈
实现 USBCDC 类<!-- （说明选型理由，如 libopencm3 或 ST USB 库） -->
端点配置、包大小、接收/发送缓冲区管理
与 SCPI 解析器的接口（字符流）

### 4.4 非易失存储
存储内容：输出状态（ON/OFF）、输出阻抗、最近一次波形/频率/幅值/偏置。
触发条件：参数改变后延时 5 秒写入 EEPROM。
上电恢复：读取 EEPROM 并恢复至 FPGA。

## 5. FPGA 逻辑详细设计
### 5.1 模块划分
sys_ctrl：系统控制模块，控制 FPGA 的时钟、复位等。
wave_generation: 波形控制模块，根据配置寄存器生成波形。
dac_interface：DAC 接口模块，将波形数据从 FPGA 时钟域搬运到 AD9747 时钟域；
spi_master：对 AD9747 与 DAC8562 进行 SPI 控制。
spi_slave：接收 MCU 命令，更新配置寄存器。
register_block：配置寄存器模块，存储系统状态和参数等。
afe_control：输出衰减、输出阻抗继电器的控制信号.

### 5.2 DDS 关键参数计算
系统时钟 Fclk = 150MHz
相位累加器位宽 N = 48
频率控制字 FTW =  f_out × 2^N / Fclk
幅值控制字 ATW =  Vout × 2^15 / Vmax

### 5.3 信号与引脚定义

### 5.3 波形生成
正弦波：查表（至少 4096 点，16bit 输出）。
方波：相位累加器 MSB 直接输出（再经幅度控制）。
三角波：相位累加器低 N-1 位经折叠变换。

### 5.4 DAC 时序
- 数据更新：在每个DCO上升沿，将 dac_data 输出到引脚并保持满足建立时间。
- 双通道，参考 AD9747 数据手册的并行模式。

### 5.5 SPI 从机接口
时钟速度 ≤ 10MHz。
状态机：空闲 → 接收命令码 → 接收参数 → 更新寄存器 → 发送 ACK（可选）。

## 6. 任务调度与实时性
任务调度: FreeRTOS
- 列出各个任务（USB 处理、SCPI 解析、FPGA 更新）及其优先级和通信方式（队列、信号量）。
- 实时性分析：<!-- USB 命令响应时间要求 < 100ms，FPGA 参数更新要求 < 10ms。 -->

## 7.  自动化测试与脚本设计
描述 scripts/ 目录下的 Python 测试框架：
使用 PyVISA 连接仪器
测试用例结构：发送 SCPI 命令，读取示波器/万用表数据，验证是否在规格书允差内
生成测试报告（HTML/CSV）
给出一个具体测试示例：验证 10MHz 正弦波幅值精度。

## 8. 构建与烧录 
MCU：MDK。烧录方式：ST-Link / DAP Link。
FPGA：高云 IDE （Gowin） 综合 → 生成比特流 → 通过 JTAG 烧录到外部 Flash。

<!-- 版本管理：固件和 FPGA 比特流都放入 firmware/ 目录，附简要 README。 -->

## 9. 版本记录
| 版本 | 日期 | 修改内容 | 修改人 |
|---|---|---|---|
| V1.0 | 2026-04-24 | 初始版本 | EERNINUO |

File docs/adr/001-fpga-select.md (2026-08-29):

<!------------------------------------------------------------------------
SPDX-License-Identifier: CC-BY-SA-4.0
Copyright (C) 2026 [EERNINUO]

This work is licensed under the Creative Commons Attribution-ShareAlike 4.0 International License. 
To view a copy of this license, visit http://creativecommons.org/licenses/by-sa/4.0/.
------------------------------------------------------------------------->

<!-- Assisted-by: DeepSeek - 文档框架 -->

# ADR-001: 选用高云GW2AR-18 LQFP144作为主控FPGA

## 状态
已采纳 （2026-04-05）

## 背景
ArbWave30项目需要一个FPGA来实现：
- 48位DDS相位累加器（频率分辨率1μHz）
- 波形存储器（存储正弦、方波、三角、锯齿、阶梯波表，未来扩展任意波）
- 16位并行接口驱动AD9747 DAC（150MSPS）
- SPI从机接口，接收来自STM32的配置命令
我们需要选择一个封装便于手工焊接、逻辑资源足够、且成本合理的FPGA。

## 决策驱动因素
- 焊接可行性：项目为个人DIY，要求封装能用热风枪或手工烙铁焊接（拒绝BGA）。
- 逻辑资源：至少需要约10k~15k LUTs（DDS+波形表+SPI从机+并口输出）。
- 内存：波形表需要Block RAM或外部SDRAM。至少需要存储4种波形（每种1024点×14bit ≈ 7kB），未来任意波可能需要更大容量（>64kB）。
- 成本：单颗FPGA价格应控制在70元人民币以内。
- 开发工具：需要有良好的IDE支持（高云Gowin软件免费，且支持逻辑分析仪）。

## 考虑的方案
### 方案A：高云GW2A-18 LQFP144
- 逻辑资源：18k LUTs
- 封装：LQFP144（可手工焊）
- 内部BSRAM：约828kbit（82kB）
- 无集成SDRAM，需要外挂
- 教程和社区支持较多，适合初学者
- 单价：约45~55元 （淘宝/立创商城无现货）

### 方案B：高云GW2AR-18 LQFP144
- 逻辑资源：18k LUTs
- 封装：LQFP144（可手工焊）
- 内部BSRAM：约828kbit（82kB）
- 集成PSRAM/SDRAM：64Mbit（8MB）
- 教程和社区支持相对较少
- 单价：约45~55元

### 方案C：高云GW2A-55 BGA
- 逻辑资源：55k LUTs（过剩）
- 封装：BGA（难以手工焊接，需要机器贴片）
- 集成资源丰富，但PCB需要4层以上精密走线
- 教程和社区支持较多，适合初学者
- 单价：约45~55元

### 方案D：Xilinx Artix-7 XC7A35T BGA
- 逻辑资源：33k LUTs（过剩）
- 封装：BGA（难以手工焊接）
- 集成资源丰富，但价格较高，且开发环境复杂
- 教程和社区支持最多，经典入门FPGA
- 单价：>170元

### 方案E：ZYNQ-7000系列 SoC
- 逻辑资源：28k逻辑单元（过剩）
- 封装：BGA（难以手工焊接）
- 集成ARM处理器，开发复杂度大，成本高
- 教程和社区支持较多，但主要面向嵌入式Linux开发
- 单价：约200元（仅Soc价格，实际还需考虑目前居高临下的存储器价格）（存在矿板，价格可能更低，但可靠性未知）
- **不适合当前项目需求，过于复杂且成本高昂，但未来可能适合更高级版本。**

## 决策
选择方案B：高云GW2AR-18 LQFP144

### 理由
1. LQFP144封装可直接用热风枪或刀头烙铁焊接，适合个人DIY，且PCB只需要4层即可布通。
2. 集成64Mbit SDRAM是决定性优势：
   - 无需外挂SDRAM芯片，节省PCB面积和布线复杂度。
   - 8MB存储空间足以存放海量任意波波形表（未来V3.0计划支持≥1Mpts）。
   - 内部SDRAM访问速度足以支撑125MSPS的波形读取（FPGA内置控制器）。
3. 逻辑资源18k LUTs足够实现DDS核心（约6k）、并口DAC接口（约2k）、SPI从机（约1k）、未来数字调制（约3k），剩余余量约30%，不紧张。
4. 成本仅比GW2A高约5元，但省去了外挂SDRAM和相关的布线成本，综合更优。
5. 高云开发环境对GW2AR支持成熟，且提供免费的SDRAM控制器IP（或可自己编写）。
6. 国产FPGA，供应链相对稳定且价格非常有竞争力。

## 后果
### 正面影响
- 简化PCB设计：只需一层FPGA供电（1.0V、3.3V），无需外挂内存走线。
- 未来扩展任意波无容量压力。
- 焊接和调试难度降低。
- 高云软件免费，便于开发调试。

### 负面影响
- 成本比纯GW2A方案高5~15元左右（可接受）。
- 集成SDRAM的型号引脚较少，die上部分资源用于SDRAM控制。
- 如果未来想切换到其他品牌FPGA，此集成SDRAM特性可能不通用。

### 替代方案放弃理由
**GW2A-18**：
1. 若不需任意波或只做小容量，它更便宜。但考虑V3.0计划需要大容量任意波，外挂SDRAM会额外增加PCB面积和调试时间，且高速SDRAM布线容易出信号完整性问题。得不偿失。
2. 淘宝/立创商城上没有GW2A-18 LQFP144现货。

**GW2A-55 BGA** ：
- 无法手工焊接，且资源严重过剩，价格高，不适合原型阶段。

**Xilinx Artix-7**：
1. 虽然资源充足，但价格高，且开发环境复杂，不适合当前项目需求。
2. BGA封装增加了焊接难度和PCB设计复杂度。
3. Xilinx的开发工具（Vivado）对个人DIY用户不太友好，且需要较高的学习成本。
  
**ZYNQ-7000 SoC**：
1. 过于复杂且成本高昂，开发难度大，不适合当前项目需求。
2. 虽然集成ARM处理器提供了强大的处理能力，但对于当前的DDS和波形生成需求来说是过度设计，且增加了开发复杂度和成本。
3. 未来可能适合更高级版本，但当前阶段不推荐。

## 相关文档
《技术规格书》第5.1节
《硬件架构文档》第3.2节
高云半导体GW2AR数据手册
高云半导体SDRAM控制器IP文档

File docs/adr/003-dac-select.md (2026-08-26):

<!------------------------------------------------------------------------
SPDX-License-Identifier: CC-BY-SA-4.0
Copyright (C) 2026 [EERNINUO]

This work is licensed under the Creative Commons Attribution-ShareAlike 4.0 International License. 
To view a copy of this license, visit http://creativecommons.org/licenses/by-sa/4.0/.
------------------------------------------------------------------------->

<!-- Assisted-by: DeepSeek - 文档框架 -->

# ADR-003: 主 DAC 选型 —— AD9747 vs AD9767

**状态**：已接受
**决策者**：EERNINUO
**日期**：2026-04-29

## 背景与问题
ArbWave30 需要一颗高速DAC实现最高 125MSPS 乃至更高采样率的波形输出。原方案采用 AD9767（14-bit, 125MSPS，双通道）。但在方案深化过程中发现两个问题：
1. 引脚布局：AD9767 的时钟输入位于两组并行数据引脚之间，导致PCB上高速时钟线与数据线交叉，增加布局难度和串扰风险。
2. 偏置产生：需要额外一颗16-bit DAC（DAC8562）来产生直流偏置电压（±2V范围），增加了BOM和PCB面积。

替代方案 AD9747（16-bit, 250MSPS，双通道）具有以下特点：

- 差分时钟输入引脚位于芯片侧面，与数据引脚分离，PCB布局更干净。
- 内置两个10-bit辅助DAC，可用于产生偏置电压，可能省去独立偏置DAC。
- 采用**数据时钟输出（DCO）**接口：DAC向FPGA输出一个同步时钟（DCO），FPGA用该时钟锁存数据。接口速率最高250MSPS。

但同时引入新挑战：
- 高云GW2AR FPGA 的IO翻转速率极限约 1.3ns（约 380MHz），理论上支持250MSPS，但DCO接口的建立/保持时间要求（400ps/1200ps）非常严苛。
- DCO在PCB上的传输延迟增加了FPGA时序约束难度。
- 辅助DAC分辨率只有10-bit，低于原选的16-bit专用DAC，可能影响偏置精度。
- 差分时钟输入需要AC耦合转换电路，不能直接连接标准LVDS时钟源（如CDCI6214），对布线提出了要求（如100Ω差分阻抗）

## 评估标准 （Evaluation Criteria）
| 标准 | 权重 | 说明 |
|---|---|---|
| PCB布局友好度	| 高 | 时钟与数据引脚是否交叉，是否容易做等长 |
| 信号完整性风险 | 高 |	时钟抖动、串扰、过孔换层需求 |
| 采购与成本| 中 | 样片价格和供货（项目用量小，成本不敏感） |
| 接口设计复杂度 | 中 | FPGA时序约束难度，是否需要额外逻辑 |
| 性能扩展潜力 | 低 | 是否支持更高采样率以备未来升级 |
| 集成度 / BOM简化 | 低 | 是否减少外部元件（如偏置DAC） |

## 评估分析 （Analysis）
### 1. PCB布局友好度
- AD9767：时钟引脚被 DB13P1\~DB0P1 和 DB13P2\~DB0P2 两组总线夹在中间。等长布线时，数据线必须从两侧绕开时钟线，或者时钟线必须打孔换层避开数据总线。这增加了布局难度和信号完整性风险。

- AD9747：时钟引脚位于器件侧面（第3、4脚），数据引脚集中在另两侧，自然分离。布局时可将时钟线直接引出，数据线独立走线，显著降低布线难度。

结论：AD9747明显占优。

### 2. 信号完整性风险
- AD9767：若采用时钟换层避开数据线，会遇到“参考平面切换”问题。四层板下处理不当会引入抖动和辐射。

- AD9747：差分时钟输入本身抗共模干扰能力强。虽需要交流耦合转换电路，但此电路简单、成熟（ADI官方评估板使用）。时钟线可直接从侧面引出，无需换层，保持完整参考平面。

结论：AD9747占优。

### 3. 采购与成本
两者均为ADI量产器件，均可通过正规渠道购买（立创商城）。AD9767价格适中（约 65\~70￥）AD9747价格略高（约 90\~100￥），但节省了外部偏置DAC（DAC8562，约30￥）。净成本增加约20￥，可忽略，且若使用AD9767，为解决时钟问题，可能需要升级到六层板，价格高于四层板。

结论：AD9747占优。

### 4. 接口设计复杂度
AD9767：标准并行接口，FPGA提供时钟和数据。时序简单，高云FPGA在125MHz下易满足。

AD9747：双端口模式需要FPGA接收DAC输出的DCO时钟，并使用该时钟锁存输出数据。建立/保持时间要求严苛（400ps/1200ps）。需要FPGA调整内部延迟。高云FPGA的IO延迟单元精度需要查证。

结论：AD9767占优（开发风险更低）。

### 5. 性能扩展潜力
AD9747最高支持250MSPS，而AD9767仅125MSPS。虽然当前项目只用125MSPS（或可升级到150\~200MSPS，动态性能更佳），但若未来升级任意波或提高正弦频，AD9747提供更大空间。

结论：AD9747占优。

### 6. 集成度 / BOM简化
AD9767：需要额外一个16-bit DAC（如DAC8562）来产生±2V偏置电压。增加BOM和PCB面积。

AD9747：内置两个10-bit辅助DAC。虽然 10-bit分辨率（约4.88mV步进）无法满足偏置±10V范围下分辨率≤2mV的要求吗？但是可以采用**辅助DAC粗调+主DAC微调**的方式。若要求更高，仍可保留外部偏置DAC，辅助DAC可另作他用（如控制衰减继电器）。

结论：AD9747占优（可省去独立偏置DAC）。

## 决策 （Decision）
**选择 AD9747 作为 ArbWave30 的主 DAC。**

尽管接口设计复杂度增加，但其在PCB布局、信号完整性、集成度方面的显著优势，以及对项目长期扩展性的支持，使其成为更优选择。接口复杂度可通过仔细的FPGA时序设计解决，且有官方参考设计可循。

## 实施计划 （Implementation Plan）
1. 时钟输入电路：按照AD9747数据手册Figure 29设计交流耦合电路：
- CDCI6214 LVDS差分输出 → 0.1µF电容 → AD9747 CLKP/CLKN
- 通过1kΩ和287Ω电阻从CVDD18分压产生~400mV共模电压
- 靠近AD9747引脚处跨接100Ω差分端接电阻

2. FPGA接口：
- 使用高云GW2AR的IO Bank中支持高速输出的引脚
- 采用双端口模式，采样率暂定125MSPS（若时序富裕可提升至150~200M）
- 接收DCO信号，并用PLL或IODELAY调整内部数据输出时钟相位，满足建立/保持时间

3. 辅助DAC使用：
- 辅助DAC1输出连接至偏置求和节点，产生±2V偏置
- 辅助DAC2留作备用（控制衰减继电器或未来扩展）
- 若偏置精度不足，保留外部DAC8562的焊盘作为可选件

3. PCB布局：
- 模拟板采用4层板（叠层：TOP - GND - PWR - BOT）
- 时钟差分走线100Ω阻抗，严格等长（误差≤5mil）
- CDCI6214放置靠近AD9747，交流耦合电路紧贴DAC时钟引脚

## 后果 （Consequences）
### 正面影响
- PCB局难度显著降低，信号完整性更有保障
- 省去外部偏置DAC，BOM简化，PCB面积减小
- 为未来提高采样率预留空间

### 负面影响
- FPGA时序设计复杂度增加，需要仔细约束和验证
- 需要增加5个被动元件（2电容+4电阻）用于时钟转换
- 若高云FPGA无法稳定工作在125MSPS以上，需降频或切换回AD9767

## 相关文档
《技术规格书》第5.1节
《硬件架构文档》第3.2节
高云半导体GW2AR数据手册
AD9767数据手册
AD9747数据手册

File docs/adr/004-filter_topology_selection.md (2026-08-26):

<!------------------------------------------------------------------------
SPDX-License-Identifier: CC-BY-SA-4.0
Copyright (C) 2026 [EERNINUO]

This work is licensed under the Creative Commons Attribution-ShareAlike 4.0 International License. 
To view a copy of this license, visit http://creativecommons.org/licenses/by-sa/4.0/.
------------------------------------------------------------------------->

<!-- Assisted-by: DeepSeek - 文档框架 -->

# ADR-004: 滤波器拓扑结构选型

## 状态
已采纳 （2026-05-09）

## 背景
AWG 输出 30MHz 正弦波、5MHz 方波。DAC 为 AD9747（150MSPS），需重构滤波器抑制采样镜像。

## 决策驱动因素
1. 通带插损（尤其 30MHz 处）需 < 0.5dB
2. 镜像频率（120MHz）抑制需 > 60dB
3. 方波过冲应尽量小（< 10% 为佳）
4. 电感需选用市售高 Q 值型号，避免 DCR 过大

## 备选方案与理由

**方案 A: 5 阶椭圆，35MHz 截止**
- ✅ 阻带抑制极佳（>100dB@120MHz）
- ❌ 所需电感值大（>300nH），Q 值低导致 30MHz 插损达 0.7dB
- ❌ 电感直流电阻高（>3Ω）

**方案 B: 7 阶椭圆，35MHz 截止**
- ✅ 阻带抑制极佳（>100dB@75MHz）
- ❌ 所需电感值大（>300nH），Q 值低导致 30MHz 插损达 0.45dB，但实际电感存在误差，可能达不到仿真参数
- ❌ 电感直流电阻高（>3Ω）

**方案 C: 7 阶椭圆，60MHz 截止（已选）**
- ✅ 电感值小（~120-180nH），可用高 Q 绕线电感（Q@60MHz>70）
- ✅ 30MHz 插损仿真<0.5dB（使用 Coilcraft 0805HP 模型）
- ✅ 120MHz 抑制>90dB（远超 60dB 需求）
- ⚠️ 方波过冲~13%（可接受，且可通过软件预失真或者调整上升沿速度进行抑制）
- ✅ 群延时变化相对平缓（因 5MHz 谐波远离截止区）

**方案 D: 7 阶椭圆，60MHz 截止，RC snubber**
- ✅ 电感值小（~120-180nH），可用高 Q 绕线电感（Q@60MHz>70）
- ✅ 方波过冲~8%
- ✅ 120MHz 抑制>90dB（远超 60dB 需求）
- ❌ 30MHz 插损仿真>1.2dB（RC snubber 过度吸收高频能量，导致通带损耗过大）
- ❌ 设计复杂度增加，需调整 RC 参数以平衡过冲和插损，且对元件参数敏感

**方案 E: 7 阶切比雪夫 II 型**
- ✅ 通带平坦，群延时特性更好
- ⚠️ 同阶数下阻带抑制较椭圆差
- ⚠️ 对元件参数敏感，实际电感 Q 值和误差可能导致性能大幅下降
- **决策**: 留作 V2.0 升级选项（可 Pin-to-Pin 替换）

## 决策
选择 **7阶椭圆滤波器，截止频率 60MHz**，将方波过冲列为已知问题，后续通过软件预失真、调整上升沿速度或采用单独方波通道进行优化。

## 理由
- 在实测可买的电感（如 AHW2012 系列）下，60MHz 处电感 Q 值可达 60+，30MHz 插损实测仿真 <1dB。
- 90dB@120MHz 抑制远超需求（65dB 已够用）。
- 方波过冲通过仿真确认约为 13%~18%，可接受（可通过软件预失真或者调整上升沿速度进行抑制）。
- 相比切比雪夫II，椭圆滤波器对元件参数和 PCB 布局要求相对较低，适合第一版。

## 后果
- 正面：电感可选型号丰富，通带损耗低，镜像抑制仍优秀。
- 负面影响：方波存在约 13%~18% 过冲，需要在后续设计中考虑优化方案。

## 相关链接
- [重构滤波器调试笔记]（/docs/设计笔记/重构滤波器调试笔记.md)

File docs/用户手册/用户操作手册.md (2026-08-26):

<!------------------------------------------------------------------------
SPDX-License-Identifier: CC-BY-SA-4.0
Copyright (C) 2026 [EERNINUO]

This work is licensed under the Creative Commons Attribution-ShareAlike 4.0 International License. 
To view a copy of this license, visit http://creativecommons.org/licenses/by-sa/4.0/.
------------------------------------------------------------------------->

<!-- Assisted-by: DeepSeek - 文档框架 -->

# ArbWave30 用户操作手册

| 文档编号 | ArbWave30-UM-001 | 版本 | V0.1 |
| --- | --- | --- | --- |
| 项目名称 | ArbWave30 | 日期 | 2026-08-17 |
| 编写人 | EERNINUO | 状态 | 占位文件 |

> 这里现在是占位文件，待系统验证完成后补充完整。

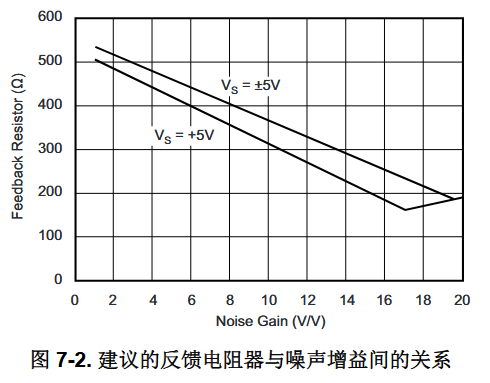
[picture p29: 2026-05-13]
docs/pic/OPA695反馈电阻-增益关系.png

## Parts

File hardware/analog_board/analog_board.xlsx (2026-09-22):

Reference | Qty | Value | Exclude from BOM | Exclude from Board | Footprint
C1,C2,C5,C8,C9,C11,C12,C13,C14,C15,C16,C17,C18,C19,C20,C21,C22,C23,C24,C25,C29,C32,C36,C40,C43,C46,C50,C53,C59,C89,C91,C92,C93,C94,C98,C99,C101,C102,C105,C106,C109,C111,C114,C117,C120,C147,C149,C153,C162,C163,C169,C171,C173,C174,C177 | 55 | 100nF |  |  | Capacitor_SMD:C_0603_1608Metric
C3,C6,C10,C97,C112,C115,C118 | 7 | 4.7uF |  |  | Capacitor_SMD:C_0603_1608Metric
C4,C7 | 2 | 10nF |  |  | Capacitor_SMD:C_0603_1608Metric
C26,C30,C33,C37,C41,C44,C47,C51,C54,C60 | 10 | 1nF |  |  | Capacitor_SMD:C_0603_1608Metric
C27,C31,C34,C39,C42,C45,C48,C52,C55,C62,C63,C66,C67,C79,C80,C83,C84 | 17 | 100pF |  |  | Capacitor_SMD:C_0603_1608Metric
C28,C35,C38,C49,C56,C96,C100,C103,C104,C107,C108,C175,C176 | 13 | 10uF |  |  | Capacitor_SMD:C_0603_1608Metric
C57,C58,C166 | 3 | 1uF |  |  | Capacitor_SMD:C_0603_1608Metric
C61,C65,C75,C76 | 4 | 56pF |  |  | Capacitor_SMD:C_0603_1608Metric
C64,C68,C87,C88 | 4 | 62pF |  |  | Capacitor_SMD:C_0603_1608Metric
C69,C72,C77,C78 | 4 | 6.8p |  |  | Capacitor_SMD:C_0603_1608Metric
C70,C73,C81,C82 | 4 | 9.1p |  |  | Capacitor_SMD:C_0603_1608Metric
C71,C74,C85,C86 | 4 | 2.0p |  |  | Capacitor_SMD:C_0603_1608Metric
C90,C95 | 2 | 100n |  |  | Capacitor_SMD:C_0603_1608Metric
C110,C113,C116,C119 | 4 | 470nF |  |  | Capacitor_SMD:C_0603_1608Metric
C145,C146 | 2 | 1uF |  |  | Capacitor_SMD:C_1206_3216Metric
C148 | 1 | 33nF |  |  | Capacitor_SMD:C_0603_1608Metric
C152 | 1 | 22uF |  |  | Capacitor_SMD:CP_Elec_5x5.4
C154,C155 | 2 | 22uF |  |  | Capacitor_SMD:C_1206_3216Metric
C160,C161,C164,C165,C167,C168,C170,C172 | 8 | 100uF |  |  | Capacitor_SMD:C_Elec_6.3x7.7
D1 | 1 | GREEN |  |  | LED_SMD:LED_0603_1608Metric
FB1 | 1 | 120R@100MHz |  |  | Inductor_SMD:L_0603_1608Metric
FB2,FB3,FB4,FB5,FB6,FB7,FB8,FB9,FB10,FB11,FB12,FB13,FB14,FB15,FB16,FB17 | 16 | 600R@100MHz |  |  | Inductor_SMD:L_0603_1608Metric
HS2,HS4 | 2 | Heatsink_Pad |  |  | Heatsink:TO-220_Heatsink
J1 | 1 | DC3 2.54mm Conn_02x05 |  |  | DC3 2.54mm Conn_02x05
J2 | 1 | DC3 2.54mm Conn_02x08 |  |  | DC3 2.54mm Conn_02x08
J3 | 1 | 2.54 Conn_01x04_Pin |  |  | Connector_PinHeader_2.54mm:PinHeader_1x04_P2.54mm_Vertical
J4 | 1 | Conn_01x08 |  |  | Connector_JST:JST_VH_B8P-VH_1x08_P3.96mm_Vertical
J5,J6,J7 | 3 | SMA |  |  | Connector_Coaxial:SMA_BAT_Wireless_BWSMA-KWE-Z001
L1,L4,L7,L8 | 4 | 160n |  |  | Inductor_SMD:L_0805_2012Metric
L2,L3,L5,L6,L9,L10,L11,L12 | 8 | 180n |  |  | Inductor_SMD:L_0805_2012Metric
L15 | 1 | 2.2uH |  |  | Inductor_SMD:L_Changjiang_FXL0420
Q1,Q2 | 2 | MMBT3906 |  |  | Package_TO_SOT_SMD:SOT-23
R1,R4,R5,R6 | 4 | 1kR |  |  | Resistor_SMD:R_0603_1608Metric
R2,R3,R7,R8,R9,R10 | 6 | 4.7kR |  |  | Resistor_SMD:R_0603_1608Metric
R11,R35 | 2 | 0R |  |  | Resistor_SMD:R_0603_1608Metric
R12 | 1 | 33R |  |  | Resistor_SMD:R_0603_1608Metric
R13,R14,R36,R37,R39,R40,R71 | 7 | 10kR |  |  | Resistor_SMD:R_0603_1608Metric
R15,R47,R48,R50,R52 | 5 | 100R |  |  | Resistor_SMD:R_0603_1608Metric
R16,R17,R22,R23,R26,R27,R76,R77 | 8 | 49.9R |  |  | Resistor_SMD:R_0603_1608Metric
R18 | 1 | 1.8kR |  |  | Resistor_SMD:R_0603_1608Metric
R19 | 1 | 510R |  |  | Resistor_SMD:R_0603_1608Metric
R20 | 1 | 0R |  |  | Resistor_SMD:R_0402_1005Metric
R21 | 1 | 100R |  |  | Resistor_SMD:R_0402_1005Metric
R24,R25 | 2 | 499R |  |  | Resistor_SMD:R_0603_1608Metric
R28 | 1 | 4.7k |  |  | Resistor_SMD:R_0402_1005Metric
R29,R41 | 2 | 53.6R |  |  | Resistor_SMD:R_0603_1608Metric
R31,R32,R43,R44 | 4 | 93.1R |  |  | Resistor_SMD:R_0603_1608Metric
R33,R34,R45,R46 | 4 | 560R |  |  | Resistor_SMD:R_0603_1608Metric
R49,R51 | 2 | 68R |  |  | Resistor_SMD:R_0603_1608Metric
R53 | 1 | 10kR |  |  | Capacitor_SMD:C_0603_1608Metric
R54,R55,R56,R57 | 4 | 4.7kR |  |  | Capacitor_SMD:C_0603_1608Metric
R58,R59,R60,R75 | 4 | 22R |  |  | Resistor_SMD:R_0402_1005Metric
R69 | 1 | 15k |  |  | Resistor_SMD:R_0603_1608Metric
R70 | 1 | 2.4kR |  |  | Resistor_SMD:R_0603_1608Metric
R72 | 1 | 12kR |  |  | Resistor_SMD:R_0603_1608Metric
R73 | 1 | 680R |  |  | Resistor_SMD:R_0603_1608Metric
R74 | 1 | 300R |  |  | Resistor_SMD:R_0603_1608Metric
RN1 | 1 | 33R |  |  | Resistor_SMD:R_Array_Concave_4x0603
RN2,RN3,RN4,RN5,RN6,RN7,RN8,RN9 | 8 | 33R |  |  | Resistor_SMD:R_Array_Concave_4x0402
U1 | 1 | GW2A-LV18EQ144 |  |  | ArbWave30_lib:LQFP-144_20x20_Pitch0.5mm
U2 | 1 | GD25Q32JVSS |  |  | Package_SO:SOIC-8_5.3x5.3mm_P1.27mm
U3 | 1 | AD9747BCPZ |  |  | Package_CSP:LFCSP-72-1EP_10x10mm_P0.5mm_EP5.3x5.3mm
U4,U5 | 2 | OPA695ID |  |  | Package_SO:SOIC-8_3.9x4.9mm_P1.27mm
U6 | 1 | NE5532 |  |  | Package_SO:SOIC-8_3.9x4.9mm_P1.27mm
U8 | 1 | CDCI6214RGER |  |  | Package_DFN_QFN:VQFN-24-1EP_4x4mm_P0.5mm_EP2.45x2.45mm
U11 | 1 | TPS62933 |  |  | Package_TO_SOT_SMD:SOT-583-8
U12 | 1 | L7805 |  |  | Package_TO_SOT_THT:TO-220-3_Vertical
U13 | 1 | L7905 |  |  | Package_TO_SOT_THT:TO-220-3_Vertical
U14 | 1 | TPS7A4701xRGW |  |  | Package_DFN_QFN:Texas_RGW0020A_VQFN-20-1EP_5x5mm_P0.65mm_EP3.15x3.15mm_ThermalVias
U15 | 1 | TPS7A91 |  |  | Package_DFN_QFN:Texas_S-PDSO-N10_EP1.2x2mm
U19 | 1 | AMS1117 |  |  | Package_TO_SOT_SMD:SOT-223-3_TabPin2
Y1 | 1 | 8132S-10.000NQ33DTL |  |  | Oscillator:Oscillator_SMD-4Pin_3.2x2.5mm

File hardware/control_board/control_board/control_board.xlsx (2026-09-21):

Reference | Qty | Value | Exclude from BOM | Exclude from Board | Footprint
BT1 | 1 | CR2032 |  |  | ArbWave30:BAT-TH_BS-05-A1BJ001
BZ1 | 1 | Buzzer |  |  | Buzzer_Beeper:MagneticBuzzer_StarMicronics_QMX
C1,C2 | 2 | 30p |  |  | Capacitor_SMD:C_0603_1608Metric
C3,C4 | 2 | 10p |  |  | Capacitor_SMD:C_0603_1608Metric
C5,C6,C9,C10,C11,C13,C14,C18,C20,C23,C27,C29,C36,C40,C43,C46,C50,C53,C60,C63,C65 | 21 | 100nF |  |  | Capacitor_SMD:C_0603_1608Metric
C7 | 1 | 4.7uF |  |  | Capacitor_SMD:C_0603_1608Metric
C8 | 1 | 10uF |  |  | Capacitor_SMD:C_0603_1608Metric
C12,C41,C51,C57,C59 | 5 | 1uF |  |  | Capacitor_SMD:C_0603_1608Metric
C15,C24,C37,C47 | 4 | 35V 22uF |  |  | Capacitor_SMD:CP_Elec_5x5.4
C16,C17,C25,C26,C38,C39,C48,C49,C61,C62 | 10 | 1uF |  |  | Capacitor_SMD:C_1206_3216Metric
C19,C28,C42,C52 | 4 | 100uF |  |  | Capacitor_SMD:C_Elec_6.3x7.7
C21,C22,C30,C31,C44,C45,C54,C55,C66,C67 | 10 | 22uF |  |  | Capacitor_SMD:C_1206_3216Metric
C32,C34,C58 | 3 | 330pF |  |  | Capacitor_SMD:C_0603_1608Metric
C33,C35,C68 | 3 | 33nF |  |  | Capacitor_SMD:C_0603_1608Metric
C56 | 1 | 820pF |  |  | Capacitor_SMD:C_0603_1608Metric
C64 | 1 | 22uF |  |  | Capacitor_SMD:CP_Elec_5x5.4
D1 | 1 | PRTR5V0U2X |  |  | Package_TO_SOT_SMD:SOT-143
D2 | 1 | LED |  |  | LED_SMD:LED_0603_1608Metric
D3,D9 | 2 | 1N4007 |  |  | Diode_SMD:D_SOD-123
D4 | 1 | SMBJ24A |  |  | Diode_SMD:D_SMB
D5,D6,D7,D8 | 4 | SS36 |  |  | Diode_SMD:D_SMA
J1 | 1 | USB_B |  |  | Connector_USB:USB_B_Lumberg_2411_02_Horizontal
J2 | 1 | Conn_02x08_Counter_Clockwise |  |  | Connector_IDC:IDC_IDC-Header_2x08_P2.54mm_Vertical_antiClockWise
J3 | 1 | Conn_01x06_Pin |  |  | Connector_PinHeader_2.54mm:PinHeader_1x06_P2.54mm_Vertical
J4 | 1 | Barrel_Jack_Switch |  |  | Connector_BarrelJack:BarrelJack_GCT_DCJ200-10-A_Horizontal
J5 | 1 | Conn_01x08 |  |  | Connector_JST:JST_VH_B8P-VH_1x08_P3.96mm_Vertical
J6 | 1 | Conn_01x02_Pin |  |  | Connector_JST:JST_VH_B2P-VH-B_1x02_P3.96mm_Vertical
L1,L2 | 2 | 68uH |  |  | Inductor_SMD:L_Changjiang_FXL1040
L3,L4 | 2 | 150uH |  |  | Inductor_SMD:L_12x12mm_H6mm
L5 | 1 | 4.7uH |  |  | Inductor_SMD:L_Changjiang_FXL0420
Q1 | 1 | SS8550 |  |  | Package_TO_SOT_SMD:SOT-23
Q2 | 1 | AO3401A |  |  | Package_TO_SOT_SMD:SOT-23
R1 | 1 | 39kR |  |  | Resistor_SMD:R_0603_1608Metric
R2 | 1 | 20kR |  |  | Resistor_SMD:R_0603_1608Metric
R3,R9,R10,R11,R30,R31 | 6 | 4.7kR |  |  | Resistor_SMD:R_0603_1608Metric
R4,R7,R8,R14,R18,R22,R26 | 7 | 10kR |  |  | Resistor_SMD:R_0603_1608Metric
R5,R6 | 2 | 22R |  |  | Resistor_SMD:R_0402_1005Metric
R12,R16 | 2 | 196kR |  |  | Resistor_SMD:R_0603_1608Metric
R13 | 1 | 75k |  |  | Resistor_SMD:R_0603_1608Metric
R15,R19 | 2 | 1.6kR |  |  | Resistor_SMD:R_0603_1608Metric
R17 | 1 | 200k |  |  | Resistor_SMD:R_0603_1608Metric
R20,R24 | 2 | 237kR |  |  | Resistor_SMD:R_0603_1608Metric
R21 | 1 | 75kR |  |  | Resistor_SMD:R_0603_1608Metric
R23 | 1 | 4.3kR |  |  | Resistor_SMD:R_0603_1608Metric
R25 | 1 | 200kR |  |  | Resistor_SMD:R_0603_1608Metric
R27 | 1 | 6.2kR |  |  | Resistor_SMD:R_0603_1608Metric
R28 | 1 | 47kR |  |  | Resistor_SMD:R_0603_1608Metric
R29 | 1 | 15kR |  |  | Resistor_SMD:R_0603_1608Metric
SW1 | 1 | BOOT0 |  |  | Button_Switch_SMD:SW_SPST_CK_RS282G05A3
SW2 | 1 | NRST |  |  | Button_Switch_SMD:SW_SPST_CK_RS282G05A3
U1 | 1 | STM32F411CEUx |  |  | Package_DFN_QFN:QFN-48-1EP_7x7mm_P0.5mm_EP5.6x5.6mm
U2 | 1 | M24C64 |  |  | Package_SO:SOIC-8_3.9x4.9mm_P1.27mm
U3,U4,U5,U6 | 4 | TPS54360DDA |  |  | Package_SO:TI_SO-PowerPAD-8_ThermalVias
U7 | 1 | TPS62933 |  |  | Package_TO_SOT_SMD:SOT-583-8
Y1 | 1 | 25MHz |  |  | Crystal:Crystal_SMD_3225-4Pin_3.2x2.5mm
Y2 | 1 | 32.768kHz |  |  | Crystal:Crystal_SMD_3215-2Pin_3.2x1.5mm

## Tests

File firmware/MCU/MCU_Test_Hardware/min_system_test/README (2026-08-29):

该程序为单片机最小系统测试
将此程序烧录进单片机后，Debug_LED 会以 1Hz 的频率闪烁

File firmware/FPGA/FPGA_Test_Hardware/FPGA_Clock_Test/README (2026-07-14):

该程序为FPGA时钟系统测试
将此程序烧录进FPGA后，J_SIG SPI_CS 输出 1Hz 方波信号，J_SIG SPI_CLK 输出 PLL 锁定情况（1 为锁定成功，0 为锁定失败），J_SIG SPI_MISO 输出 150MHz 时钟信号（若锁定成功）

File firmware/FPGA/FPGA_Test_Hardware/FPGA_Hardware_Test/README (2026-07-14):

该程序为FPGA最小系统测试
将此程序烧录进FPGA后，J_SIG SPI_CS 输出约 1Hz 的方波（由于FPGA内部晶振精确度一般，不一定是准确的 1Hz）

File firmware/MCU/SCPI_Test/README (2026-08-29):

这个工程用于测试 scpi-parser 的移植，上电后，插上 USB 线缆，通过串口工具连接到设备，发送命令即可。

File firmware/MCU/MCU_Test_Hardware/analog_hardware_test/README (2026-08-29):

这是模拟链路测试程序
将程序烧录进控制板后，重新上电，当 FPGA 程序加载完成后，等待 1s，开始输出 1MHz 正弦波；再过 1s 后，输出 10MHz 正弦波

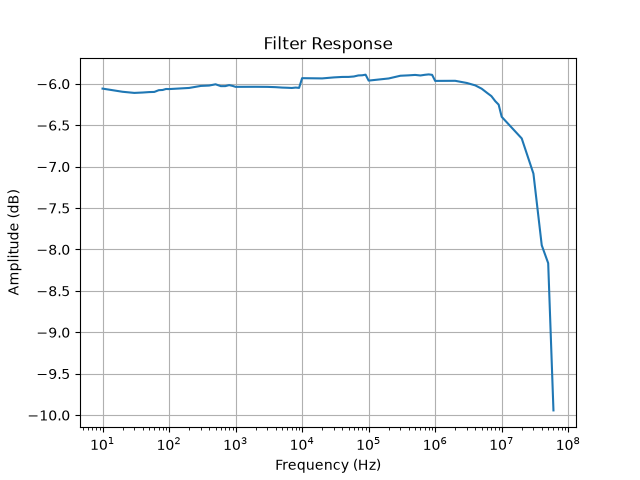
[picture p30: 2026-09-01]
scripts/test_filter/同相端滤波器.png

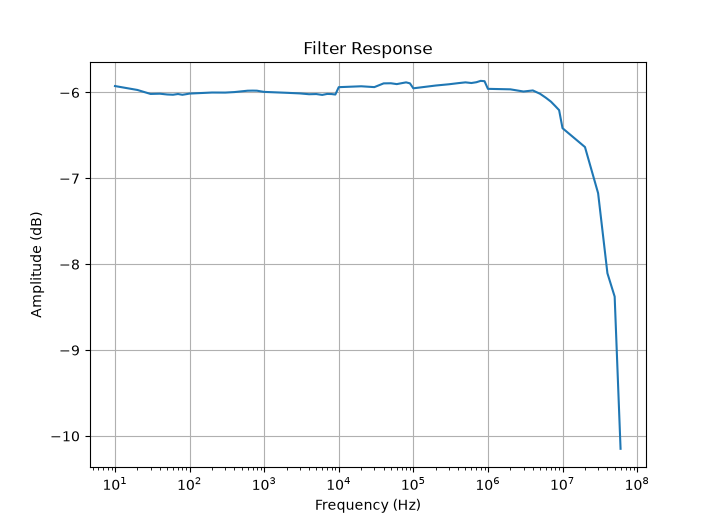
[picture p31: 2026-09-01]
scripts/test_filter/反相端滤波器.png

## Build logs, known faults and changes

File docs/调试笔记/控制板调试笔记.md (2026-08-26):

<!------------------------------------------------------------------------
SPDX-License-Identifier: CC-BY-SA-4.0
Copyright (C) 2026 [EERNINUO]

This work is licensed under the Creative Commons Attribution-ShareAlike 4.0 International License. 
To view a copy of this license, visit http://creativecommons.org/licenses/by-sa/4.0/.
------------------------------------------------------------------------->

# ArbWave30 - 控制板调试笔记

## DC-DC 输出电压测试
**日期**：2026-6-23
**硬件版本**：v0.1
**测试目的**：验证控制板 DC-DC 输出电压是否正常
**测试仪器**：ZT-219 数字万用表，RK6006 数控电源
**测试步骤**：
    1. 使用 ZT-219 二极管档测量电源输入正端对地压降，
    2. RK6006 输出 24V 电源接入控制板，于电源测试点（+17V，-17V，+7V，-7V，+3.3V）处测量电压
**测试数据**：

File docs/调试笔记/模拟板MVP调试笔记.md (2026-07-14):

<!------------------------------------------------------------------------
SPDX-License-Identifier: CC-BY-SA-4.0
Copyright (C) 2026 [EERNINUO]

This work is licensed under the Creative Commons Attribution-ShareAlike 4.0 International License. 
To view a copy of this license, visit http://creativecommons.org/licenses/by-sa/4.0/.
------------------------------------------------------------------------->

<!-- Assisted-by: DeepSeek - 文档框架 -->

# ArbWave30 - 模拟板MVP调试笔记

## 外观检查
- **日期**：2026年6月13日
- **硬件版本**：v0.1.0-mvp
- **测试目的**：检查是否存在 PCB 工艺缺陷；检查封装与实物是否匹配
- **测试工具**：
    1. 数码显微镜
    2. 焊接所需物料
- **检查清单**：
  
| 序号 | 检查内容 | 检查结果 | 备注 |
| ---- | ---- | ---- | ---- |
| 1 | 检查封装与实物是否匹配 | ⚠️ 注意 | 散热片封装错误（详见“异常项描述”）|
| 2 | 检查阻焊颜色均匀性 | ⚠️ 注意 | 部分细走线颜色发黄（详见“异常项描述”） |
| 3 | 检查走线有无断线 | ✅通过 | 走线正常连通 |
| 4 | 丝印清晰度与位置 | ⚠️ 注意 | 部分丝印可选添加（详见“异常项描述”） |

- **异常项描述**
1. **阻焊层局部发黄（细走线区域）**
**[现象]** 在数码显微镜下，发现以下异常：
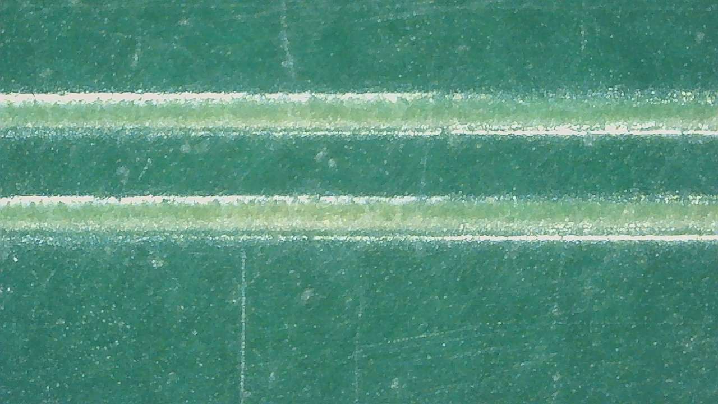
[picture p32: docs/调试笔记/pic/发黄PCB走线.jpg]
发黄PCB走线

   - 时钟差分线（CLK_P/N，线宽6mil）表面的阻焊层呈淡黄色，与周围正常的绿色阻焊形成肉眼可辨的色差（如上图）。
   - 同样现象出现在另外三条线宽≤6mil的孤立走线上，而走线密集（比如 FPGA-DAC 接口处）及铜皮处阻焊正常（如下图）。

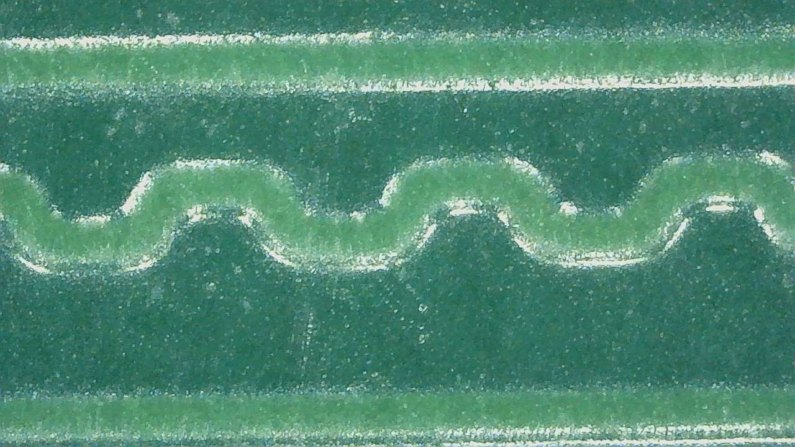
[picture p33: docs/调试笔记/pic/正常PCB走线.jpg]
    
   - 酒精擦拭不变色，排除表面污染。

    **[分析与推测]**
   - 初步判断：黄色并非阻焊变质，而是底层铜色透过半透明阻焊层显色。细走线在电镀时因电流密度集中导致局部铜厚增加，表面高度抬升使覆盖的阻焊油墨实际厚度变薄，最终透出铜色。
   - 功能风险：当前不影响电气导通，但降低了该区域的机械防护和绝缘强度，后续组装或长期使用中更易划伤或受潮腐蚀。
   - 信号完整性风险：铜厚偏差会略微改变差分阻抗，对150MHz时钟的反射裕量影响有限，但在后续实测中需特别关注。

    **[行动计划]**
   - 电气验证：用万用表测量相邻细走线间绝缘电阻（>20MΩ，通过）。
   - 在后续测试中，若发现信号质量异常，将优先排查此项。
   - 若无异常，则可忽略此项，但需在组装时特别注意保护这些区域。

2. **散热片封装错误**
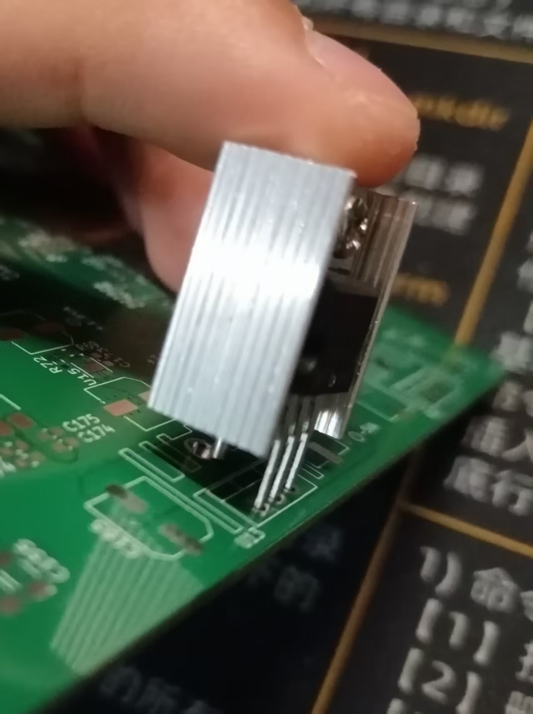
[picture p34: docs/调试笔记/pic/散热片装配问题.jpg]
散热片装配

**[现象]** 发现散热片封装与实际实物不符（见上图）。
   - 散热片偏薄，导致装配冲突。

    **[行动计划]**
    - 可通过掰弯稳压器引脚来解决装配冲突问题。
    - 修改封装文件，确保散热片厚度符合实际尺寸。
    - 后级电源功耗不大，MVP 中保留散热片是为了保险起见，后续可根据实测情况酌情移除散热片。

3. **丝印可选添加**
**[现象]** JTAG 调试接口处无丝印标明引脚顺序，若需要用杜邦线连接需查看 Layout 文件。

    **[行动计划]**
    - 在丝印层添加引脚顺序标识，便于调试。

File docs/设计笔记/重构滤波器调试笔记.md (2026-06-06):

<!------------------------------------------------------------------------
SPDX-License-Identifier: CC-BY-SA-4.0
Copyright (C) 2026 [EERNINUO]

This work is licensed under the Creative Commons Attribution-ShareAlike 4.0 International License. 
To view a copy of this license, visit http://creativecommons.org/licenses/by-sa/4.0/.
------------------------------------------------------------------------->

# 重构滤波器调试笔记

## 2026-05-08
- 目标：为 AD9747 (150MSPS) 设计重构滤波器，通带 0\~30MHz，抑制 120MHz 镜像 >60dB。
- 初始尝试：5 阶椭圆，截止 35MHz，用理想电感仿真，通带平坦，阻带抑制 120dB@120MHz。
- 问题：换上真实电感模型（AWH1608C, Q≈25，DCR≈2\~3 Ω）后，30MHz 插损达 0.7dB，不符合通带要求。
- 原因：电感 Q 值太低，且 DCR 过高。
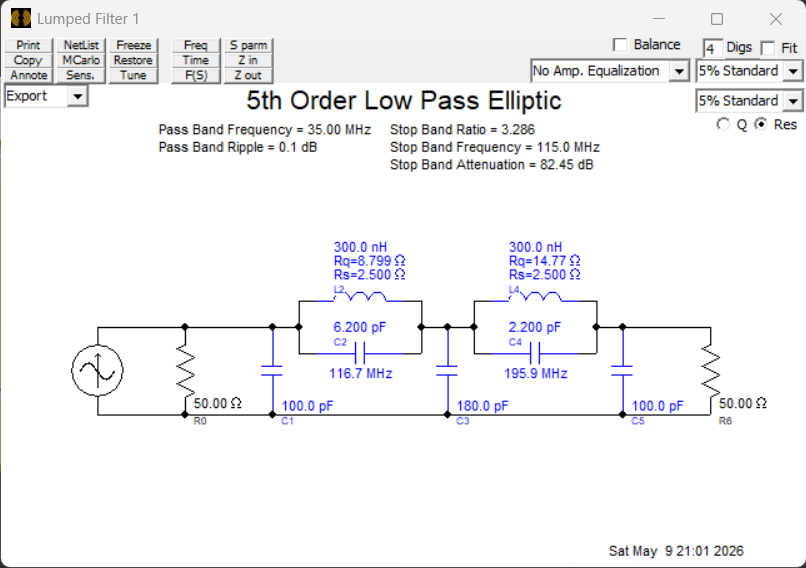
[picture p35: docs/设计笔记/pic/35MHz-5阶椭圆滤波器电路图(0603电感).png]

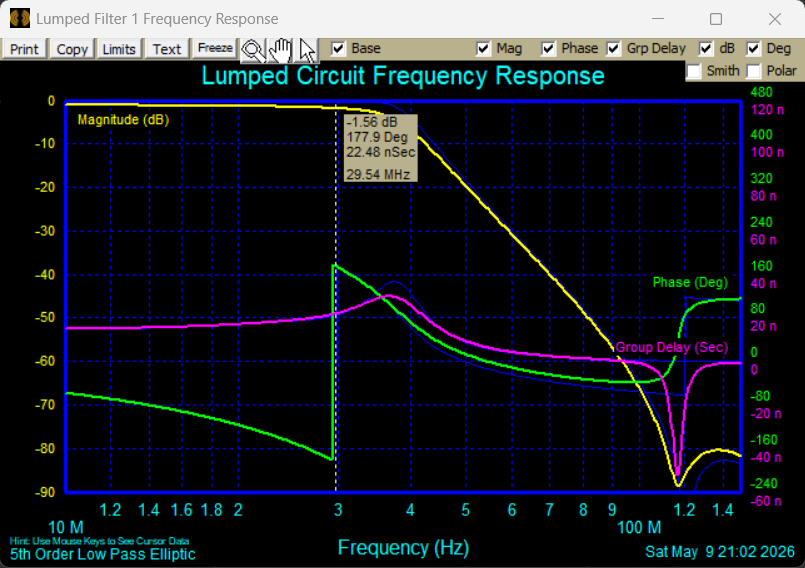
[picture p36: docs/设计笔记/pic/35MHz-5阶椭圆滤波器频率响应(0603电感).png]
频率响应


## 2026-05-08
- 将电感更换为 AHW2012
- 发现插入损耗约为 0.45dB@30MHz，处于临界值，但实际元器件性能可能不理想，风险较大。

## 2026-05-08
- 尝试提高截止频率至 60MHz。
- 发现 60MHz 下电感量减小（约 120\180nH），对应 DCR 较小（约 0.4\~0.7Ω），插损降至 0.2dB@30MHz。
- 但 120MHz 镜像抑制降至 35dB，不满足要求。
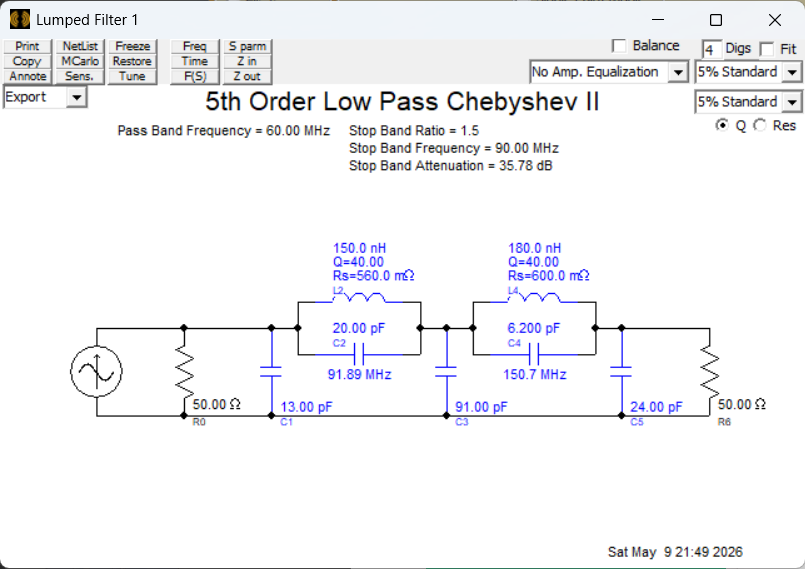
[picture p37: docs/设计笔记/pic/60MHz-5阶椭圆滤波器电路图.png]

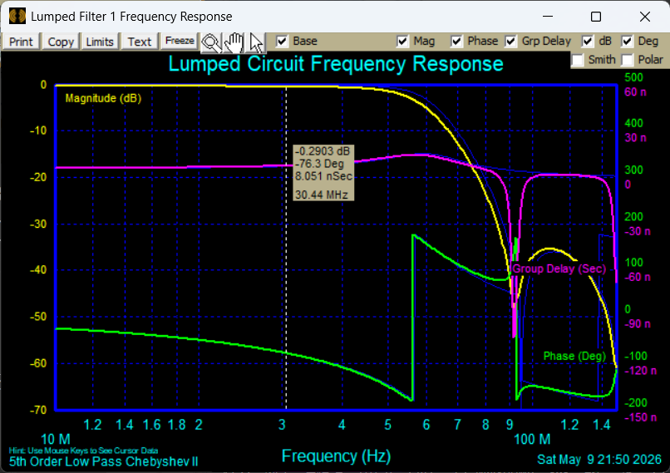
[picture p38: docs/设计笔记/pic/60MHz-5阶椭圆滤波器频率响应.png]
频率响应


## 2026-05-09 （当前最佳方案）
- 更换滤波器为 7 阶椭圆，截止 60MHz
- 插损约 0.2dB@30MHz，75MHz 抑制约 20dB，满足要求。
- 但 7 阶椭圆方波响应有 13% 过冲（5MHz 方波，LTSpice 仿真约 18%）。问题根源是椭圆滤波器的群延时尖峰。
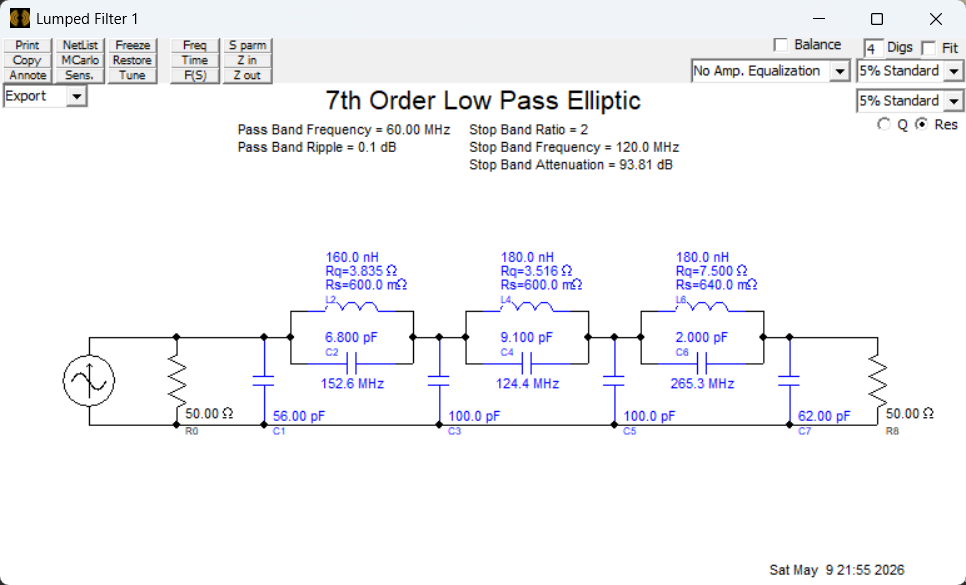
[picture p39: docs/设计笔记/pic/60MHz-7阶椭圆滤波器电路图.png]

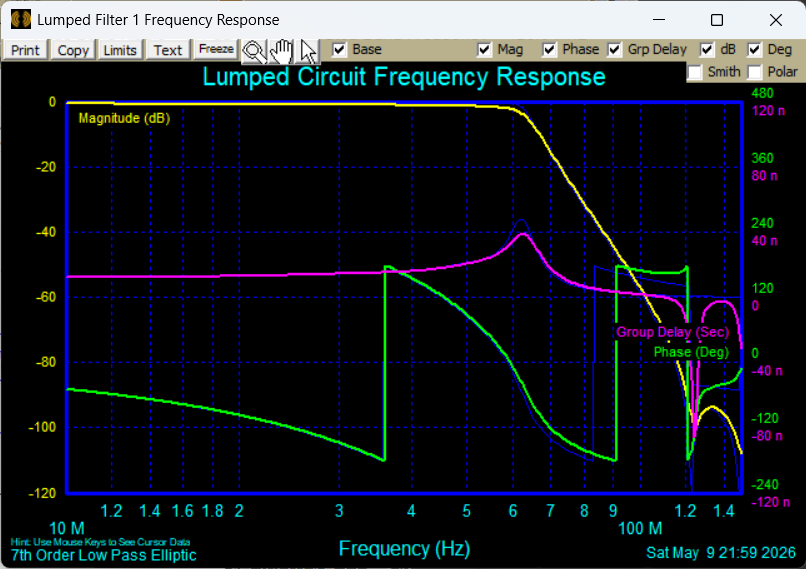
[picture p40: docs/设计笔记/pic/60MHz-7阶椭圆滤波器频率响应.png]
频率响应

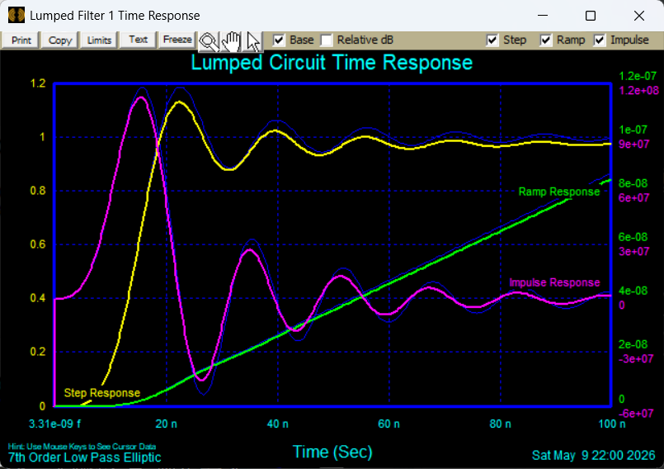
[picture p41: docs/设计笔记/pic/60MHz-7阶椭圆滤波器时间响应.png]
时间响应


## 2026-05-19
- 输出端加 RC snubber（R=47Ω, C=68pF）后，过冲降至约 8%
- 但 30MHz 插损增加到约 1.2dB，不满足要求。
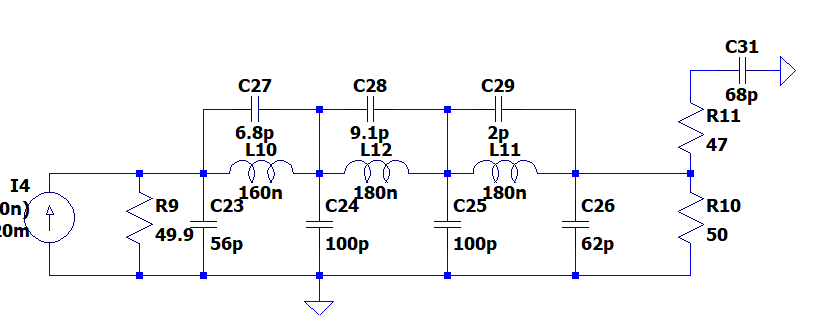
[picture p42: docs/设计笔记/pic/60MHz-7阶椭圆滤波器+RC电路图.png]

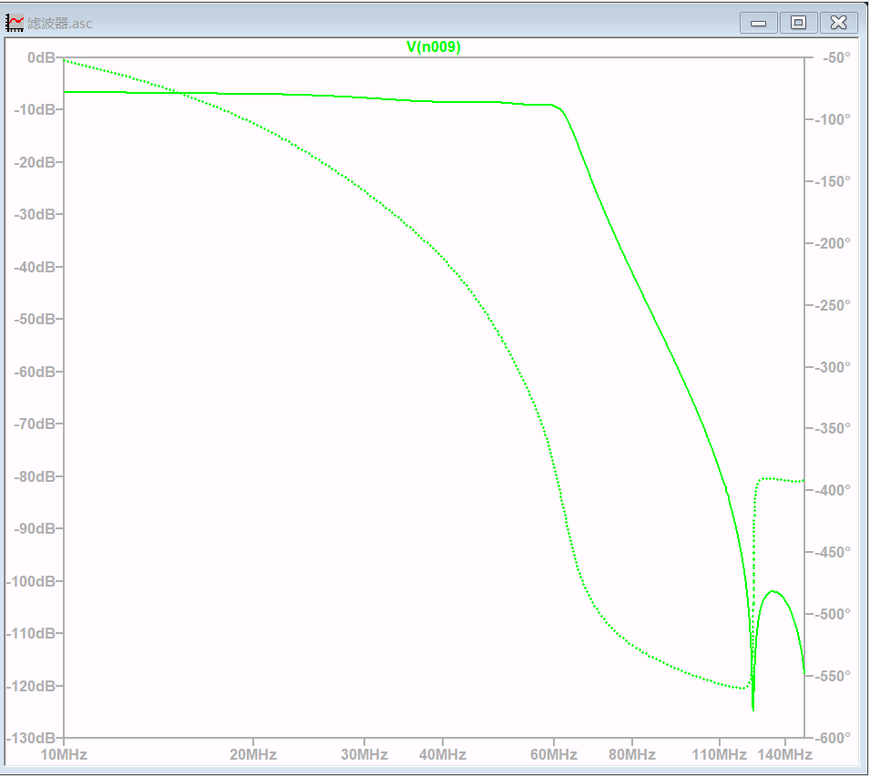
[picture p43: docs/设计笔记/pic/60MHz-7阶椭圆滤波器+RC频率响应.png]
频率响应

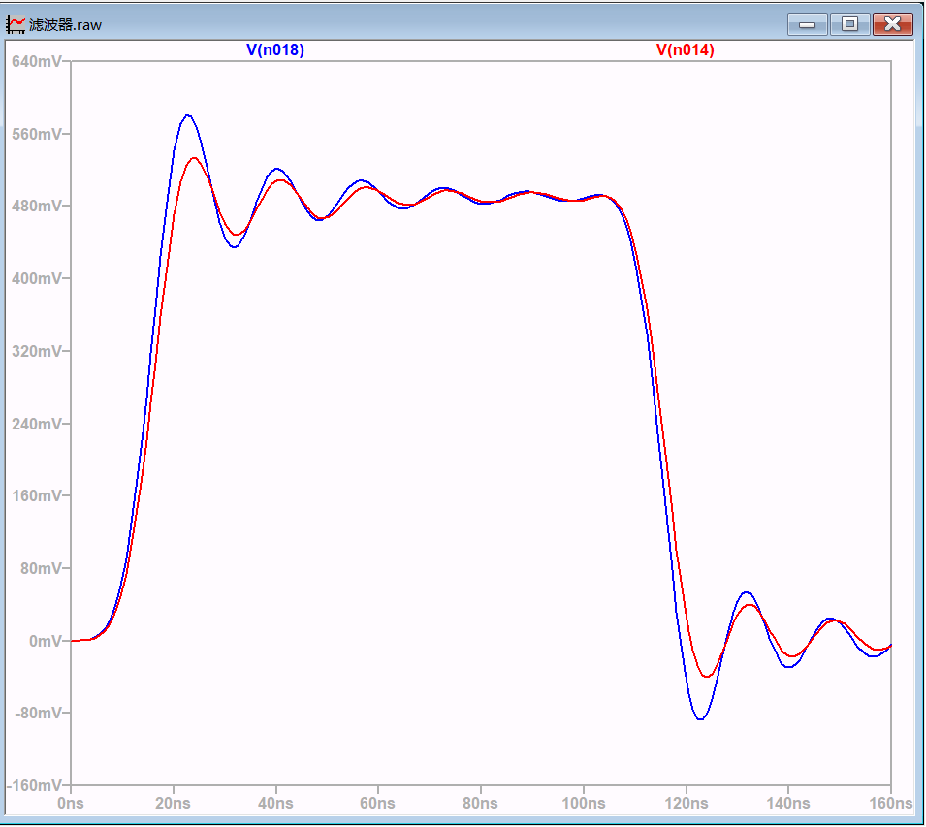
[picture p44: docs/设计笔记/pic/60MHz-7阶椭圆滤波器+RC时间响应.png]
时间响应


## 未来探索
- 使用单独通道产生方波，不经过重构滤波器（v2.0 实现）
- 通过软件调整上升沿时间，降低高频成分
- 通过软件预失真补偿滤波器的非理想响应

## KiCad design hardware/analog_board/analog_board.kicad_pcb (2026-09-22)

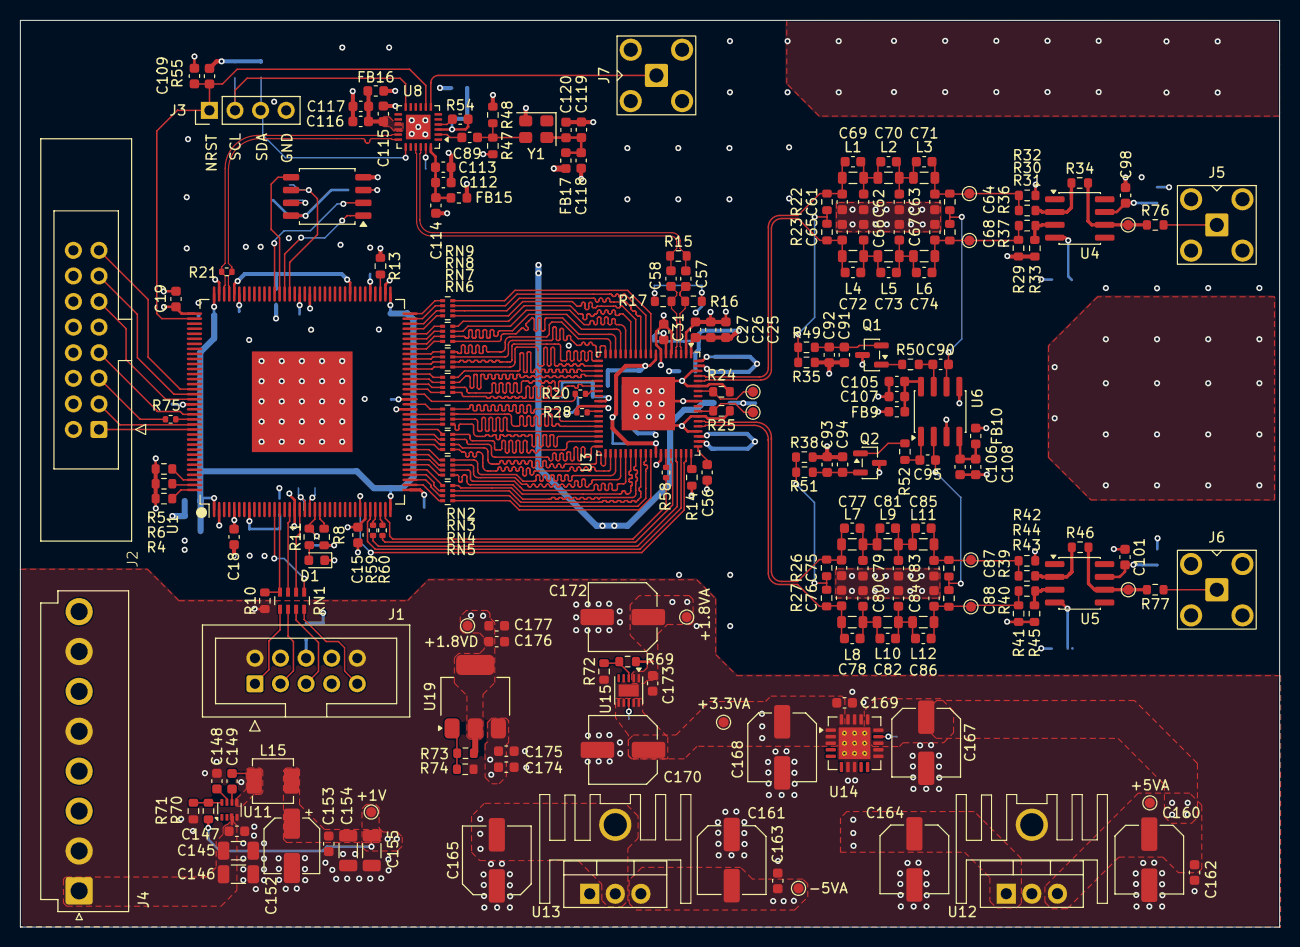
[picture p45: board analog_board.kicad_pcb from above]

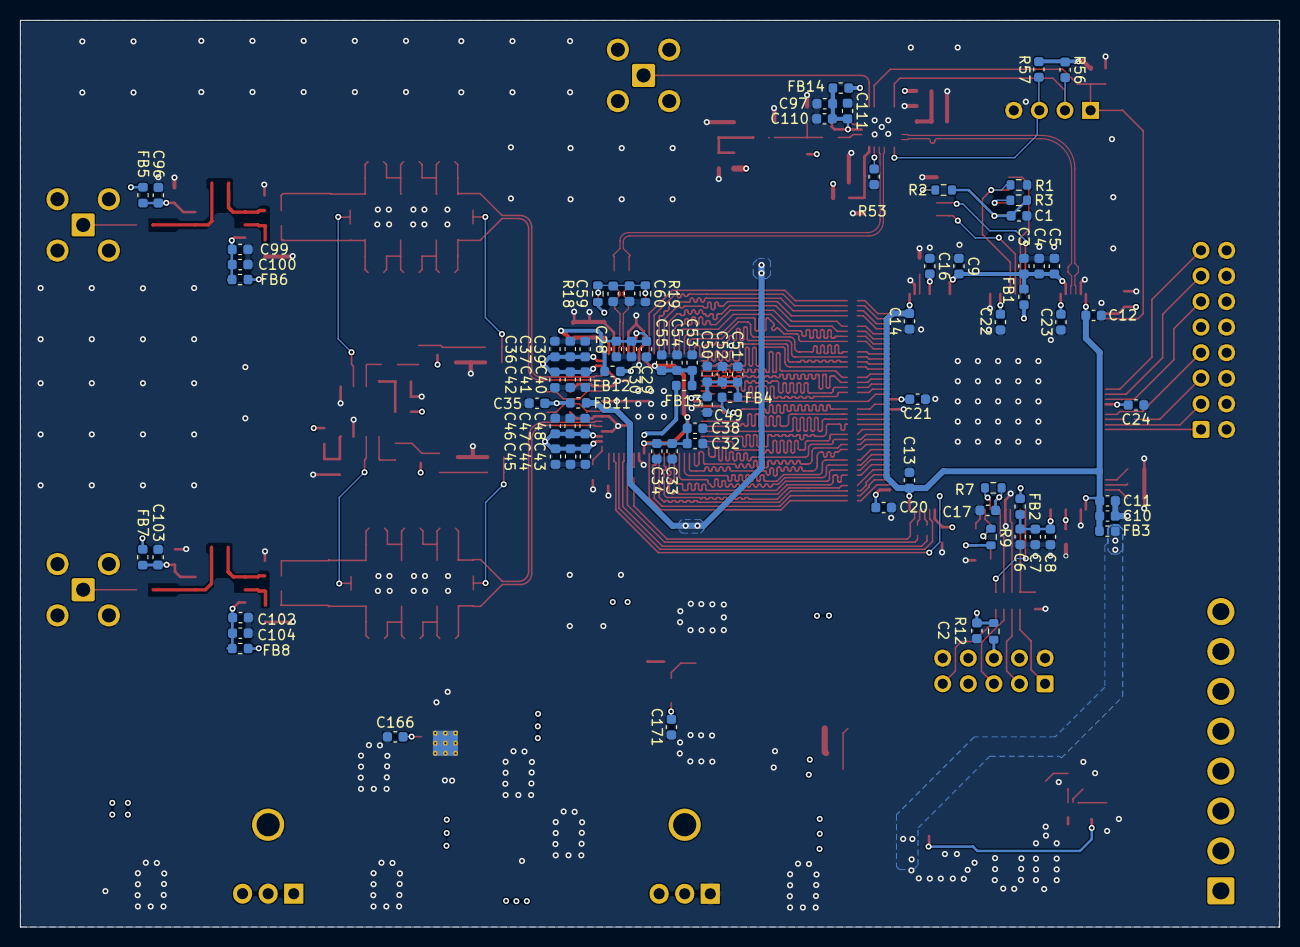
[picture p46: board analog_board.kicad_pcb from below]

Board: 4 copper layers, 125.0 x 90.0 mm, 295 parts (84 on the bottom side), 195 nets.

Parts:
C1, C2, C5, C8, C9, C11, C12, C13, C14, C15, C16, C17, C18, C19, C20, C21, C22, C23, C24, C25, C29, C32, C36, C40, C43, C46, C50, C53, C59, C89, C91, C92, C93, C94, C98, C99, C101, C102, C105, C106, C109, C111, C114, C117, C120, C147, C149, C153, C162, C163, C169, C171, C173, C174, C177: 100nF; C_0603_1608Metric
C3, C6, C10, C97, C112, C115, C118: 4.7uF; C_0603_1608Metric
C4, C7: 10nF; C_0603_1608Metric
C26, C30, C33, C37, C41, C44, C47, C51, C54, C60: 1nF; C_0603_1608Metric
C27, C31, C34, C39, C42, C45, C48, C52, C55, C62, C63, C66, C67, C79, C80, C83, C84: 100pF; C_0603_1608Metric
C28, C35, C38, C49, C56, C96, C100, C103, C104, C107, C108, C175, C176: 10uF; C_0603_1608Metric
C57, C58, C166: 1uF; C_0603_1608Metric
C61, C65, C75, C76: 56pF; C_0603_1608Metric
C64, C68, C87, C88: 62pF; C_0603_1608Metric
C69, C72, C77, C78: 6.8p; C_0603_1608Metric
C70, C73, C81, C82: 9.1p; C_0603_1608Metric
C71, C74, C85, C86: 2.0p; C_0603_1608Metric
C90, C95: 100n; C_0603_1608Metric
C110, C113, C116, C119: 470nF; C_0603_1608Metric
C145, C146: 1uF; C_1206_3216Metric
C148: 33nF; C_0603_1608Metric
C152: 22uF; CP_Elec_5x5.4
C154, C155: 22uF; C_1206_3216Metric
C160, C161, C164, C165, C167, C168, C170, C172: 100uF; C_Elec_6.3x7.7
D1: GREEN; LED_0603_1608Metric
FB1: 120R@100MHz; L_0603_1608Metric
FB2, FB3, FB4, FB5, FB6, FB7, FB8, FB9, FB10, FB11, FB12, FB13, FB14, FB15, FB16, FB17: 600R@100MHz; L_0603_1608Metric
HS2, HS4: Heatsink_Pad; TO-220_Heatsink
J1: 2x5 牛角座; IDC-Header_2x05_P2.54mm_Vertical_antiClockWise
J2: Conn_02x08_Counter_Clockwise; IDC_IDC-Header_2x08_P2.54mm_Vertical_antiClockWise
J3: Conn_01x04_Pin; PinHeader_1x04_P2.54mm_Vertical
J4: Conn_01x08; JST_VH_B8P-VH_1x08_P3.96mm_Vertical
J5, J6, J7: CH1; SMA_BAT_Wireless_BWSMA-KWE-Z001
L1, L4, L7, L8: 160n; L_0805_2012Metric
L2, L3, L5, L6, L9, L10, L11, L12: 180n; L_0805_2012Metric
L15: 2.2uH; L_Changjiang_FXL0420
Q1, Q2: MMBT3906; SOT-23
R1, R4, R5, R6: 1kR; R_0603_1608Metric
R2, R3, R7, R8, R9, R10: 4.7kR; R_0603_1608Metric
R11, R35, R38: 0R; R_0603_1608Metric
R12: 33R; R_0603_1608Metric
R13, R14, R36, R37, R39, R40, R71: 10kR; R_0603_1608Metric
R15, R47, R48, R50, R52: 100R; R_0603_1608Metric
R16, R17, R22, R23, R26, R27, R76, R77: 49.9R; R_0603_1608Metric
R18: 1.8kR; R_0603_1608Metric
R19: 510R; R_0603_1608Metric
R20: 0R; R_0402_1005Metric
R21: 100R; R_0402_1005Metric
R24, R25: 499R; R_0603_1608Metric
R28: 4.7k; R_0402_1005Metric
R29, R41: 53.6R; R_0603_1608Metric
R30, R42: 226R; R_0603_1608Metric
R31, R32, R43, R44: 73.2R; R_0603_1608Metric
R33, R34, R45, R46: 442R; R_0603_1608Metric
R49, R51: 68R; R_0603_1608Metric
R53: 10kR; C_0603_1608Metric
R54, R55, R56, R57: 4.7kR; C_0603_1608Metric
R58, R59, R60, R75: 22R; R_0402_1005Metric
R69: 15k; R_0603_1608Metric
R70: 2.4kR; R_0603_1608Metric
R72: 12kR; R_0603_1608Metric
R73: 68kR; R_0603_1608Metric
R74: 7.5kR; R_0603_1608Metric
RN1: 33R; R_Array_Concave_4x0603
RN2, RN3, RN4, RN5, RN6, RN7, RN8, RN9: 33R; R_Array_Concave_4x0402
TP1: CH1_O; TestPoint_Pad_D1.0mm
TP2: CH2_O; TestPoint_Pad_D1.0mm
TP3: CH2_F+; TestPoint_Pad_D1.0mm
TP4: CH2_F-; TestPoint_Pad_D1.0mm
TP5: CH1_F+; TestPoint_Pad_D1.0mm
TP6: CH1_F-; TestPoint_Pad_D1.0mm
TP7: offset1; TestPoint_Pad_D1.0mm
TP8: offset2; TestPoint_Pad_D1.0mm
TP11: +1V; TestPoint_Pad_D1.0mm
TP14: -5VA; TestPoint_Pad_D1.0mm
TP15: +5VA; TestPoint_Pad_D1.0mm
TP16: +3.3VA; TestPoint_Pad_D1.0mm
TP17: +1.8VA; TestPoint_Pad_D1.0mm
TP18: +1.8VD; TestPoint_Pad_D1.0mm
U1: GW2A-LV18EQ144; LQFP-144_20x20_Pitch0.5mm
U2: GD25Q32JVSS; SOIC-8_5.3x5.3mm_P1.27mm
U3: AD9747BCPZ; LFCSP-72-1EP_10x10mm_P0.5mm_EP5.3x5.3mm
U4, U5: OPA695ID; SOIC-8_3.9x4.9mm_P1.27mm
U6: NE5532; SOIC-8_3.9x4.9mm_P1.27mm
U8: CDCI6214RGER; VQFN-24-1EP_4x4mm_P0.5mm_EP2.45x2.45mm
U11: TPS62933; SOT-583-8
U12: L7805; TO-220-3_Vertical
U13: L7905; TO-220-3_Vertical
U14: TPS7A4701xRGW; Texas_RGW0020A_VQFN-20-1EP_5x5mm_P0.65mm_EP3.15x3.15mm_Ther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
U15: TPS7A91; Texas_S-PDSO-N10_EP1.2x2mm
U19: AMS1117; SOT-223-3_TabPin2
Y1: ASE-10MHz; Oscillator_SMD_Abracon_ASE-4Pin_3.2x2.5mm

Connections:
+1.8VA: C172.1, C173.2, FB12.1, R18.2, R69.2, TP17.1 (1_1), U15.1 (OUT), U15.2 (OUT)
+1.8VA_DAC: C25.2, C26.2, C27.2, C28.2, C29.2, C30.2, C31.2, FB12.2, U3.1 (CVDD18), U3.6 (CVDD18)
+1.8VD: C176.2, C177.2, FB13.1, R73.2, TP18.1 (1_1), U19.2 (VO)
+1.8VD_DAC: C32.2, C33.2, C34.2, C38.2, C53.2, C54.2, C55.2, FB13.2, U3.8 (DVDD18), U3.47 (DVDD18)
+1V0: C152.1, C153.2, C154.2, C155.2, FB1.1, FB2.1, FB3.1, L15.2, R70.2, TP11.1 (1_1)
+3.3V: C1.1, C2.2, C15.2, C16.2, C17.2, C18.2, C19.2, C20.2, C21.2, C22.2, C23.2, C24.2, C174.2, C175.2, FB4.1, J4.8, R2.1, R3.1, R7.2, R8.2, R9.2, R12.2, U1.5 (VCCX/VCC_IO2/VCC_IO6/VCC_IO7), U1.19 (VCCX/VCC_IO2/VCC_IO6/VCC_IO7), U1.31 (VCCX/VCC_IO2/VCC_IO6/VCC_IO7), U1.37 (VCC_IO5), U1.55 (VCC_IO4), U1.77 (VCC_IO3), U1.91 (VCC_IO3), U1.103 (VCCX/VCC_IO2/VCC_IO6/VCC_IO7), U1.109 (VCC_IO1), U1.127 (VCC_IO0), U2.8 (VCC), U19.3 (VI)
+3.3VA: C168.1, C169.2, C170.1, FB11.1, FB14.1, FB15.1, FB16.1, FB17.1, TP16.1 (1_1), U14.1 (OUT), U14.2 (NC), U14.3 (SENSE/FB), U14.20 (OUT), U15.6 (SS_CTRL), U15.7 (EN), U15.9 (IN), U15.10 (IN)
+3.3VA_DAC: C35.2, C36.2, C37.2, C39.2, C40.2, C41.2, C42.2, C43.2, C44.2, C45.2, C46.2, C47.2, C48.2, FB11.2, U3.56 (AVDD33), U3.57 (AVDD33), U3.71 (AVDD33), U3.72 (AVDD33)
+3.3VD_DAC: C49.2, C50.2, C51.2, C52.2, FB4.2, U3.27 (DVDD33)
+5VA: C160.1, C162.2, C167.1, FB5.1, FB7.1, FB9.1, TP15.1 (1_1), U12.3 (OUT), U14.13 (EN), U14.15 (IN), U14.16 (IN)
+7V: C164.1, J4.4, U12.1 (IN)
+17V: C145.2, C146.2, C147.2, J4.1, U11.3 (VIN)
-5VA: C161.2, C163.1, FB6.1, FB8.1, FB10.1, Q1.3 (C), Q2.3 (C), TP14.1 (1_1), U13.3 (VO)
-7V: C165.2, HS4.1, J4.6, U13.2 (VI)
/Clock/10MHz_OUT: J7.1 (In), U8.7 (OUT0)
/Clock/CLK_{IN}: C89.2, R47.1, R48.2, Y1.3 (OUT)
/Clock/DAC_CLK+: C57.2, R15.2, U8.22 (OUT1_P)
/Clock/DAC_CLK-: C58.2, R15.1, U8.21 (OUT1_N)
/Clock/FPGA_CLK+: R21.1, U1.105 (IOR7B/RPLL1_C_in), U8.18 (OUT2_P)
/Clock/FPGA_CLK-: R21.2, U1.106 (IOR7A/RPLL1_T_in), U8.17 (OUT2_N)
/Clock/RESET_N: C109.1, J3.1, R55.1, U1.110 (IOT50B), U8.8 (RESETN/SYNC)
/Clock/SCL: J3.2, R56.2, U8.12 (SCL/GPIO3)
/Clock/SDA: J3.3, R57.2, U8.19 (SDA/GPIO2)
/Clock/XIN: C89.1, U8.2 (XIN/FB_N)
/DAC/CLK+: C57.1, R16.2, U3.3 (CLKP)
/DAC/CLK-: C58.1, R17.1, U3.4 (CLKN)
/DAC/DAC_SPI.DAC_RESET: U1.30 (IOL36B), U3.53 (RESET)
/DAC/DAC_SPI.DAC_SPI_CLK: R59.1, U3.51 (SCLK)
/DAC/DAC_SPI.DAC_SPI_CS: U1.32 (IOL42A), U3.52 (CSB)
/DAC/DAC_SPI.DAC_SPI_MISO: R58.1, U1.35 (IOL45B/LPLL2_C_in)
/DAC/DAC_SPI.DAC_SPI_MOSI: R60.1, U3.50 (SDIO)
/DAC/DCO: R20.2, U1.56 (IOB30A/GCLKT_4)
/DAC/FSADJ: R14.2, U3.54 (FSADJ)
/DAC/IOUT1_N: C65.1, C72.2, L4.1, R23.1, U3.68 (IOUT1N)
/DAC/IOUT1_P: C61.2, C69.2, L1.1, R22.2, U3.69 (IOUT1P)
/DAC/IOUT2_N: C75.2, C77.2, L7.1, R26.2, U3.60 (IOUT2N)
/DAC/IOUT2_P: C76.1, C78.2, L8.1, R27.1, U3.59 (IOUT2P)
/DAC/OUT1: R34.2, R76.1, TP1.1 (1_1), U4.6
/DAC/OUT2: R46.2, R77.2, TP2.1 (1_1), U5.6
/DAC/P1D0: RN6.1 (R1.1), U3.24 (P1D0)
/DAC/P1D1: RN6.2 (R2.1), U3.23 (P1D1)
/DAC/P1D2: RN6.3 (R3.1), U3.22 (P1D2)
/DAC/P1D3: RN6.4 (R4.1), U3.21 (P1D3)
/DAC/P1D4: RN7.1 (R1.1), U3.20 (P1D4)
/DAC/P1D5: RN7.2 (R2.1), U3.19 (P1D5)
/DAC/P1D6: RN7.3 (R3.1), U3.18 (P1D6)
/DAC/P1D7: RN7.4 (R4.1), U3.17 (P1D7)
/DAC/P1D8: RN8.1 (R1.1), U3.16 (P1D8)
/DAC/P1D9: RN8.2 (R2.1), U3.15 (P1D9)
/DAC/P1D10: RN8.3 (R3.1), U3.14 (P1D10)
/DAC/P1D11: RN8.4 (R4.1), U3.13 (P1D11)
/DAC/P1D12: RN9.1 (R1.1), U3.12 (P1D12)
/DAC/P1D13: RN9.2 (R2.1), U3.11 (P1D13)
/DAC/P1D14: RN9.3 (R3.1), U3.10 (P1D14)
/DAC/P1D15: RN9.4 (R4.1), U3.9 (P1D15)
/DAC/P2D0: RN5.1 (R1.1), U3.46 (P2D0)
/DAC/P2D1: RN5.2 (R2.1), U3.45 (P2D1)
/DAC/P2D2: RN5.3 (R3.1), U3.44 (P2D2)
/DAC/P2D3: RN5.4 (R4.1), U3.43 (P2D3)
/DAC/P2D4: RN4.1 (R1.1), U3.42 (P2D4)
/DAC/P2D5: RN4.2 (R2.1), U3.41 (P2D5)
/DAC/P2D6: RN4.3 (R3.1), U3.40 (P2D6)
/DAC/P2D7: RN4.4 (R4.1), U3.39 (P2D7)
/DAC/P2D8: RN3.1 (R1.1), U3.38 (P2D8)
/DAC/P2D9: RN3.2 (R2.1), U3.37 (P2D9)
/DAC/P2D10: RN3.3 (R3.1), U3.36 (P2D10)
/DAC/P2D11: RN3.4 (R4.1), U3.35 (P2D11)
/DAC/P2D12: RN2.1 (R1.1), U3.34 (P2D12)
/DAC/P2D13: RN2.2 (R2.1), U3.33 (P2D13)
/DAC/P2D14: RN2.3 (R3.1), U3.32 (P2D14)
/DAC/P2D15: RN2.4 (R4.1), U3.31 (P2D15)
/DAC/REFIO: C56.2, U3.55 (REFIO)
/DAC/offset1: R24.2, TP7.1 (1_1), U3.66 (AUC1P)
/DAC/offset2: R25.2, TP8.1 (1_1), U3.62 (AUX2P)
/FPGA_Config/JTAG_TCK: R10.2, RN1.8 (R1.2), U1.14 (TCK)
/FPGA_Config/JTAG_TDI: RN1.7 (R2.2), U1.16 (TDI)
/FPGA_Config/JTAG_TDO: RN1.6 (R3.2), U1.18 (TDO)
/FPGA_Config/JTAG_TMS: RN1.5 (R4.2), U1.13 (TMS)
/FPGA_Config/MSPI_MCLK: R1.2, U1.93 (MCLK), U2.6 (CLK)
/FPGA_Config/MSPI_MCS: U1.94 (MCS), U2.1 (~CS)
/FPGA_Config/MSPI_MI: U1.96 (MI), U2.2 (DO/IO_{1})
/FPGA_Config/MSPI_MO: U1.95 (MO), U2.5 (DI/IO_{0})
/FPGA_Ctrl.Ctrl_FPGA_NRST: J2.6, U1.126 (IOT23A)
/FPGA_Ctrl.Ctrl_SPI_CLK: J2.2, U1.131 (IOT14B)
/FPGA_Ctrl.Ctrl_SPI_CS: J2.1, U1.132 (IOT14A)
/FPGA_Ctrl.Ctrl_SPI_MISO: J2.3, R75.1
/FPGA_Ctrl.Ctrl_SPI_MOSI: J2.4, U1.129 (IOT17B)
/FPGA_Ctrl.GPIO1: J2.7, U1.125 (IOT22A)
/FPGA_Ctrl.GPIO2: J2.8, U1.124 (IOT23B)
/Power/FB_1.0V: R70.1, R71.2, U11.8 (FB)
Clock_V_{DDIO}: C115.2, C116.2, C117.2, FB16.2, U8.15 (VDDO_34), U8.16 (VDDO_12)
Clock_V_{DD}: C97.2, C110.2, C111.2, FB14.2, R47.2, R54.2, R55.2, R56.1, R57.1, U8.3 (VDD_REF)
Clock_V_{TCXO}: C118.2, C119.2, C120.2, FB17.2, Y1.4 (Vdd)
Clock_V_{VCO}: C112.2, C113.2, C114.2, FB15.2, U8.24 (VDD_VCO)
GND: C1.2, C2.1, C3.1, C4.1, C5.1, C6.1, C7.1, C8.1, C9.1, C10.1, C11.1, C12.1, C13.1, C14.1, C15.1, C16.1, C17.1, C18.1, C19.1, C20.1, C21.1, C22.1, C23.1, C24.1, C25.1, C26.1, C27.1, C28.1, C29.1, C30.1, C31.1, C32.1, C33.1, C34.1, C35.1, C36.1, C37.1, C38.1, C39.1, C40.1, C41.1, C42.1, C43.1, C44.1, C45.1, C46.1, C47.1, C48.1, C49.1, C50.1, C51.1, C52.1, C53.1, C54.1, C55.1, C56.1, C59.1, C60.1, C61.1, C62.1, C63.1, C64.1, C65.2, C66.2, C67.2, C68.2, C75.1, C76.2, C79.1, C80.2, C83.1, C84.2, C87.1, C88.2, C91.1, C92.1, C93.1, C94.1, C96.1, C97.1, C98.1, C99.1, C100.1, C101.1, C102.1, C103.1, C104.1, C105.1, C106.1, C107.1, C108.1, C109.2, C110.1, C111.1, C112.1, C113.1, C114.1, C115.1, C116.1, C117.1, C118.1, C119.1, C120.1, C145.1, C146.1, C147.1, C148.2, C152.2, C153.1, C154.1, C155.1, C160.2, C161.1, C162.1, C163.2, C164.2, C165.1, C166.1, C167.2, C168.2, C169.1, C170.2, C171.1, C172.2, C173.1, C174.1, C175.1, C176.1, C177.1, D1.1 (K), HS2.1, J1.6, J1.10, J2.9, J2.10, J2.11, J2.12, J2.13, J2.14, J2.15, J2.16, J3.4, J4.2, J4.5, J4.7, J5.2 (Ext), J6.2 (Ext), J7.2 (Ext), R1.1, R4.2, R5.2, R6.2, R10.1, R13.1, R14.1, R19.1, R24.1, R25.1, R28.2, R29.2, R30.1, R33.2, R35.1, R38.1, R41.2, R42.1, R45.2, R48.1, R53.1, R71.1, R72.1, R74.1, U1.2 (VSS), U1.17 (VSS), U1.53 (VSS), U1.74 (VSS), U1.89 (VSS), U1.107 (VSS), U1.145 (EPAD), U2.4 (GND), U3.2 (CVSS), U3.5 (CVSS), U3.7 (DVSS), U3.28 (DVSS), U3.48 (DVSS), U3.58 (AVSS), U3.61 (AVSS), U3.64 (AVSS), U3.67 (AVSS), U3.70 (AVSS), U3.73 (EP), U6.3 (+), U6.5 (+), U8.25 (GND), U11.4 (GND), U12.2 (GND), U13.1 (GND), U14.7 (GND), U14.8 (1.6V), U14.11 (0.2V), U14.12 (0.1V), U14.17 (NC), U14.18 (NC), U14.19 (NC), U14.21 (EP), U15.4 (GND), U15.11 (GND), Y1.2 (GND)
unnamed: C59.2, C60.2, R16.1, R17.2, R18.1, R19.2
unnamed: C62.2, C69.1, C70.2, L1.2, L2.1
unnamed: C63.2, C70.1, C71.2, L2.2, L3.1
unnamed: C64.2, C71.1, L3.2, R30.2, R32.1, R36.2, TP6.1 (1_1)
unnamed: C66.1, C72.1, C73.2, L4.2, L5.1
unnamed: C67.1, C73.1, C74.2, L5.2, L6.1
unnamed: C68.1, C74.1, L6.2, R29.1, R31.1, R37.1, TP5.1 (1_1)
unnamed: C77.1, C79.2, C81.2, L7.2, L9.1
unnamed: C78.1, C80.1, C82.2, L8.2, L10.1
unnamed: C81.1, C83.2, C85.2, L9.2, L11.1
unnamed: C82.1, C84.1, C86.2, L10.2, L12.1
unnamed: C85.1, C87.2, L11.2, R39.2, R42.2, R44.1, TP3.1 (1_1)
unnamed: C86.1, C88.1, L12.2, R40.1, R41.1, R43.1, TP4.1 (1_1)
unnamed: C90.2, R50.1, U6.7
unnamed: C95.2, R52.1, U6.1
unnamed: D1.2 (A), R11.2
unnamed: J1.1, RN1.1 (R1.1)
unnamed: J1.2, RN1.2 (R2.1)
unnamed: J1.3, RN1.3 (R3.1)
unnamed: J1.5, RN1.4 (R4.1)
unnamed: J1.8, R12.1
unnamed: J5.1 (In), R76.2
unnamed: J6.1 (In), R77.1
unnamed: Q1.1 (B), R50.2
unnamed: C91.2, C92.2, Q1.2 (E), R49.2
unnamed: Q2.1 (B), R52.2
unnamed: C93.2, C94.2, Q2.2 (E), R51.2
unnamed: R22.1, R23.2, R35.2, R49.1
unnamed: R26.1, R27.2, R38.2, R51.1
unnamed: RN2.8 (R1.2), U1.50 (IOB20A)
unnamed: RN2.7 (R2.2), U1.51 (IOB20B)
unnamed: RN2.6 (R3.2), U1.52 (IOB22A)
unnamed: RN2.5 (R4.2), U1.54 (IOB22B)
unnamed: RN3.8 (R1.2), U1.46 (IOB14A)
unnamed: RN3.7 (R2.2), U1.47 (IOB14B)
unnamed: RN3.6 (R3.2), U1.48 (IOB17A)
unnamed: RN3.5 (R4.2), U1.49 (IOB17B)
unnamed: RN4.8 (R1.2), U1.42 (IOB7A)
unnamed: RN4.7 (R2.2), U1.43 (IOB7B)
unnamed: RN4.6 (R3.2), U1.44 (IOB12A)
unnamed: RN4.5 (R4.2), U1.45 (IOB12B)
unnamed: RN5.8 (R1.2), U1.38 (IOB5A)
unnamed: RN5.7 (R2.2), U1.39 (IOB5B)
unnamed: RN5.6 (R3.2), U1.40 (IOB6A)
unnamed: RN5.5 (R4.2), U1.41 (IOB6B)
unnamed: RN6.8 (R1.2), U1.57 (IOB30B/GCLKC_4)
unnamed: RN6.7 (R2.2), U1.58 (IOB33A)
unnamed: RN6.6 (R3.2), U1.59 (IOB33B)
unnamed: RN6.5 (R4.2), U1.60 (IOB34A)
unnamed: RN7.8 (R1.2), U1.61 (IOB34B)
unnamed: RN7.7 (R2.2), U1.62 (IOB38A)
unnamed: RN7.6 (R3.2), U1.63 (IOB38B)
unnamed: RN7.5 (R4.2), U1.64 (IOB40A)
unnamed: RN8.8 (R1.2), U1.65 (IOB40B)
unnamed: RN8.7 (R2.2), U1.66 (IOB42A)
unnamed: RN8.6 (R3.2), U1.67 (IOB42B)
unnamed: RN8.5 (R4.2), U1.68 (IOB48A)
unnamed: RN9.8 (R1.2), U1.69 (IOB48B)
unnamed: RN9.7 (R2.2), U1.70 (IOB53A)
unnamed: RN9.6 (R3.2), U1.71 (IOB53B)
unnamed: RN9.5 (R4.2), U1.72 (IOB55B)
unnamed: R9.1, R11.1, U1.21 (DONE)
unnamed: R13.2, U1.75 (EXTR)
unnamed: R4.1, U1.144 (MODE0)
unnamed: R5.1, U1.142 (MODE1)
unnamed: R6.1, U1.143 (MODE2)
unnamed: R8.1, U1.22 (READY)
unnamed: R7.1, U1.20 (RECONFIG_N)
unnamed: R75.2, U1.130 (IOT17A)
unnamed: R59.2, U1.33 (IOL42B)
unnamed: R60.2, U1.34 (IOL45A/LPLL2_T_in)
unnamed: R3.2, U2.7 (~HOLD/~RESET/IO_{3})
unnamed: R2.2, U2.3 (~WP/IO_{2})
unnamed: R20.1, U3.25 (DCO)
unnamed: R28.1, U3.29 (IQSEL)
unnamed: R58.2, U3.49 (SDO)
unnamed: R31.2, R33.1, U4.3 (+)
unnamed: R32.2, R34.1, U4.2 (-)
unnamed: C96.2, C98.2, FB5.2, U4.7 (V+)
unnamed: C99.2, C100.2, FB6.2, U4.4 (V-)
unnamed: R43.2, R45.1, U5.3 (+)
unnamed: R44.2, R46.1, U5.2 (-)
unnamed: C101.2, C103.2, FB7.2, U5.7 (V+)
unnamed: C102.2, C104.2, FB8.2, U5.4 (V-)
unnamed: C95.1, R39.1, R40.2, U6.2 (-)
unnamed: C90.1, R36.1, R37.2, U6.6 (-)
unnamed: C105.2, C107.2, FB9.2, U6.8 (V+)
unnamed: C106.2, C108.2, FB10.2, U6.4 (V-)
unnamed: R53.2, U8.23 (EEPROM_SEL)
unnamed: R54.1, U8.4 (REFSEL)
unnamed: C149.2, U11.6 (BST)
unnamed: C148.1, U11.7 (SS)
unnamed: C149.1, L15.1, U11.5 (SW)
unnamed: C166.2, U14.14 (NR)
unnamed: R69.1, R72.2, U15.3 (FB)
unnamed: C171.2, U15.8 (NR/SS)
unnamed: R73.1, R74.2, U19.1 (ADJ)
VCC_Core: C10.2, C11.2, C12.2, C13.2, C14.2, FB3.2, U1.1 (VCC/VCC_PLLL1), U1.36 (VCC/VCC_PLLL1), U1.73 (VCC/VCC_PLLL1), U1.108 (VCC/VCC_PLLL1)
VCC_PLLL: C6.2, C7.2, C8.2, FB2.2, U1.8 (VCCPLL_L0)
VCC_PLLR: C3.2, C4.2, C5.2, C9.2, FB1.2, U1.81 (VCCPLL_R1), U1.104 (VCCPLL_R0)

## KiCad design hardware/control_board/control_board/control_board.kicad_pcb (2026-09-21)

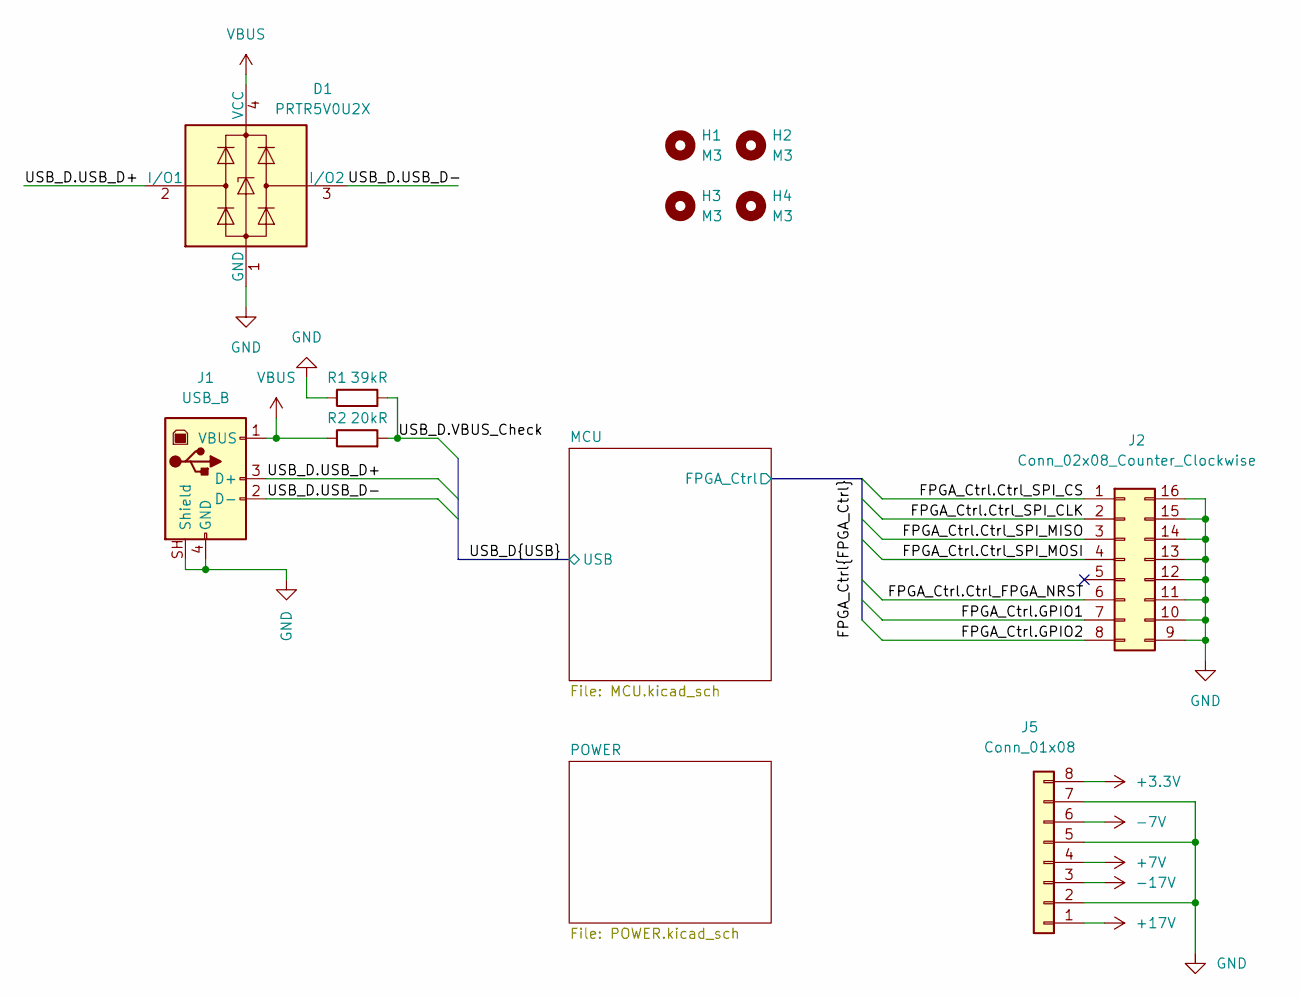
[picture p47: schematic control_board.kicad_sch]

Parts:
D1: PRTR5V0U2X; SOT-143
H1, H2, H3, H4: M3; MountingHole_3.2mm_M3
J1: USB_B; USB_B_Lumberg_2411_02_Horizontal
J2: Conn_02x08_Counter_Clockwise; IDC_IDC-Header_2x08_P2.54mm_Vertical_antiClockWise
J5: Conn_01x08; JST_VH_B8P-VH_1x08_P3.96mm_Vertical
R1: 39kR; R_0603_1608Metric
R2: 20kR; R_0603_1608Metric

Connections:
+3.3V: J5.8; also elsewhere on the board
+7V: J5.4; also elsewhere on the board
+17V: J5.1; also elsewhere on the board
-7V: J5.6; also elsewhere on the board
-17V: J5.3; also elsewhere on the board
/FPGA_Ctrl.Ctrl_FPGA_NRST: J2.6; also elsewhere on the board
/FPGA_Ctrl.Ctrl_SPI_CLK: J2.2; also elsewhere on the board
/FPGA_Ctrl.Ctrl_SPI_CS: J2.1; also elsewhere on the board
/FPGA_Ctrl.Ctrl_SPI_MISO: J2.3; also elsewhere on the board
/FPGA_Ctrl.Ctrl_SPI_MOSI: J2.4; also elsewhere on the board
/FPGA_Ctrl.GPIO1: J2.7; also elsewhere on the board
/FPGA_Ctrl.GPIO2: J2.8; also elsewhere on the board
/USB_D.USB_D+: D1.2 (I/O1), J1.3 (D+); also elsewhere on the board
/USB_D.USB_D-: D1.3 (I/O2), J1.2 (D-); also elsewhere on the board
/USB_D.VBUS_Check: R1.2, R2.2; also elsewhere on the board
GND: D1.1 (GND), J1.4 (GND), J1.SH (Shield), J2.9, J2.10, J2.11, J2.12, J2.13, J2.14, J2.15, J2.16, J5.2, J5.5, J5.7, R1.1; also elsewhere on the board
VBUS: D1.4 (VCC), J1.1 (VBUS), R2.1

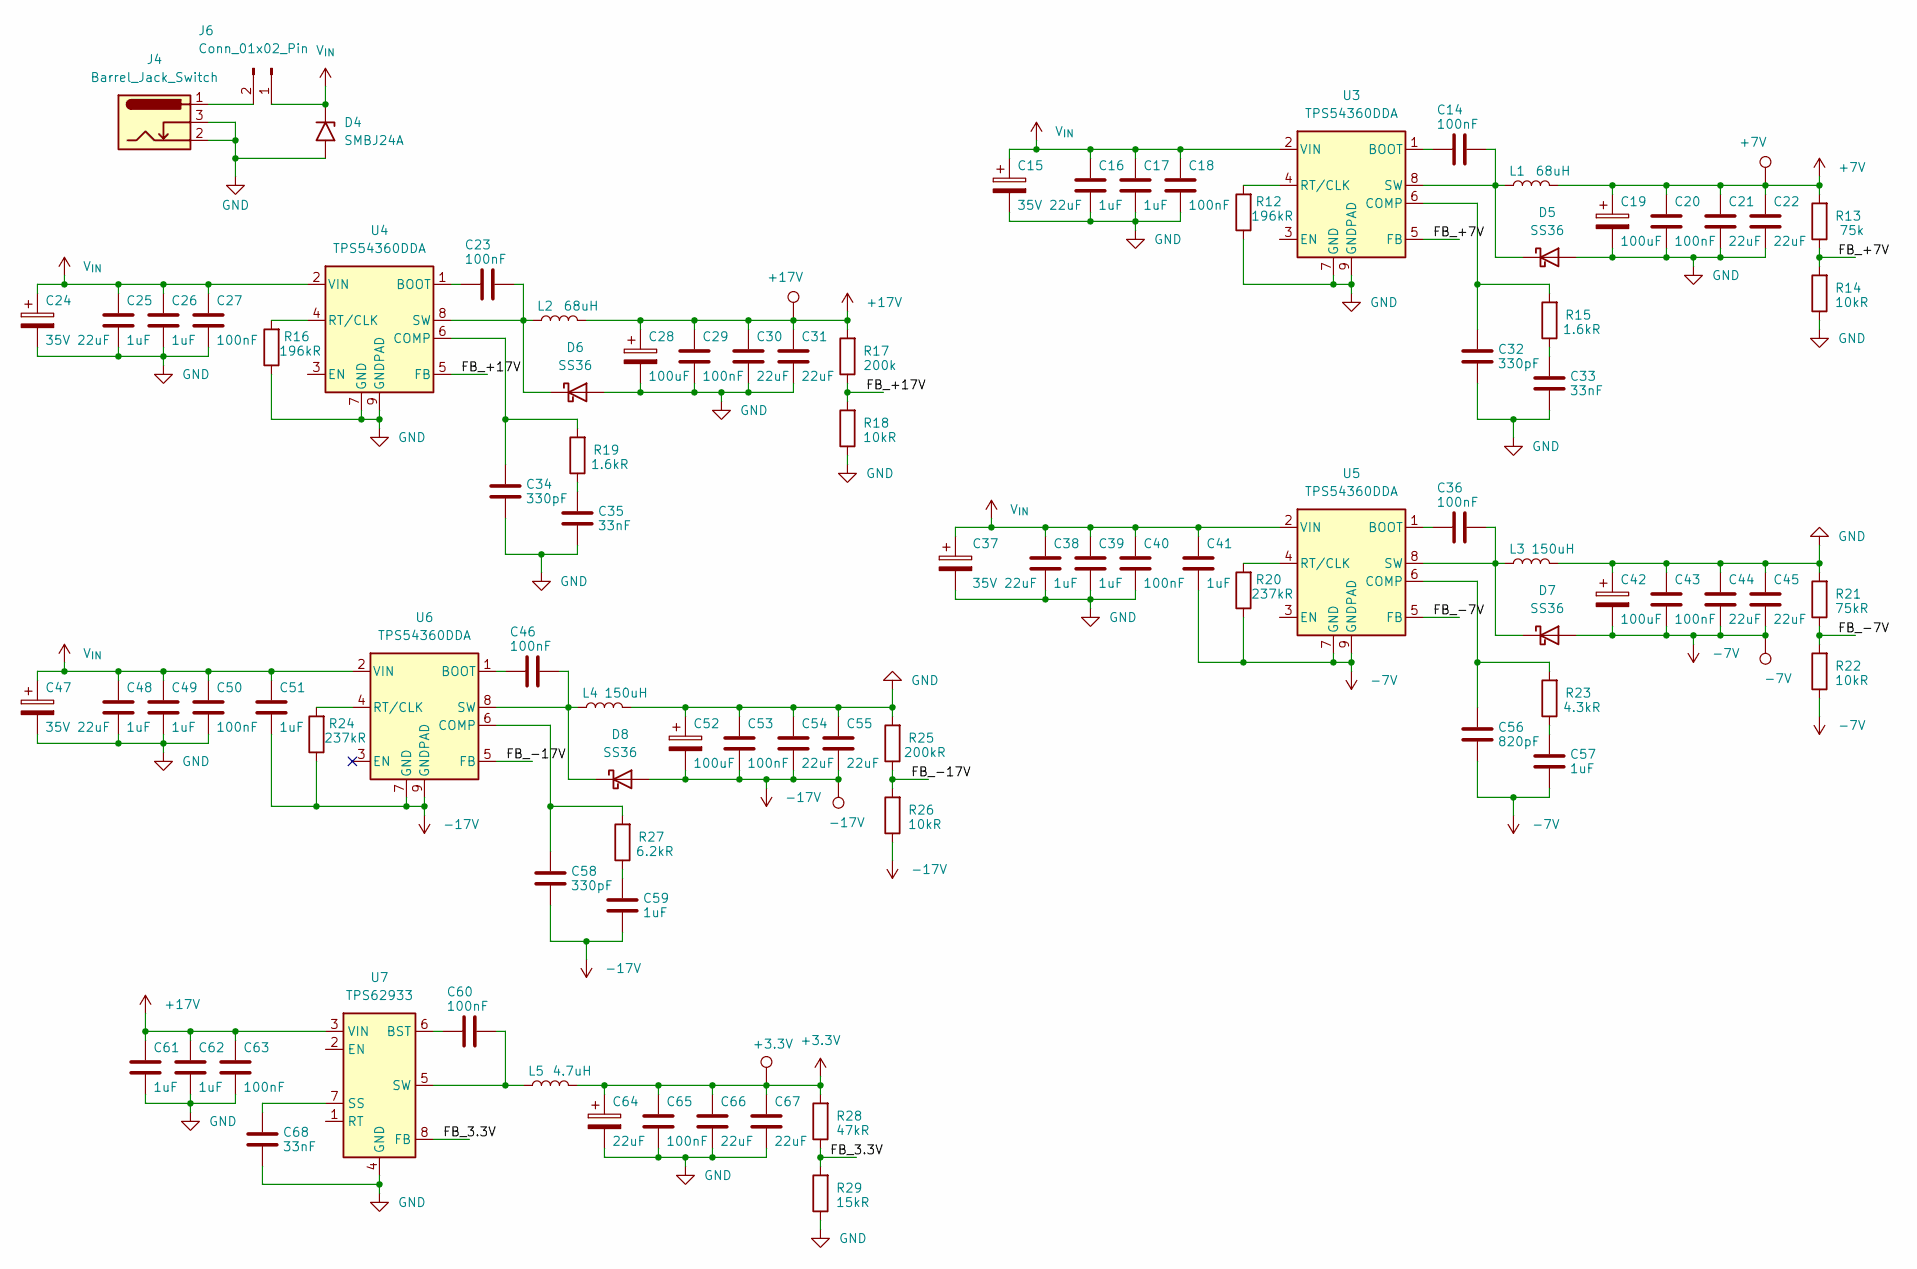
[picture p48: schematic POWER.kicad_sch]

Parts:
C14, C18, C20, C23, C27, C29, C36, C40, C43, C46, C50, C53, C60, C63, C65: 100nF; C_0603_1608Metric
C15, C24, C37, C47: 35V 22uF; CP_Elec_5x5.4
C16, C17, C25, C26, C38, C39, C48, C49, C61, C62: 1uF; C_1206_3216Metric
C19, C28, C42, C52: 100uF; C_Elec_6.3x7.7
C21, C22, C30, C31, C44, C45, C54, C55, C66, C67: 22uF; C_1206_3216Metric
C32, C34, C58: 330pF; C_0603_1608Metric
C33, C35, C68: 33nF; C_0603_1608Metric
C41, C51, C57, C59: 1uF; C_0603_1608Metric
C56: 820pF; C_0603_1608Metric
C64: 22uF; CP_Elec_5x5.4
D4: SMBJ24A; D_SMB
D5, D6, D7, D8: SS36; D_SMA
J4: Barrel_Jack_Switch; BarrelJack_GCT_DCJ200-10-A_Horizontal
J6: Conn_01x02_Pin; JST_VH_B2P-VH-B_1x02_P3.96mm_Vertical
L1, L2: 68uH; L_Changjiang_FXL1040
L3, L4: 150uH; L_12x12mm_H6mm
L5: 4.7uH; L_Changjiang_FXL0420
R12, R16: 196kR; R_0603_1608Metric
R13: 75k; R_0603_1608Metric
R14, R18, R22, R26: 10kR; R_0603_1608Metric
R15, R19: 1.6kR; R_0603_1608Metric
R17: 200k; R_0603_1608Metric
R20, R24: 237kR; R_0603_1608Metric
R21: 75kR; R_0603_1608Metric
R23: 4.3kR; R_0603_1608Metric
R25: 200kR; R_0603_1608Metric
R27: 6.2kR; R_0603_1608Metric
R28: 47kR; R_0603_1608Metric
R29: 15kR; R_0603_1608Metric
TP7: +7V; TestPoint_Pad_D1.0mm
TP8: +17V; TestPoint_Pad_D1.0mm
TP9: -7V; TestPoint_Pad_D1.0mm
TP10: -17V; TestPoint_Pad_D1.0mm
TP11: +3.3V; TestPoint_Pad_D1.0mm
U3, U4, U5, U6: TPS54360DDA; TI_SO-PowerPAD-8_ThermalVias
U7: TPS62933; SOT-583-8

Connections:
+3.3V: C64.1, C65.2, C66.2, C67.2, L5.2, R28.2, TP11.1 (1_1); also elsewhere on the board
+7V: C19.1, C20.2, C21.2, C22.2, L1.2, R13.2, TP7.1 (1_1); also elsewhere on the board
+17V: C28.1, C29.2, C30.2, C31.2, C61.2, C62.2, C63.2, L2.2, R17.2, TP8.1 (1_1), U7.3 (VIN); also elsewhere on the board
-7V: C41.1, C42.2, C43.1, C44.1, C45.1, C56.2, C57.2, D7.2 (A), R20.1, R22.1, TP9.1 (1_1), U5.7 (GND), U5.9 (GNDPAD); also elsewhere on the board
-17V: C51.1, C52.2, C53.1, C54.1, C55.1, C58.2, C59.2, D8.2 (A), R24.1, R26.1, TP10.1 (1_1), U6.7 (GND), U6.9 (GNDPAD); also elsewhere on the board
/POWER/FB_3.3V: R28.1, R29.2, U7.8 (FB)
/POWER/FB_+7V: R13.1, R14.2, U3.5 (FB)
/POWER/FB_+17V: R17.1, R18.2, U4.5 (FB)
/POWER/FB_-7V: R21.1, R22.2, U5.5 (FB)
/POWER/FB_-17V: R25.1, R26.2, U6.5 (FB)
GND: C15.2, C16.1, C17.1, C18.1, C19.2, C20.1, C21.1, C22.1, C24.2, C25.1, C26.1, C27.1, C28.2, C29.1, C30.1, C31.1, C32.2, C33.2, C34.2, C35.2, C37.2, C38.1, C39.1, C40.1, C42.1, C43.2, C44.2, C45.2, C47.2, C48.1, C49.1, C50.1, C52.1, C53.2, C54.2, C55.2, C61.1, C62.1, C63.1, C64.2, C65.1, C66.1, C67.1, C68.2, D4.2 (A2), D5.2 (A), D6.2 (A), J4.2, J4.3, L3.2, L4.2, R12.1, R14.1, R16.1, R18.1, R21.2, R25.2, R29.1, U3.7 (GND), U3.9 (GNDPAD), U4.7 (GND), U4.9 (GNDPAD), U7.4 (GND); also elsewhere on the board
unnamed: C33.1, R15.1
unnamed: C35.1, R19.1
unnamed: C57.1, R23.1
unnamed: C59.1, R27.1
unnamed: C14.1, D5.1 (K), L1.1, U3.8 (SW)
unnamed: C23.1, D6.1 (K), L2.1, U4.8 (SW)
unnamed: C36.1, D7.1 (K), L3.1, U5.8 (SW)
unnamed: C46.1, D8.1 (K), L4.1, U6.8 (SW)
unnamed: J4.1, J6.2
unnamed: C14.2, U3.1 (BOOT)
unnamed: C32.1, R15.2, U3.6 (COMP)
unnamed: R12.2, U3.4 (RT/CLK)
unnamed: C23.2, U4.1 (BOOT)
unnamed: C34.1, R19.2, U4.6 (COMP)
unnamed: R16.2, U4.4 (RT/CLK)
unnamed: C36.2, U5.1 (BOOT)
unnamed: C56.1, R23.2, U5.6 (COMP)
unnamed: R20.2, U5.4 (RT/CLK)
unnamed: C46.2, U6.1 (BOOT)
unnamed: C58.1, R27.2, U6.6 (COMP)
unnamed: R24.2, U6.4 (RT/CLK)
unnamed: C60.2, U7.6 (BST)
unnamed: C68.1, U7.7 (SS)
unnamed: C60.1, L5.1, U7.5 (SW)
V_{IN}: C15.1, C16.2, C17.2, C18.2, C24.1, C25.2, C26.2, C27.2, C37.1, C38.2, C39.2, C40.2, C41.2, C47.1, C48.2, C49.2, C50.2, C51.2, D4.1 (A1), J6.1, U3.2 (VIN), U4.2 (VIN), U5.2 (VIN), U6.2 (VIN)

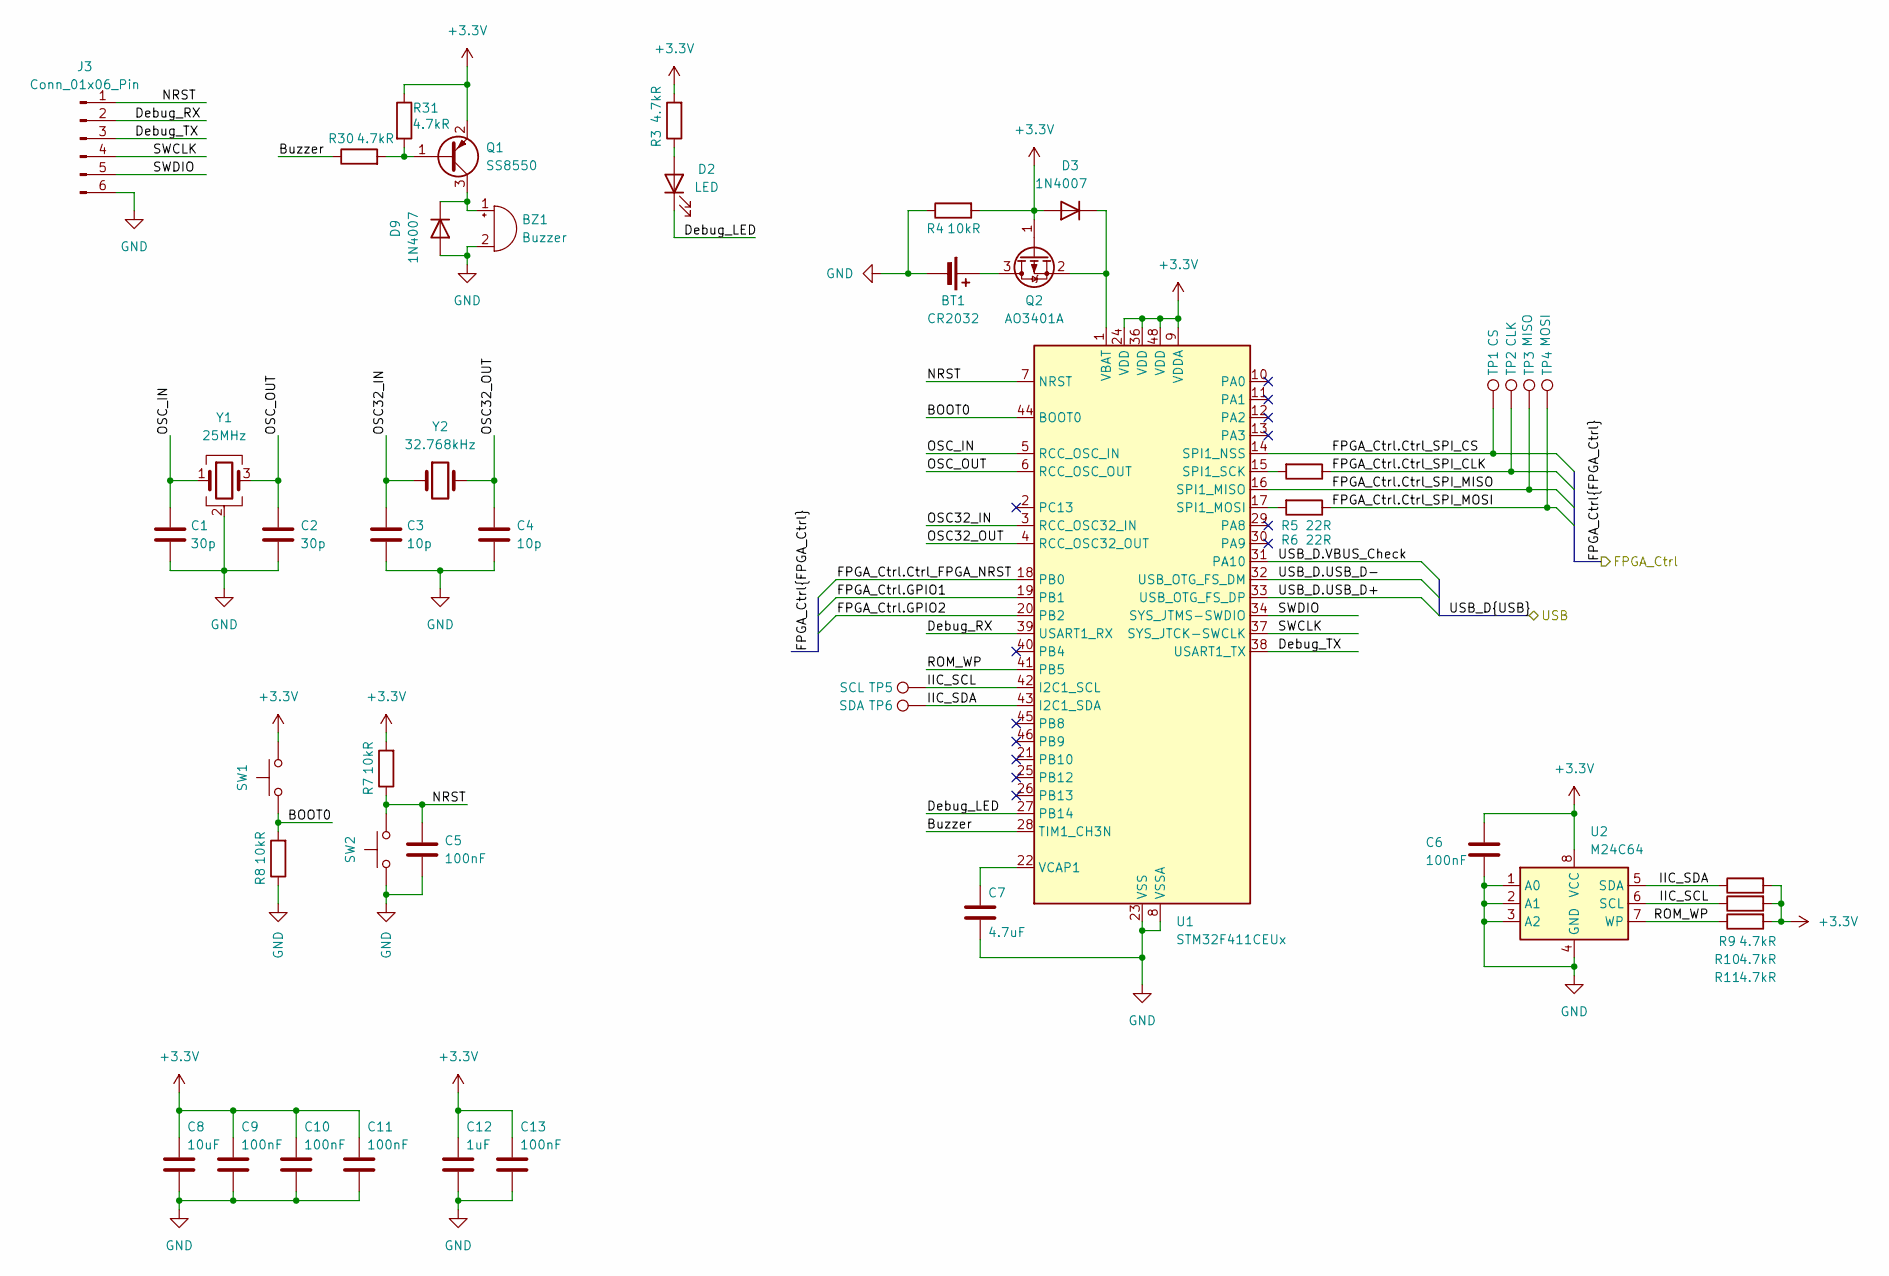
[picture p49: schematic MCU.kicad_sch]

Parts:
BT1: CR2032; BAT-TH_BS-05-A1BJ001
BZ1: Buzzer; MagneticBuzzer_StarMicronics_QMX
C1, C2: 30p; C_0603_1608Metric
C3, C4: 10p; C_0603_1608Metric
C5, C6, C9, C10, C11, C13: 100nF; C_0603_1608Metric
C7: 4.7uF; C_0603_1608Metric
C8: 10uF; C_0603_1608Metric
C12: 1uF; C_0603_1608Metric
D2: LED; LED_0603_1608Metric
D3, D9: 1N4007; D_SOD-123
J3: Conn_01x06_Pin; PinHeader_1x06_P2.54mm_Vertical
Q1: SS8550; SOT-23
Q2: AO3401A; SOT-23
R3, R9, R10, R11, R30, R31: 4.7kR; R_0603_1608Metric
R4, R7, R8: 10kR; R_0603_1608Metric
R5, R6: 22R; R_0402_1005Metric
SW1: BOOT0; SW_SPST_CK_RS282G05A3
SW2: NRST; SW_SPST_CK_RS282G05A3
TP1: CS; TestPoint_Pad_D1.0mm
TP2: CLK; TestPoint_Pad_D1.0mm
TP3: MISO; TestPoint_Pad_D1.0mm
TP4: MOSI; TestPoint_Pad_D1.0mm
TP5: SCL; TestPoint_Pad_D1.0mm
TP6: SDA; TestPoint_Pad_D1.0mm
U1: STM32F411CEUx; QFN-48-1EP_7x7mm_P0.5mm_EP5.6x5.6mm
U2: M24C64; SOIC-8_3.9x4.9mm_P1.27mm
Y1: 25MHz; Crystal_SMD_3225-4Pin_3.2x2.5mm
Y2: 32.768kHz; Crystal_SMD_3215-2Pin_3.2x1.5mm

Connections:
+3.3V: C6.1, C8.1, C9.1, C10.1, C11.1, C12.1, C13.1, D3.2 (A), Q1.2 (E), Q2.1 (G), R3.2, R4.2, R7.2, R9.2, R10.2, R11.2, R31.1, SW1.2 (B), U1.9 (VDDA), U1.24 (VDD), U1.36 (VDD), U1.48 (VDD), U2.8 (VCC); also elsewhere on the board
/FPGA_Ctrl.Ctrl_FPGA_NRST: U1.18 (PB0); also elsewhere on the board
/FPGA_Ctrl.Ctrl_SPI_CLK: R5.1, TP2.1 (1_1); also elsewhere on the board
/FPGA_Ctrl.Ctrl_SPI_CS: TP1.1 (1_1), U1.14 (SPI1_NSS); also elsewhere on the board
/FPGA_Ctrl.Ctrl_SPI_MISO: TP3.1 (1_1), U1.16 (SPI1_MISO); also elsewhere on the board
/FPGA_Ctrl.Ctrl_SPI_MOSI: R6.1, TP4.1 (1_1); also elsewhere on the board
/FPGA_Ctrl.GPIO1: U1.19 (PB1); also elsewhere on the board
/FPGA_Ctrl.GPIO2: U1.20 (PB2); also elsewhere on the board
/MCU/BOOT0: R8.2, SW1.1 (A), U1.44 (BOOT0)
/MCU/Buzzer: R30.1, U1.28 (TIM1_CH3N)
/MCU/Debug_LED: D2.1 (K), U1.27 (PB14)
/MCU/Debug_RX: J3.2, U1.39 (USART1_RX)
/MCU/Debug_TX: J3.3, U1.38 (USART1_TX)
/MCU/IIC_SCL: R10.1, TP5.1 (1_1), U1.42 (I2C1_SCL), U2.6 (SCL)
/MCU/IIC_SDA: R9.1, TP6.1 (1_1), U1.43 (I2C1_SDA), U2.5 (SDA)
/MCU/NRST: C5.1, J3.1, R7.1, SW2.2 (B), U1.7 (NRST)
/MCU/OSC32_IN: C3.1, U1.3 (RCC_OSC32_IN), Y2.1
/MCU/OSC32_OUT: C4.1, U1.4 (RCC_OSC32_OUT), Y2.2
/MCU/OSC_IN: C1.1, U1.5 (RCC_OSC_IN), Y1.1
/MCU/OSC_OUT: C2.1, U1.6 (RCC_OSC_OUT), Y1.3
/MCU/ROM_WP: R11.1, U1.41 (PB5), U2.7 (WP)
/MCU/SWCLK: J3.4, U1.37 (SYS_JTCK-SWCLK)
/MCU/SWDIO: J3.5, U1.34 (SYS_JTMS-SWDIO)
/USB_D.USB_D+: U1.33 (USB_OTG_FS_DP); also elsewhere on the board
/USB_D.USB_D-: U1.32 (USB_OTG_FS_DM); also elsewhere on the board
/USB_D.VBUS_Check: U1.31 (PA10); also elsewhere on the board
GND: BT1.2 (-), BZ1.2 (-), C1.2, C2.2, C3.2, C4.2, C5.2, C6.2, C7.1, C8.2, C9.2, C10.2, C11.2, C12.2, C13.2, D9.2 (A), J3.6, R4.1, R8.1, SW2.1 (A), U1.8 (VSSA), U1.23 (VSS), U1.35 (VSS), U1.47 (VSS), U1.49 (VSS), U2.1 (A0), U2.2 (A1), U2.3 (A2), U2.4 (GND), Y1.2 (G), Y1.4 (G); also elsewhere on the board
unnamed: BT1.1 (+), Q2.3 (D)
unnamed: BZ1.1 (+), D9.1 (K), Q1.3 (C)
unnamed: D2.2 (A), R3.1
unnamed: D3.1 (K), Q2.2 (S), U1.1 (VBAT)
unnamed: Q1.1 (B), R30.2, R31.2
unnamed: R5.2, U1.15 (SPI1_SCK)
unnamed: R6.2, U1.17 (SPI1_MOSI)
unnamed: C7.2, U1.22 (VCAP1)

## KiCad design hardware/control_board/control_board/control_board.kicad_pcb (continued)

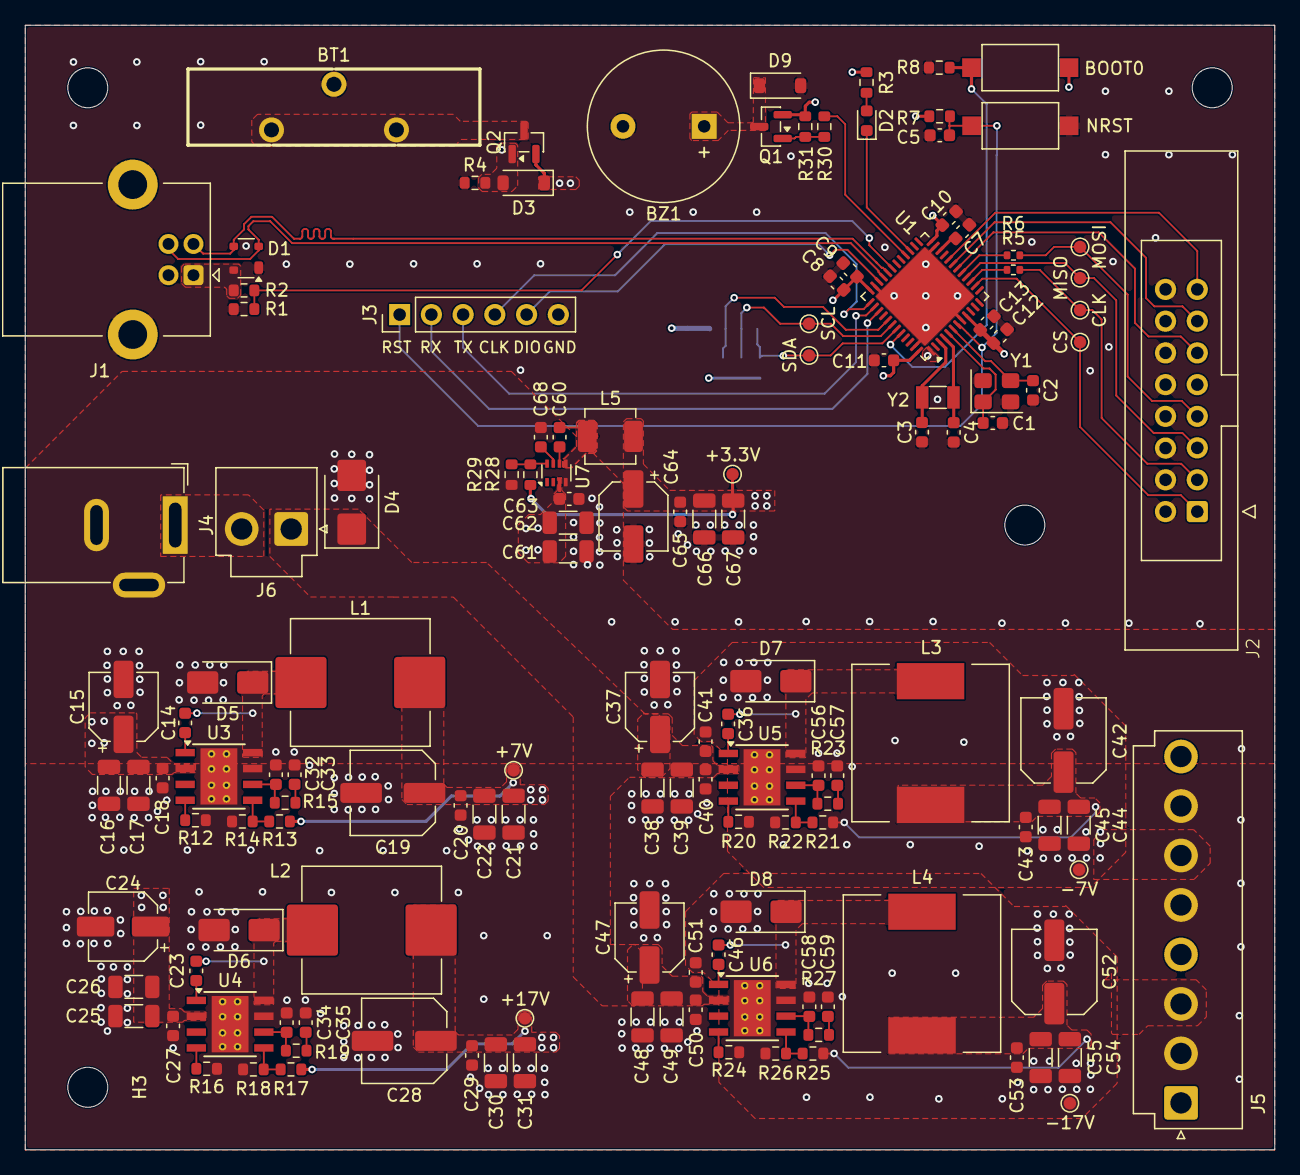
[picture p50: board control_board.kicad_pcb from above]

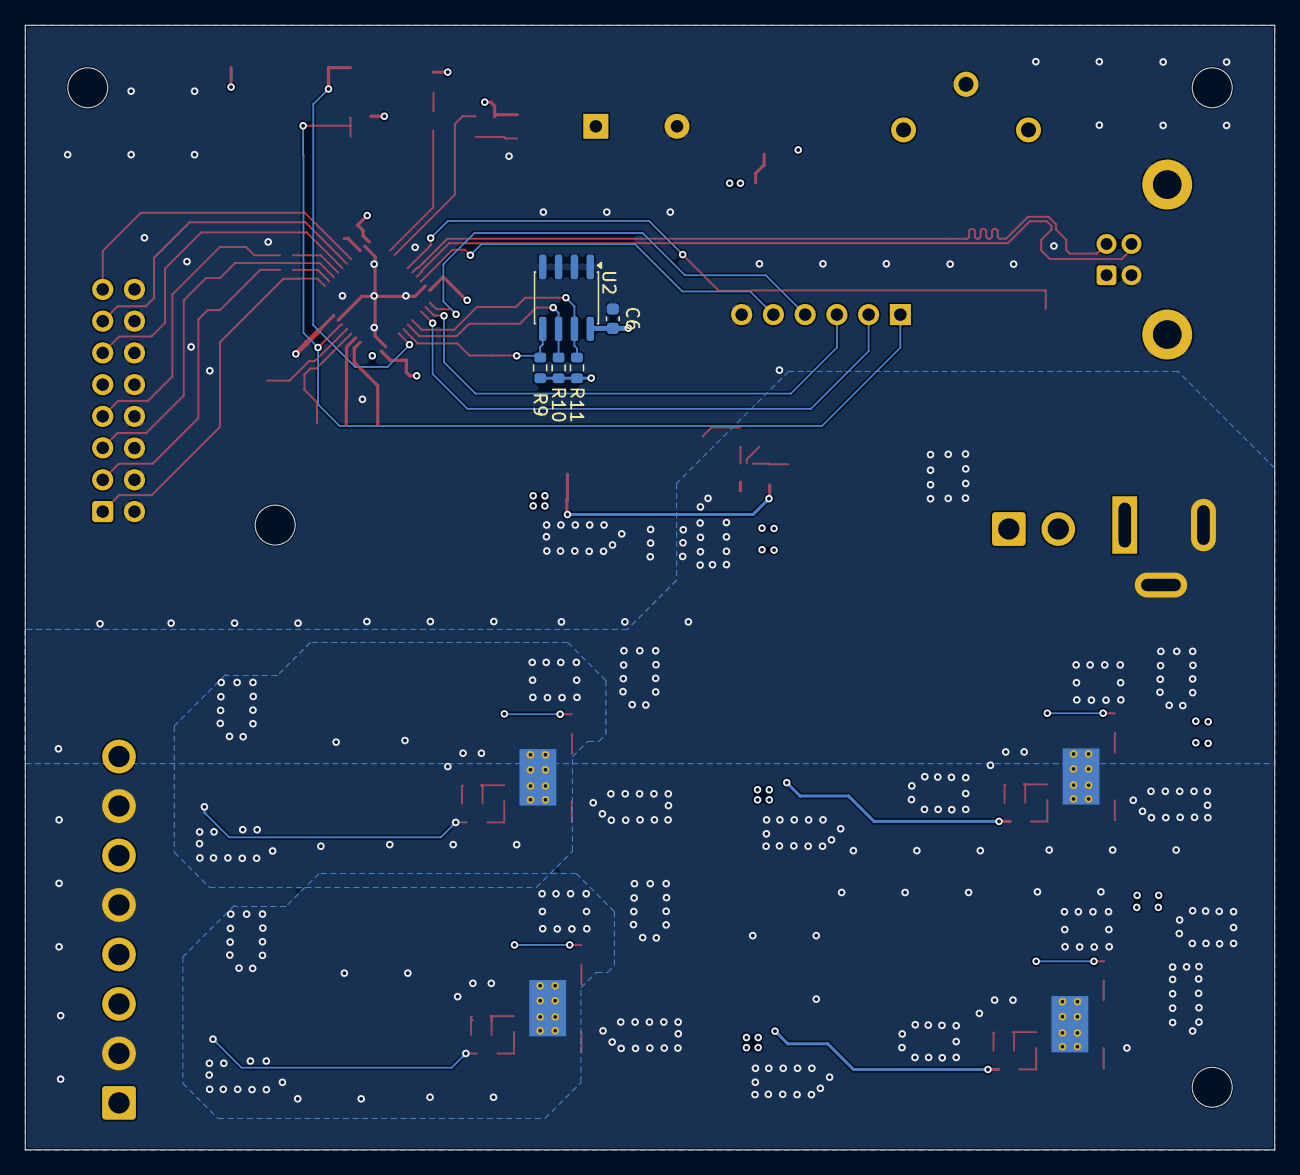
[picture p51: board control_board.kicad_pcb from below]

Board: 4 copper layers, 100.0 x 90.0 mm, 149 parts (5 on the bottom side), 70 nets.

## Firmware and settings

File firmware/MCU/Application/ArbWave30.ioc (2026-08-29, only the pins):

Mcu.UserName=STM32F411CEUx
PA10.GPIO_Label=VBUS_Check
PA10.Signal=GPXTI10
PA11.Signal=USB_OTG_FS_DM
PA12.Signal=USB_OTG_FS_DP
PA13.Signal=SYS_JTMS-SWDIO
PA14.Signal=SYS_JTCK-SWCLK
PA15.Signal=USART1_TX
PA4.GPIO_Label=SPI1_CS
PA4.Signal=GPIO_Output
PA5.Signal=SPI1_SCK
PA6.Signal=SPI1_MISO
PA7.Signal=SPI1_MOSI
PB0.GPIO_Label=FPGA_NRST
PB0.Signal=GPIO_Output
PB1.GPIO_Label=FPGA_INT
PB1.Signal=GPXTI1
PB14.GPIO_Label=Debug_LED
PB14.Signal=GPIO_Output
PB15.GPIO_Label=Buzzer
PB15.Signal=TIM1_CH3N
PB2.GPIO_Label=GPIO2
PB2.Signal=GPIO_Output
PB3.Signal=USART1_RX
PB5.GPIO_Label=ROM_WP
PB5.Signal=GPIO_Output
PB6.Signal=I2C1_SCL
PB7.Signal=I2C1_SDA
PC14-OSC32_IN.Signal=RCC_OSC32_IN
PC15-OSC32_OUT.Signal=RCC_OSC32_OUT

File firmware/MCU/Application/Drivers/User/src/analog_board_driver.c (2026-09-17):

/*
 * SPDX-License-Identifier: GPL-3.0-only
 * Copyright (C) 2026 [EERNINUO]
 *
 * [This file is part of ArbWave30.]
 *
 * ArbWave30 is free software: you can redistribute it and/or modify
 * it under the terms of the GNU General Public License as published by
 * the Free Software Foundation, version 3 of the License.
 * ...
 */

// Assisted-by: GitHub Copilot - CRC 校验函数

#include "analog_board_driver.h"
#include <stdlib.h>
#include "cmsis_os.h"
#include "calibration.h"

// 外部变量声明
// 我一直觉得这种到处extern的写法很讨厌，但是CubeMX生成的代码就是这样，很难受
extern SPI_HandleTypeDef hspi1; // 声明SPI句柄 

// 模拟板寄存器基地址定义
#define SYSTEM_BASE 0x00
#define CHANNEL1_BASE 0x10
#define CHANNEL2_BASE 0x20
#define DACMAP_BASE 0x30

// 模拟板系统控制寄存器地址偏移量
#define SYS_ID_L 0x00
#define SYS_ID_H 0x01
#define SYS_CTRL 0x02
#define SYS_STATUS 0x03

// 模拟板通道控制寄存器地址偏移量
#define CHx_CTRL 0x00
#define CHx_FREQ_L 0x01
#define CHx_FREQ_M 0x02
#define CHx_FREQ_H 0x03
#define CHx_AMPL 0x04
#define CHx_OFFSET 0x05
#define CHx_PHASE 0x06
#define CHx_DUTY 0x07
#define CHx_SLOPE_UP_L 0x08
#define CHx_SLOPE_UP_H 0x09
#define CHx_SLOPE_DOWN_L 0x0A
#define CHx_SLOPE_DOWN_H 0x0B

// 系统控制寄存器位定义

#define SYS_CTRL_UPDATE         3 
#define SYS_CTRL_DAC_CMD_WRITE  2 
#define SYS_CTRL_CLOCK_SRC      1 
#define SYS_CTRL_SOFT_RST       0 

// 通道控制寄存器位定义
#define CH_CTRL_ENABLE          15 
#define CH_CTRL_WAVEFORM        0  
#define CH_CTRL_WAVEFORM_MASK   0x3F     // 低6位

// 寄存器地址计算宏
#define REG_CH_BASE_ADDR(channel) ((channel == 1) ? CHANNEL1_BASE : CHANNEL2_BASE)
#define REG_ADDR(base, offset) ((base) + (offset))

#define spi_cs(x) \
do { \
	if (x) HAL_GPIO_WritePin(SPI_CS_Port, SPI_CS_Pin, GPIO_PIN_SET); \
	else HAL_GPIO_WritePin(SPI_CS_Port, SPI_CS_Pin, GPIO_PIN_RESET); \
} while(0)

#define analog_board_rst(x) \
do { \
	if (x) HAL_GPIO_WritePin(ANALOG_BOARD_RST_Port, ANALOG_BOARD_RST_Pin, GPIO_PIN_SET); \
	else HAL_GPIO_WritePin(ANALOG_BOARD_RST_Port, ANALOG_BOARD_RST_Pin, GPIO_PIN_RESET); \
} while(0)

#define int_read() HAL_GPIO_ReadPin(INTERRUPT_Port, INTERRUPT_Pin)

// 数据帧结构体定义
typedef struct __packed community_frame {
	uint8_t address;
	uint16_t data;
	uint8_t crc;
	uint8_t ack;
} community_frame_t;

// 模拟板配置结构体
// 这两个结构体只是镜像数据，向模拟板写入数据必须通过 setXXX 函数，操作这两个结构体不会影响模拟板
typedef struct{
    bool enable;            // 通道使能
	bool highImpedance_enable;    // 高阻态使能
    WaveType_t waveType;    // 波形类型
    uint64_t freq_uHz;      // 频率，单位 uHz
    int16_t amplitude_mV;   // 幅度，单位 mV
    int16_t offset_mV;      // 偏移量，单位 mV
    uint16_t phase;          // 相位，单位 0.01度（0.01°）（0~36000，对应 0.00°~360.00°）
    uint16_t duty;          // 占空比/对称度，单位 0.01%，仅对三角波和方波有效（0~10000，对应 0~100.00）
} ChConfig_t;

typedef struct{
    bool extern_clock;      // 外部时钟使能
    ChConfig_t ch1;
    ChConfig_t ch2;
} AnalogBoardConfig_t;


// 模拟板配置结构体定义
static AnalogBoardConfig_t analogBoardConfig = {
	.extern_clock = false,
	.ch1 = {
		.enable = false,
		.highImpedance_enable = true,
		.waveType = WAVE_SINE,
		.duty = 5000,
		.freq_uHz = 0,
		.amplitude_mV = 0,
		.offset_mV = 0,
		.phase = 0,
	},
	.ch2 = {
		.enable = false,
		.highImpedance_enable = true,
		.waveType = WAVE_SINE,
		.duty = 5000,
		.freq_uHz = 0,
		.amplitude_mV = 0,
		.offset_mV = 0,
		.phase = 0,
	}
};

/**
 * @brief  CRC8计算函数
 * @param  data: 指向数据的指针
 * @param  length: 数据长度
 * @retval CRC8值
 */
uint8_t crc8(uint8_t *data, uint8_t length)
{
	uint8_t crc = CRC_INIT;
	for (uint8_t i = 0; i < length; i++){
		crc ^= data[i];
		for (uint8_t j = 0; j < 8; j++){
			if (crc & 0x80)
				crc = (crc << 1) ^ CRC_POLYNOMIAL;
			else
				crc <<= 1;
		}
	}

	return crc;
}

// 这里用阻塞写法只是测试程序懒得写异步了，application中肯定会用异步方式的
void analogBoard_waitReady(void)
{
	while (int_read() != GPIO_PIN_RESET) {
		// 等待模拟板准备好
	}
}

/* ---------------------------------------- 
 *  寄存器操作函数
 * --------------------------------------*/

/**
 * @brief  发送命令到模拟板
 * @param  address: 模拟板地址
 * @param  command: 命令
 * @retval ACK响应
 */
uint8_t analogBoard_sendData(uint8_t address, uint16_t command)
{
	community_frame_t frame;
	frame.address = address;
	frame.data = command;
	// 计算 CRC 时要排除CRC和ACK字段
	frame.crc = crc8((uint8_t *)&frame, 3);
	frame.ack = 0;						

	spi_cs(0); // 拉低CS，开始通信
	HAL_SPI_Transmit(&hspi1, (uint8_t *)&frame, 4, 1000); // 发送数据帧，减1是为了排除ACK字段
	HAL_SPI_Receive(&hspi1, (uint8_t *)&frame.ack, 1, 1000); // 接收ACK响应
	spi_cs(1); // 拉高CS，结束通信

	return frame.ack; // 返回ACK响应
}
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

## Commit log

2026-04-04 添加 .gitignore 文件和更新 README.md
2026-04-04 添加 30M 任意波形发生器技术规格书文档
2026-04-06 技术规格书初始架构；更改电源要求；添加部分数据手册
2026-04-07 FPGA选型决策
2026-04-11 添加一些 LICENSE
2026-04-20 1、简化系统框图 2、完善模拟前端架构 3、确定了一些器件的选型
2026-04-22 1、添加时钟设计 2、添加AI辅助声明
2026-04-22 FPGA选型决策 - 1、添加Xilinx两款信号的对比 2、添加一些决策前提
2026-04-23 更新文档：修改时钟特性、添加多功能I/O特性，完善接口定义
2026-04-23 硬件设计文档初始架构 Assisted-by: DeepSeek - 文档框架
2026-04-24 USB接口硬件设计
2026-04-24 软件设计文档框架 Assisted-by: DeepSeek - 文档框架
2026-04-25 MCU最小系统设计
2026-04-25 MCU<->FPGA通信协议初步设计
2026-04-25 1、将板间接口拆为单独的文档 2、调整电源分配 <!-- Assisted-by: DeepSeek - 文档框架、文档审核 --> Co-authored-by: Copilot <copilot@github.com>
2026-04-25 完成EEPROM，人机接口，调试接口初步设计
2026-04-25 1、完成板卡概述 2、修改USB-ESD芯片选型
2026-04-25 1、修复硬件设计文档(控制板)-调试接口章节的一些错误 2、修改硬件设计文档(控制板)部分格式与叙述
2026-04-25 移除总览错误放置的模块
2026-04-27 v1.0/v2.0 放弃本地控制决策记录 Assisted-by: DeepSeek
2026-04-27 删除本地交互部分
2026-04-29 修改DAC选型 Assisted-by: DeepSeek - 文档框架
2026-04-30 绘制原理图符号库
    [FPGA.kicad_sch, analog_board.kicad_pcb, analog_board.kicad_sch]
2026-04-30 修改DAC选型
2026-05-01 调整文档格式
2026-05-01 完成FPGA与DAC接口
2026-05-02 自动化工作流-README.md动态渲染
2026-05-03 电源轨功耗计算
2026-05-04 完成DAC电路设计
2026-05-05 修改电源设计
2026-05-06 补充模拟板电源设计细节
2026-05-06 1、FPGA最小系统原理图 2、DAC电路原理图 3、FPGA DAC 预布局
    [DAC.kicad_sch, FPGA.kicad_sch, FPGA_Config.kicad_sch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]
2026-05-07 模拟板文档添加 FPGA DAC 原理图截图
2026-05-09 1、添加滤波器设计笔记 2、完成重构滤波器设计
2026-05-09 滤波器拓扑结构选型
2026-05-11 完成差分转单端电路设计
2026-05-12 feat: 滤波器&差分转单端电路原理图
    [DAC.kicad_sch, FPGA.kicad_sch, FPGA_Config.kicad_sch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]
2026-05-13 feat：时钟电路原理图
    [Clock.kicad_sch, DAC.kicad_sch, FPGA.kicad_sch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]
2026-05-13 docs：时钟电路设计
2026-05-13 feat：完成模拟板板间接口设计
    [DAC.kicad_sch, FPGA.kicad_sch, analog_board.kicad_sch]
2026-05-13 debug：修正 反向DC-DC匹配网络元件值；修正板间接口文档电源连接器定义
2026-05-14 docs:：修正公式显示问题；调整图片格式
2026-05-14 docs：控制板电源设计
2026-05-15 feat：模拟板电源 原理图设计
    [.kicad_sch, Clock.kicad_sch, DAC.kicad_sch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]
2026-05-15 fixbug：修复 1.0V DCDC错误；根据PCB布局修改DCDC输入/输出电解电容参数
    [power.kicad_sch]
2026-05-15 feat：重构滤波器预布局
    [DAC.kicad_sch, analog_board.kicad_pcb]
2026-05-15 feat：原理图添加测试点
    [DAC.kicad_sch, FPGA.kicad_sch, power.kicad_sch]
2026-05-15 docs：修改测试点位置
2026-05-15 feat：差分转单端预布局
    [DAC.kicad_sch, analog_board.kicad_pcb]
2026-05-15 feat：共模反馈电路预布局
    [analog_board.kicad_pcb]
2026-05-15 feat：时钟电路预布局
    [Clock.kicad_sch, DAC.kicad_sch, FPGA.kicad_sch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]
2026-05-16 feat：模拟板电源预布局
    [analog_board.kicad_pcb]
2026-05-17 feat：FPGA-DAC接口布线
    [.kicad_sch, analog_board.kicad_pcb]
2026-05-17 feat：FPGA布线
    [analog_board.kicad_pcb]
2026-05-17 feat：DAC布线
    [analog_board.kicad_pcb]
2026-05-17 docs：完成PCB布局布线指南
2026-05-17 feat：时钟电路布线
    [analog_board.kicad_pcb]
2026-05-18 feat：重构滤波器布局，共模反馈布局
    [analog_board.kicad_pcb]
2026-05-18 feat：差分转单端电路布线
    [analog_board.kicad_pcb]
2026-05-18 feat：电源布线完成
    [analog_board.kicad_pcb]
2026-05-18 feat：根据PCB微调原理图
    [Clock.kicad_sch, DAC.kicad_sch, FPGA.kicad_sch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]
2026-05-21 feat：添加缝合过孔
    [power.kicad_sch]
2026-05-22 feat：添加平衡铜
    [Clock.kicad_sch, DAC.kicad_sch, analog_board.csv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]
2026-05-23 docs：MCU最小系统原理图
2026-05-23 feat：MCU最小系统，USB接口原理图
    [MCU.kicad_sch, control_board.kicad_sch]
2026-05-23 docs：USB接口、EEPROM原理图
2026-05-23 feat：EEPROM原理图
    [MCU.kicad_sch, control_board.kicad_sch]
2026-05-24 docs：调整 ADR-002 描述
2026-05-24 docs：根据引脚位置修改调试接口线序
2026-05-26 feat：控制板电源原理图
    [MCU.kicad_sch, POWER.kicad_sch]
2026-05-26 feat：±7V电源移动到控制板（原理图修改）
    [power.kicad_sch]
2026-05-27 feat：MCU最小系统预布局
    [control_board.kicad_pcb]
2026-05-27 debug：蜂鸣器驱动电路；debug LED；电源输出排针
    [MCU.kicad_sch, POWER.kicad_sch, control_board.kicad_sch]
2026-05-27 feat：调试接口预布局；USB接口预布局
    [control_board.kicad_pcb]
2026-05-27 feat：电源预布局
    [control_board.kicad_pcb]
2026-05-27 feat：整版布局
    [control_board.kicad_pcb]
2026-05-27 feat：MCU、USB、EEPROM、Debug布线
    [control_board.kicad_pcb]
2026-05-27 feat：电源布线
    [control_board.kicad_pcb]
2026-05-31 feat：DCDC移至控制板
    [FPGA_Config.kicad_sch, analog_board.kicad_pcb, analog_board.kicad_sch]
2026-05-31 debug：输出10MHz时钟线宽修正为5.96mm(50Ω)
    [analog_board.kicad_pcb]
2026-05-31 feat：导出模拟板 BOM
    [Clock.kicad_sch, DAC.kicad_sch, analog_board.csv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]
2026-06-06 docs：±7V DC-DC 移至控制板
2026-06-06 license：修改版权声明
2026-06-06 docs：修改项目状态
2026-06-14 feat：创建工程
2026-06-15 feat：定义顶部接口
2026-06-15 feat：生成时钟发生器寄存器值
2026-06-16 docs：更新文档状态
2026-06-16 docs：模拟板MVP软件框图
2026-06-18 docs：添加 SCPI-1999 技术规范文档
2026-06-18 docs：完善软件设计文档概述部分
2026-06-19 docs：修正文档编号
2026-06-20 docs：将板间通信方式从命令式改为寄存器映射式
2026-06-21 feat：模拟板 MVP 配置通过
2026-06-21 docs:：规定通信协议内容
2026-06-22 docs：定义寄存器映射总表
2026-06-22 feat：创建MCU工程
2026-06-23 feat：MCU最小系统测试程序
2026-06-24 feat：FPGA最小系统测试程序
2026-06-27 feat：FPGA_Clock_test Project
2026-06-28 feat：完成时钟生成、系统控制模块
2026-06-29 feat：DCO域异步复位同步释放
2026-06-29 feat：添加波形生成模块，实例化DDS II IP核；修正系统时钟频率参数
2026-07-01 feat：sys_ctrl 仿真
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2026-07-05 docs：模拟板MVP调试笔记 - 目视检查 Assisted-by: DeepSeek - 文档框架
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2026-07-17 feat: DAC 控制 SPI 接口
2026-07-18 debug: 将 wave_generation 输出修改为有符号数
2026-07-18 feat: 顶层模块仿真 - 最小可行系统（sin_DDS、sys_ctrl、dac_interface）
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2026-07-20 docs: 添加 DAC 寄存器映射
2026-07-20 debug: 修复仓库结构显示问题
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2026-07-24 docs: 添加 spi 时序图
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2026-07-28 debug：SPI 数据格式修正为小端序
2026-07-29 docs：修正SPI时序图数据部分为大端序
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2026-08-01 debug：将代码存放目录修正为README描述的目录
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2026-08-02 debug：幅值控制缩放因子修正为32768
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2026-08-04 feat：按照顶层 README 重新存放工程；移除 FreeRTOS；修复 firmware 拼写错误
    [ArbWave30.ioc, main.h]
2026-08-04 debug：修复 firmware 拼写错误
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2026-08-09 docs：添加 ADR-005: 差分转单端电路拓扑选型 Assisted-by: DeepSeek - 文档框架
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2026-08-18 feat：更新 README SCPI 部分
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2026-08-23 feat：添加 scpi-parser 内容，编写 scpi 接口函数
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2026-08-24 feat：添加 IEEE 488.2 公共命令，SYSTem子命令
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2026-08-27 docs：修复 README 中markdown语法错误
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2026-08-28 debug：1、补充控制寄存器 2、修复频率控制字计算溢出问题
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2026-08-30 feat：修复目录名拼写错误
2026-08-30 feat：修复仓库目录树显示问题，更新进度
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2026-09-08 debug：修复 CH1 反向问题
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2026-09-08 debug：修复对称度计算溢出问题
2026-09-08 debug：修复方波生成时序收敛问题
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2026-09-10 debug：修正 SPI TX 寄存器赋值时机
    [spi_slave.v]
2026-09-10 debug：修复 reg_block->wave_generation 路径过长问题
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2026-09-16 debug：修正校准逻辑
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2026-09-18 debug：修正原理图部分错误
    [Clock.kicad_sch, DAC.kicad_sch, Power_Filter.kicad_sch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]
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2026-09-20 debug：修正 PCB 部分错误
    [analog_board.kicad_pcb]
2026-09-21 debug：修复原理图部分问题
    [MCU.kicad_sch, POWER.kicad_sch, control_board.kicad_sch]
2026-09-21 debug：修改 PCB 部分问题
    [MCU.kicad_sch, control_board.kicad_pcb]
2026-09-21 feat：给出BOM表
    [MCU.kicad_sch, POWER.kicad_sch, control_board.xlsx]
2026-09-22 feat：BOM导出
    [Clock.kicad_sch, DAC.kicad_sch, analog_board.csv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]
2026-09-25 docs：修正接口文档笔误，更新SCPI手册状态
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2026-10-13 docs：添加已知问题
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
